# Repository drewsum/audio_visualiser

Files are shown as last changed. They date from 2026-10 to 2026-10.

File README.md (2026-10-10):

# Audio Visualizer

## Hardware

A graphical EQ display, based on a dsPIC33AK256MPS103 digital signal controller.

## Continuous integration

GitHub Actions checks every KiCad project under `hdw/` automatically (`.github/workflows/hardware.yml`):

| Job | What it does |
|---|---|
| Repo hygiene | Fails on committed backups, lock files or caches, and on files not saved by KiCad 10.0. Checks that each project's schematic PDF (`<project>.pdf`) is committed and was re-plotted after the last schematic change. |
| ERC / DRC / libraries | Runs ERC, and DRC with schematic parity. Also checks that every symbol and footprint library resolves on a clean machine (project lib tables must use `${KIPRJMOD}`). For projects with a project library, checks that every placed symbol, footprint and 3D model comes from it. |
| Visual diff | On every run, renders changed schematic pages and PCB layers against the previous commit or PR base (red = removed, green = added). The result is a single `visual-diff.html` artifact that opens directly in the browser; the run summary links to it. |

Per-project settings live in `hdw/ci-config.json`. Each of `erc`, `drc`, `libraries`, `project_lib` and `pdf` is `enforce` (fail the build), `report` (annotate only) or `off`. `project_lib` also needs `project_lib_dir` (relative to the project folder, e.g. `"../../../project_lib"`): the lib tables may only point into that folder, every placed symbol and board footprint (and every symbol's Footprint field) must exist in those libraries, and every 3D model path must resolve to a file inside it. ERC/DRC items excluded in KiCad are not counted. Personal libraries that aren't in this repo are listed under `external_libraries` and cloned by CI under the same nicknames.

To run the checks locally:

```sh
KICAD_CLI="C:/Program Files/KiCad/10.0/bin/kicad-cli.exe" python tools/ci/kicad_ci.py check hdw/DSP_board/rev_a/Audio_Visualiser_DSP
python tools/ci/kicad_ci.py hygiene
```

Fab outputs (schematic/PCB PDFs, Gerbers + drill, IPC-D-356, BOM, pick-and-place, STEP and renders) are built manually:

```sh
python tools/ci/kicad_ci.py outputs hdw/DSP_board/rev_a/Audio_Visualiser_DSP --out fab-out --label <version>
```

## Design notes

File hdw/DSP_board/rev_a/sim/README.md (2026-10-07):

# Audio Signal Chain Simulation

## Trace Legend

| Color  | Signal |
|---|---|
| Red | Time Domain RCA Audio Signal (1.8Vpp) |
| Green  | Frequency Domain RCA Audio Signal |
| Blue | Time/Frequency Domain ADC Audio Signal |
| Orange | Time Domain Speaker Level Audio Signal (12Vpp) |
| Yellow | Frequency Domain Speaker Level Audio Signal |

## RCA Input

### Time Domain
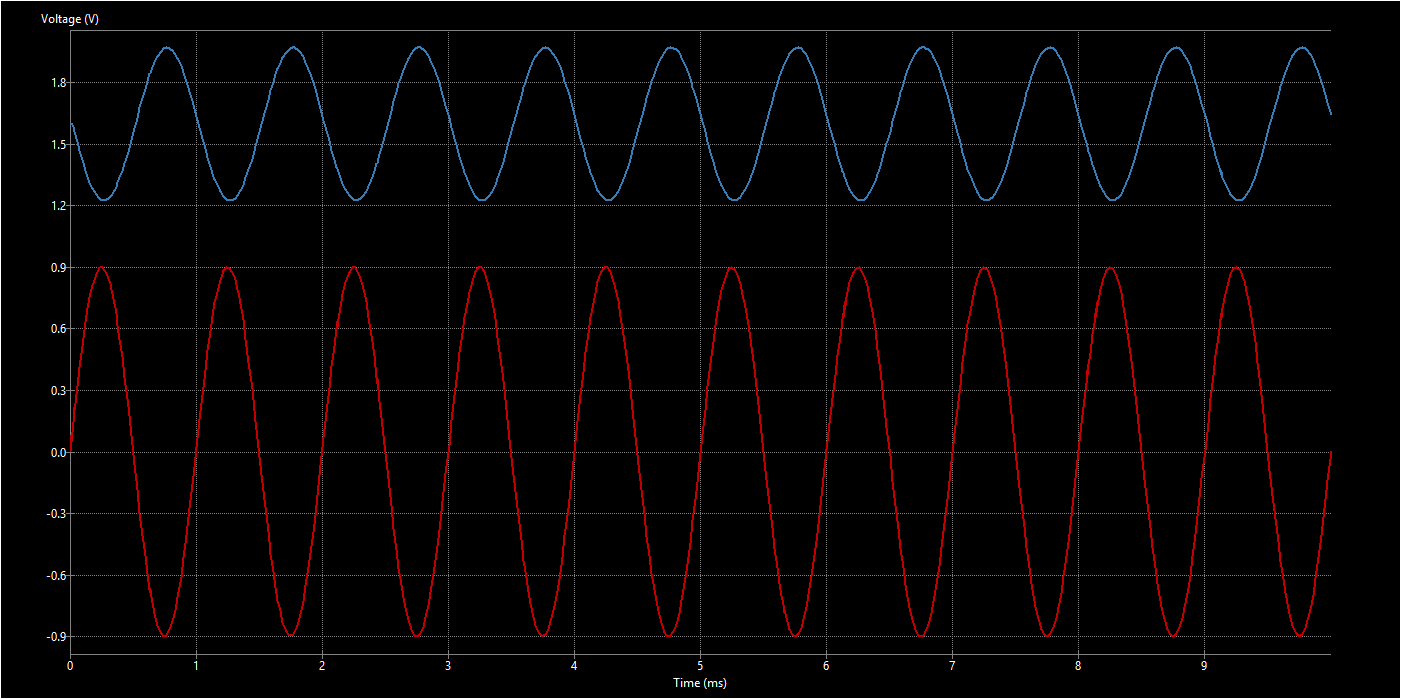
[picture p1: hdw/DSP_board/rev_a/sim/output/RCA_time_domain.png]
RCA Time Domain


### Frequency Domain
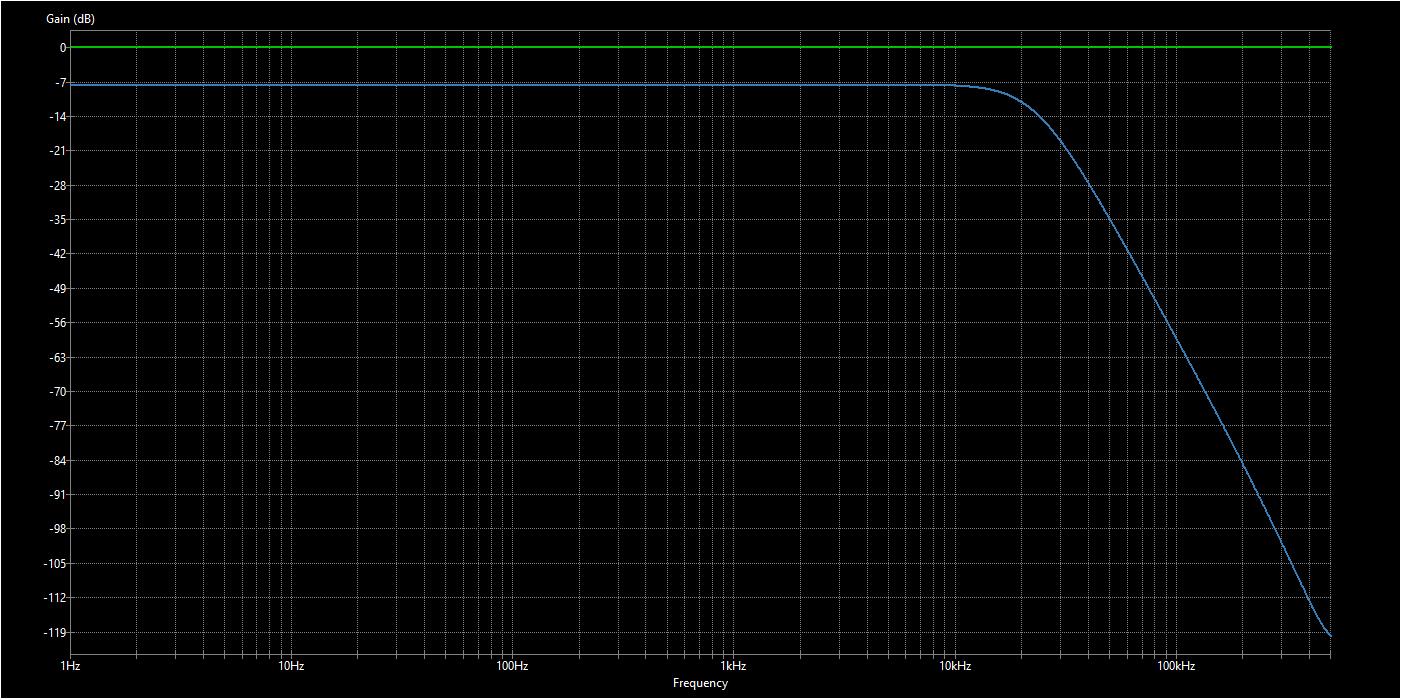
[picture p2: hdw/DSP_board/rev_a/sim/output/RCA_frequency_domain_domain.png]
RCA Frequency Domain


## Speaker Level Input

### Time Domain
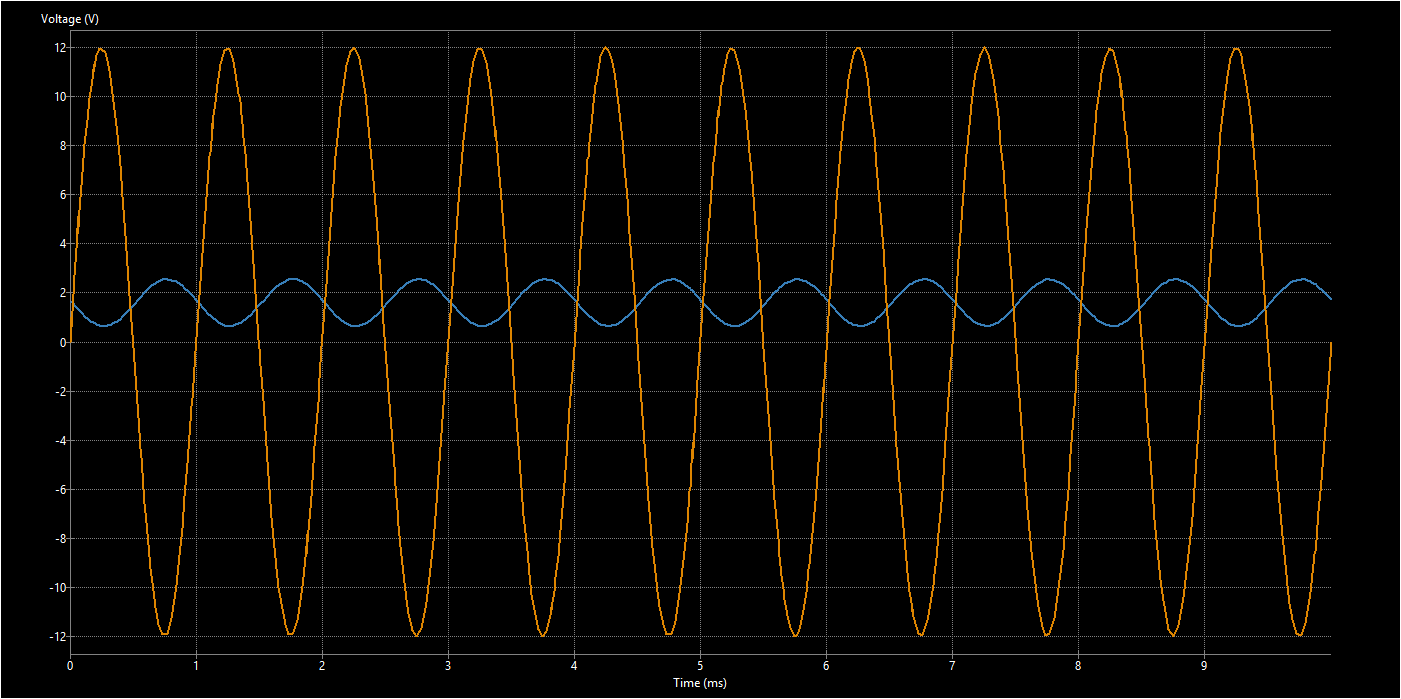
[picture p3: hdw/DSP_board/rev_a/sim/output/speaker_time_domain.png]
Speaker Time Domain


### Frequency Domain
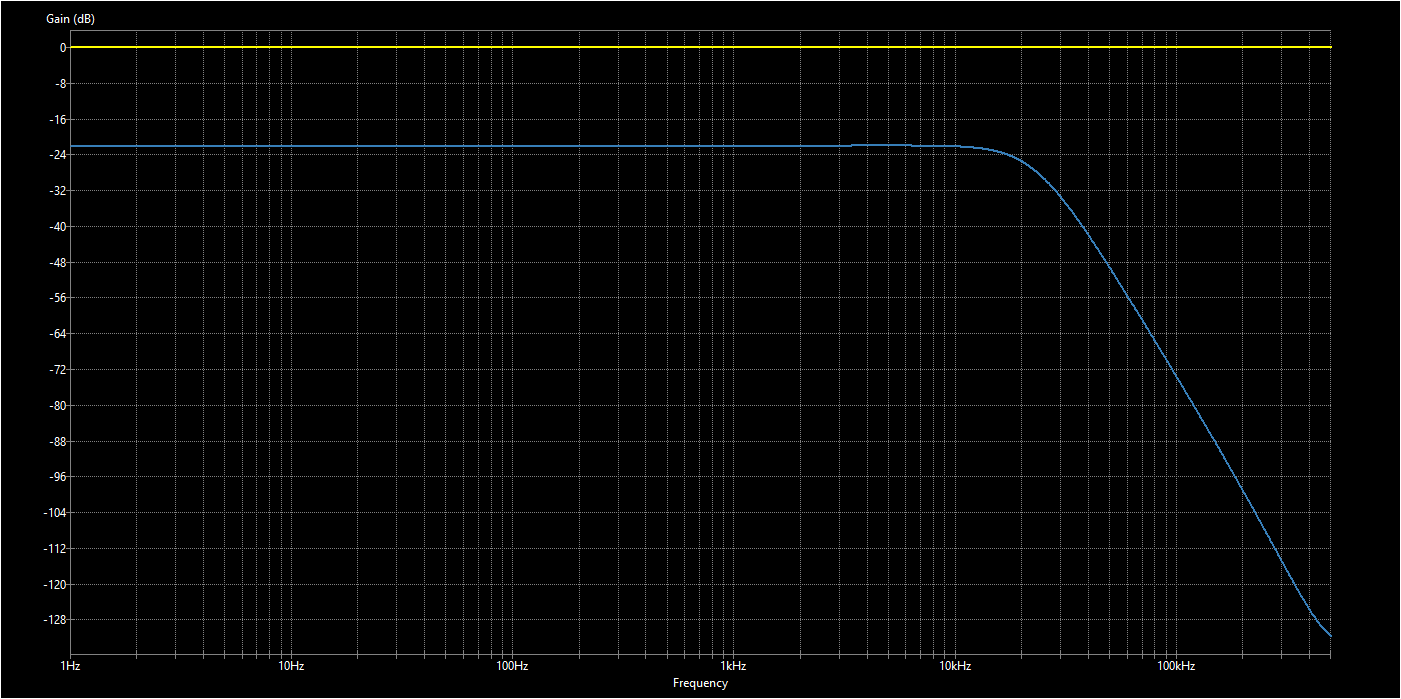
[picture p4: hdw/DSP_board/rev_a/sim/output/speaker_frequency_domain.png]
Speaker Frequency Domain


All sims were run with digipot code = 128 (wiper -> midpoint), meaning the PGAs are not attenuating or amplifying the signal at all, merely inverting

The signal chain employs the following vendor spice models:
* BAT54SW.lib
* MCP4451.lib
* MCP6021_MCP6024.lib
* MCP6N11.lib
* REF35.lib
* SD15C.lib
* TS3A24159.lib

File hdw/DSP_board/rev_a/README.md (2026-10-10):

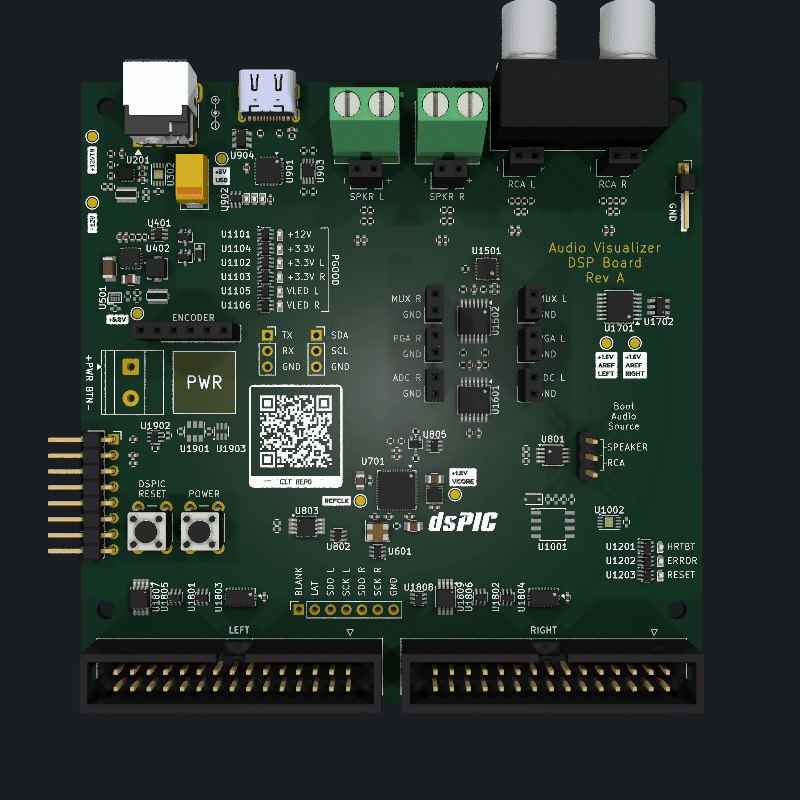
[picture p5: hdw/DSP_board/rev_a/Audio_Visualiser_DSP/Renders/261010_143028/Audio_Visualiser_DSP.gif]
Render


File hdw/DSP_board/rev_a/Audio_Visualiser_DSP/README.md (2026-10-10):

Render

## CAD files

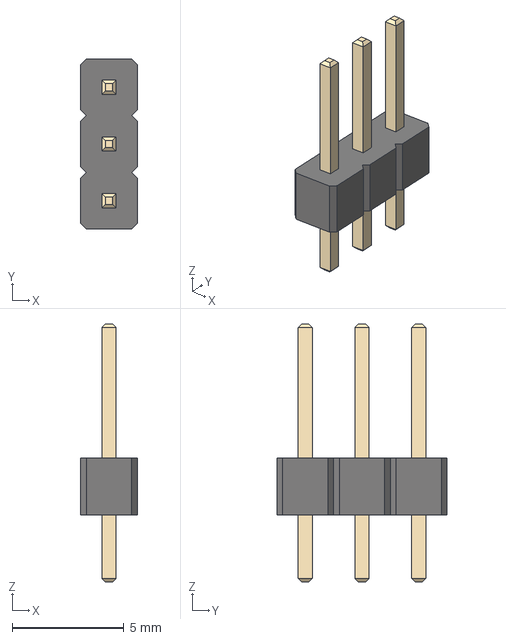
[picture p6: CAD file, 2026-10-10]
hdw/project_lib/3d_models/PinHeader_1x03_P2.54mm_Vertical.step
2.54 x 7.62 x 11.5 mm

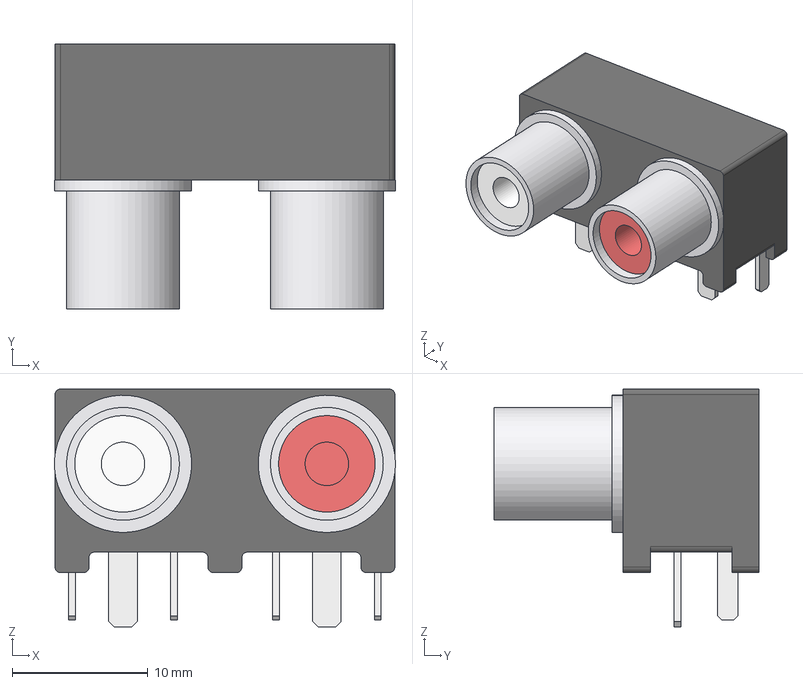
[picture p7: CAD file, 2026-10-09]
hdw/project_lib/3d_models/Switchcraft_PJRAN2X1U01X.step
25.1 x 19.5 x 17.5 mm
housing
insert_A_red
insert_B_white
terminals

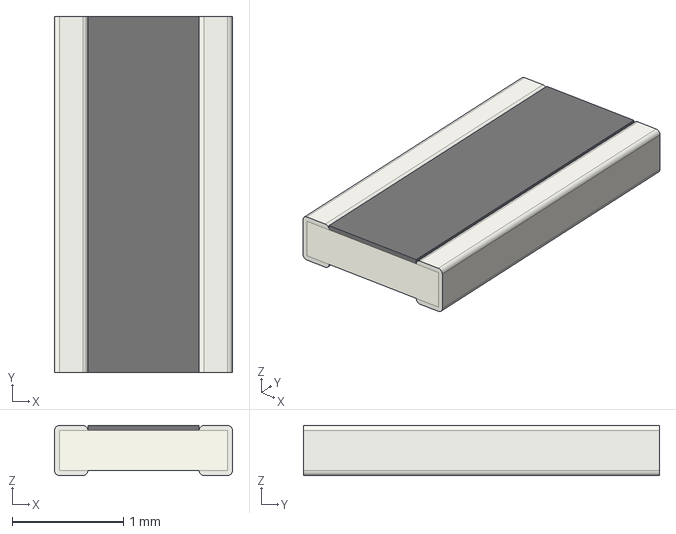
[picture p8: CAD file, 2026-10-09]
hdw/project_lib/3d_models/R_0612_1632Metric.step
1.60 x 3.20 x 0.45 mm

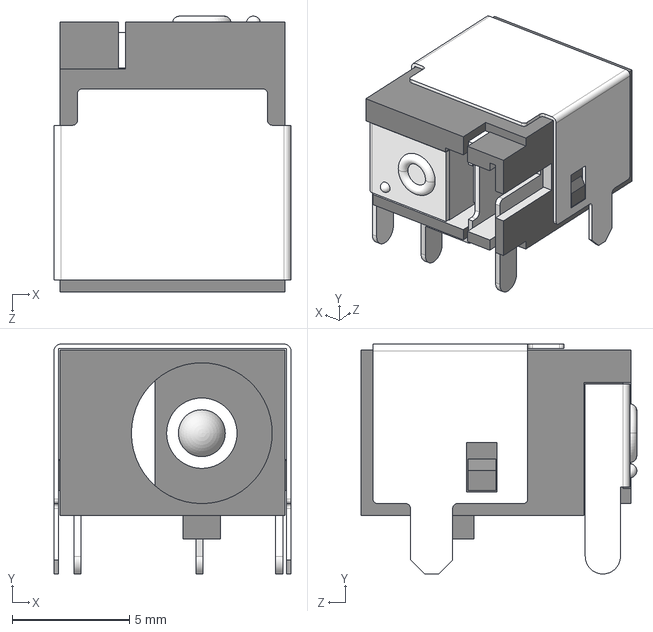
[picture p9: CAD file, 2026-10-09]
hdw/project_lib/3d_models/SameSky_PJ-051AH.step
10.1 x 9.80 x 11.8 mm

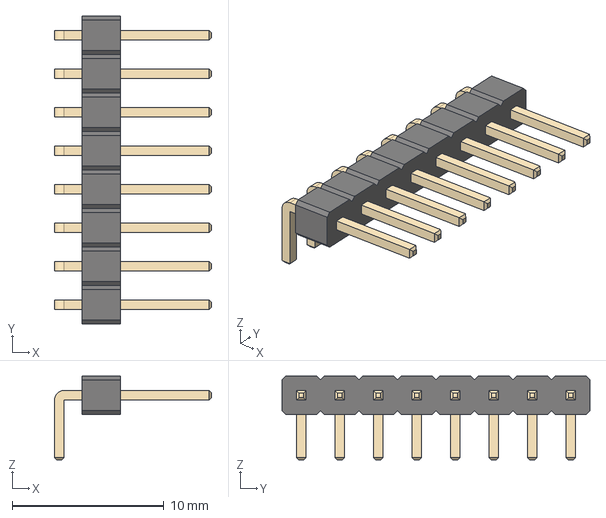
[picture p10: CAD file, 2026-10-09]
hdw/project_lib/3d_models/PinHeader_1x08_P2.54mm_Horizontal.step
10.4 x 20.3 x 5.54 mm

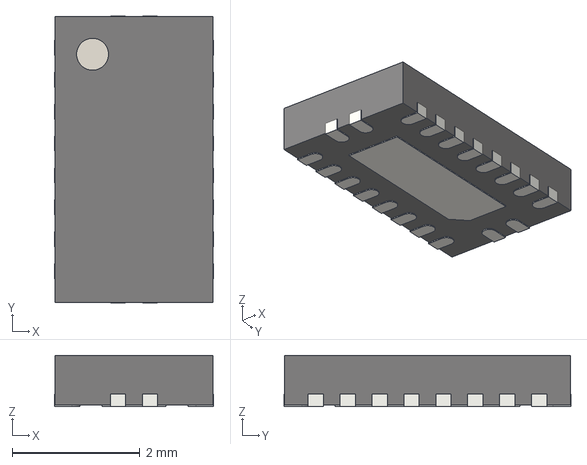
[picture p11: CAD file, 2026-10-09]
hdw/project_lib/3d_models/WQFN-20-1EP_2.5x4.5mm_P0.5mm_EP1x2.9mm.step
2.50 x 4.50 x 0.8 mm

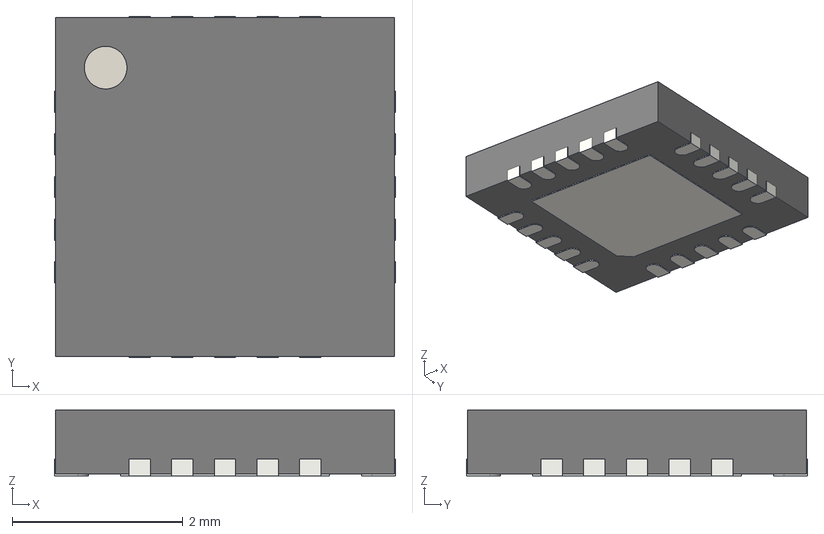
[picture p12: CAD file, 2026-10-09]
hdw/project_lib/3d_models/QFN-20-1EP_4x4mm_P0.5mm_EP2.5x2.5mm.step
4.00 x 4.00 x 0.77 mm

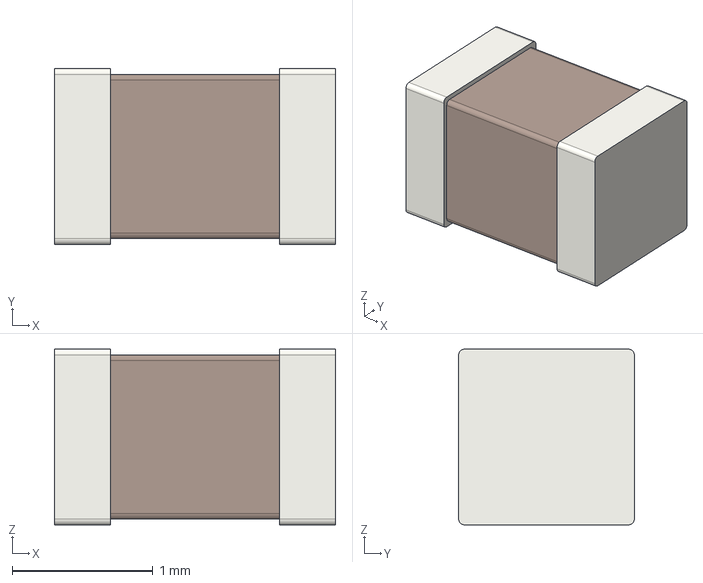
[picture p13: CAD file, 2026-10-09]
hdw/project_lib/3d_models/C_0805_2012Metric.step
2.00 x 1.25 x 1.25 mm

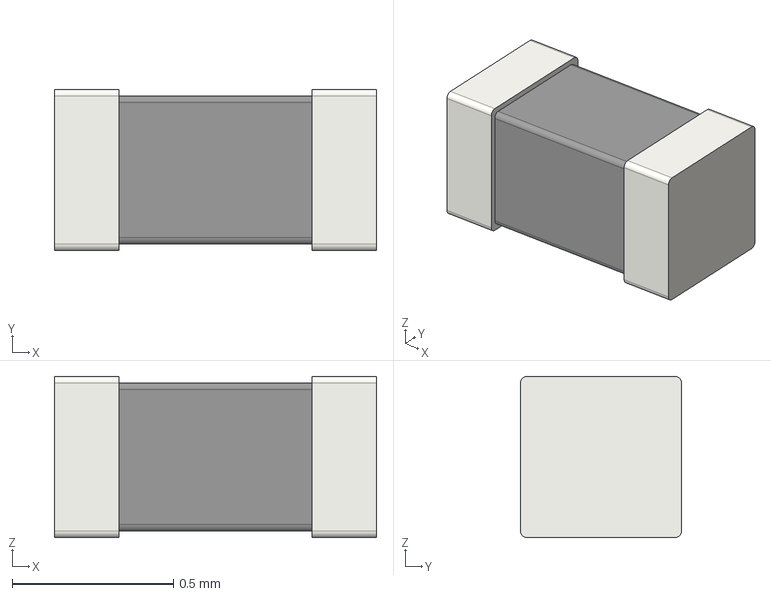
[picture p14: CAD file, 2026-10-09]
hdw/project_lib/3d_models/L_0402_1005Metric.step
1.00 x 0.5 x 0.5 mm

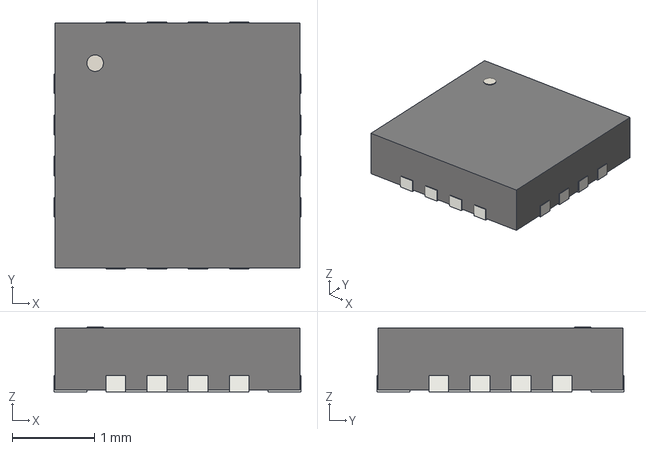
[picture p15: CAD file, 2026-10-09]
hdw/project_lib/3d_models/QFN-16-1EP_3x3mm_P0.5mm_EP1.7x1.7mm.step
3.00 x 3.00 x 0.785 mm

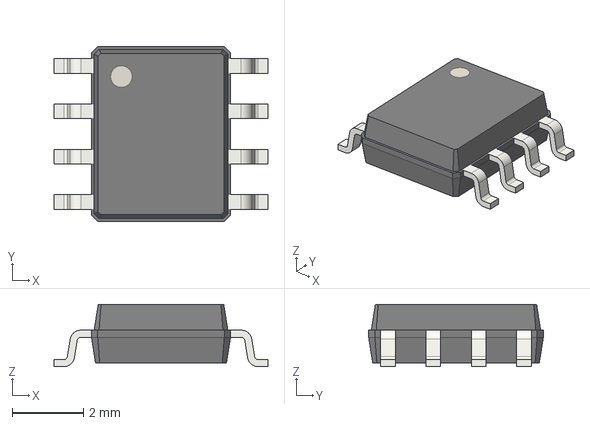
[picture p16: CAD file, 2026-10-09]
hdw/project_lib/3d_models/SOIC-8_3.9x4.9mm_P1.27mm.step
6.00 x 4.90 x 1.75 mm

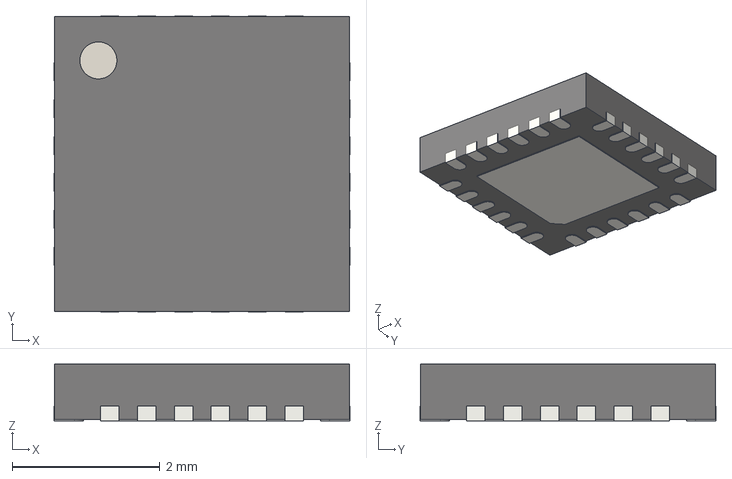
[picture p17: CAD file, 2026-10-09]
hdw/project_lib/3d_models/QFN-24-1EP_4x4mm_P0.5mm_EP2.6x2.6mm.step
4.00 x 4.00 x 0.77 mm

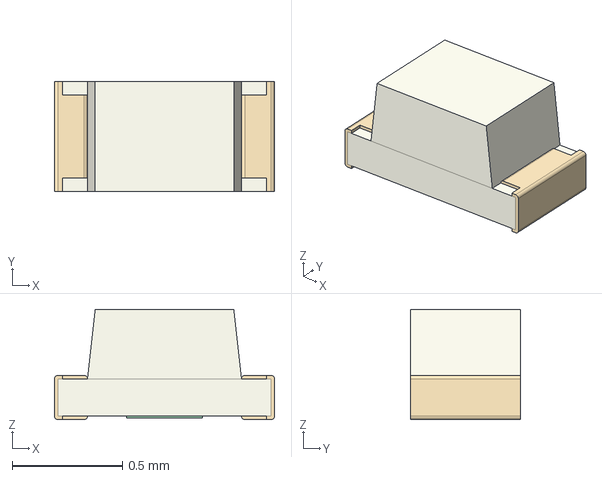
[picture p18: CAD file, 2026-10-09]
hdw/project_lib/3d_models/LED_0402_1005Metric.step
1.00 x 0.5 x 0.5 mm

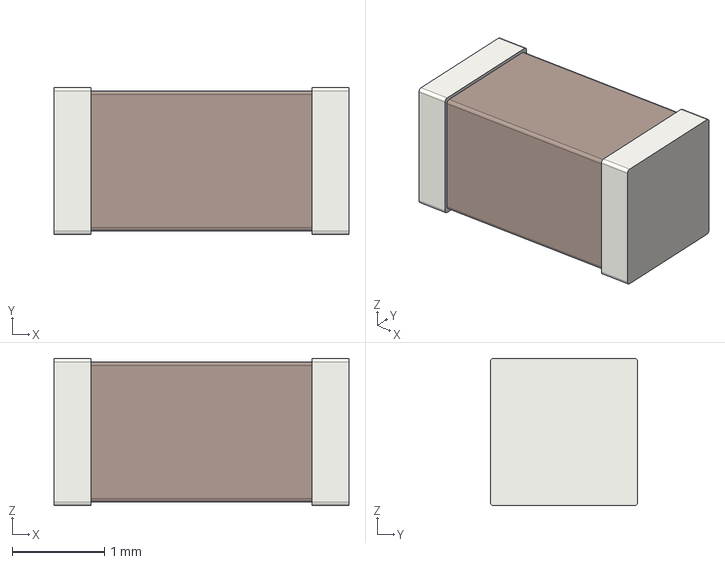
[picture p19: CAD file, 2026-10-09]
hdw/project_lib/3d_models/C_1206_3216Metric.step
3.20 x 1.60 x 1.60 mm

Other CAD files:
hdw/project_lib/3d_models/C_0402_1005Metric.step
hdw/project_lib/3d_models/Abracon_ASE_3.2x2.5mm.step
hdw/project_lib/3d_models/TI_TPS259474_RPW0010A.step
hdw/project_lib/3d_models/JAE_DX07S016JA1R1500.step
hdw/project_lib/3d_models/CP_EIA-7343-43_Kemet-X.step
hdw/project_lib/3d_models/DFN-8-1EP_3x2mm_P0.5mm_EP1.3x1.5mm.step
hdw/project_lib/3d_models/D_SMA.step
hdw/project_lib/3d_models/D_SOD-323.step
hdw/project_lib/3d_models/D_SOD-323F.step
hdw/project_lib/3d_models/IDC-Header_2x15_P2.54mm_Vertical.step
hdw/project_lib/3d_models/L_Vishay_IHLP-1212.step
hdw/project_lib/3d_models/L_Wuerth_PMCI-252012.step
hdw/project_lib/3d_models/PinHeader_1x01_P2.54mm_Horizontal.step
hdw/project_lib/3d_models/PinSocket_1x02_P2.54mm_Vertical.step
hdw/project_lib/3d_models/PinSocket_1x03_P2.54mm_Vertical.step
hdw/project_lib/3d_models/PinSocket_1x06_P2.54mm_Vertical.step
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

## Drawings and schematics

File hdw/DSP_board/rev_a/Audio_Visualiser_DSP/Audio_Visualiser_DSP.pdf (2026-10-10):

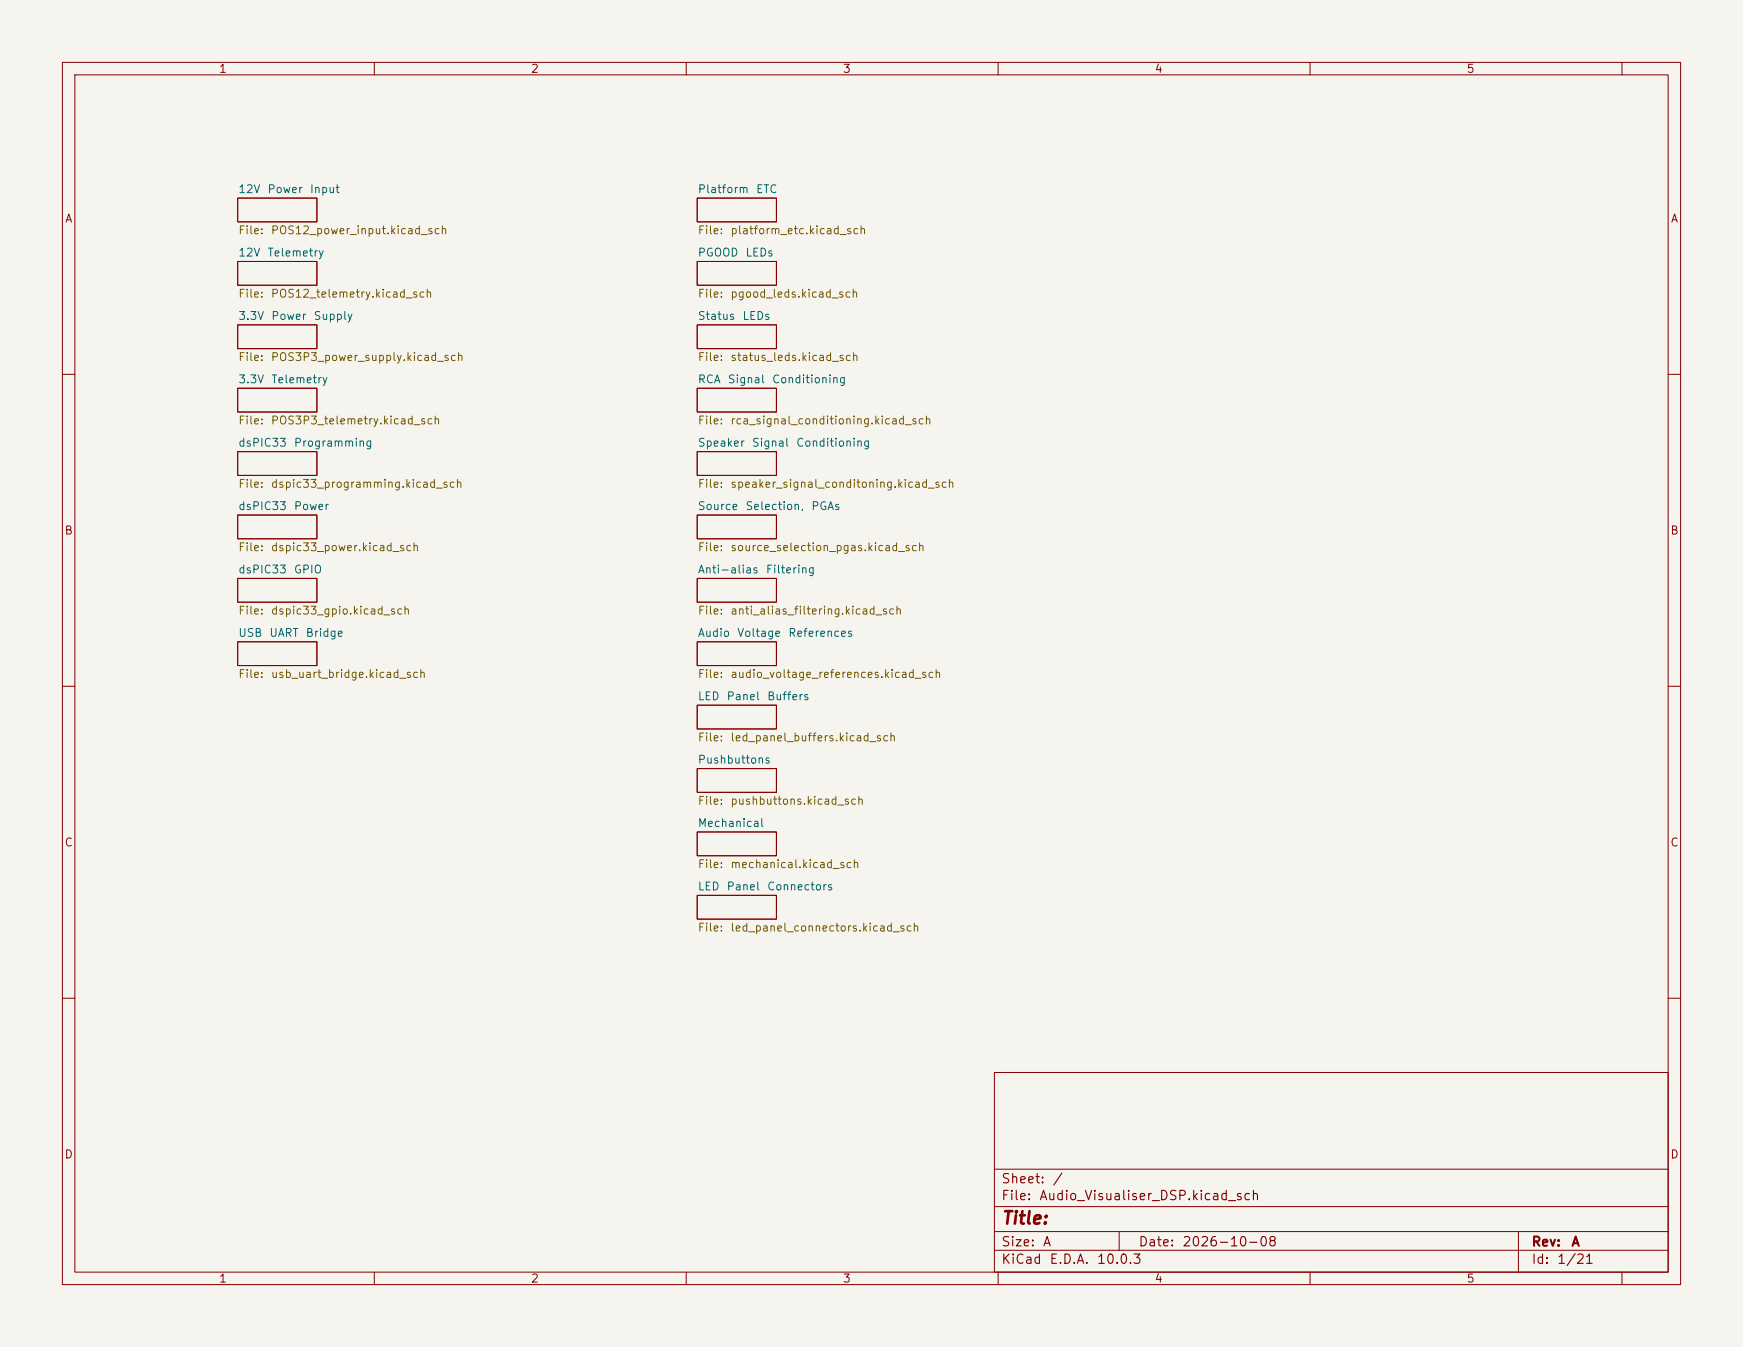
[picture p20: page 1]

Status LEDs File: status_leds.kicad_sch RCA Signal Conditioning

File: speaker_signal_conditoning.kicad_sch Source Selection, PGAs File: source_selection_pgas.kicad_sch

File: dspic33_gpio.kicad_sch USB UART Bridge

Audio Voltage References File: audio_voltage_references.kicad_sch Pushbuttons File: pushbuttons.kicad_sch

LED Panel Buffers File: led_panel_buffers.kicad_sch

LED Panel Connectors File: led_panel_connectors.kicad_sch

Size: A | Rev: A
KiCad E.D.A. 10.0.3 | Id: 1/21

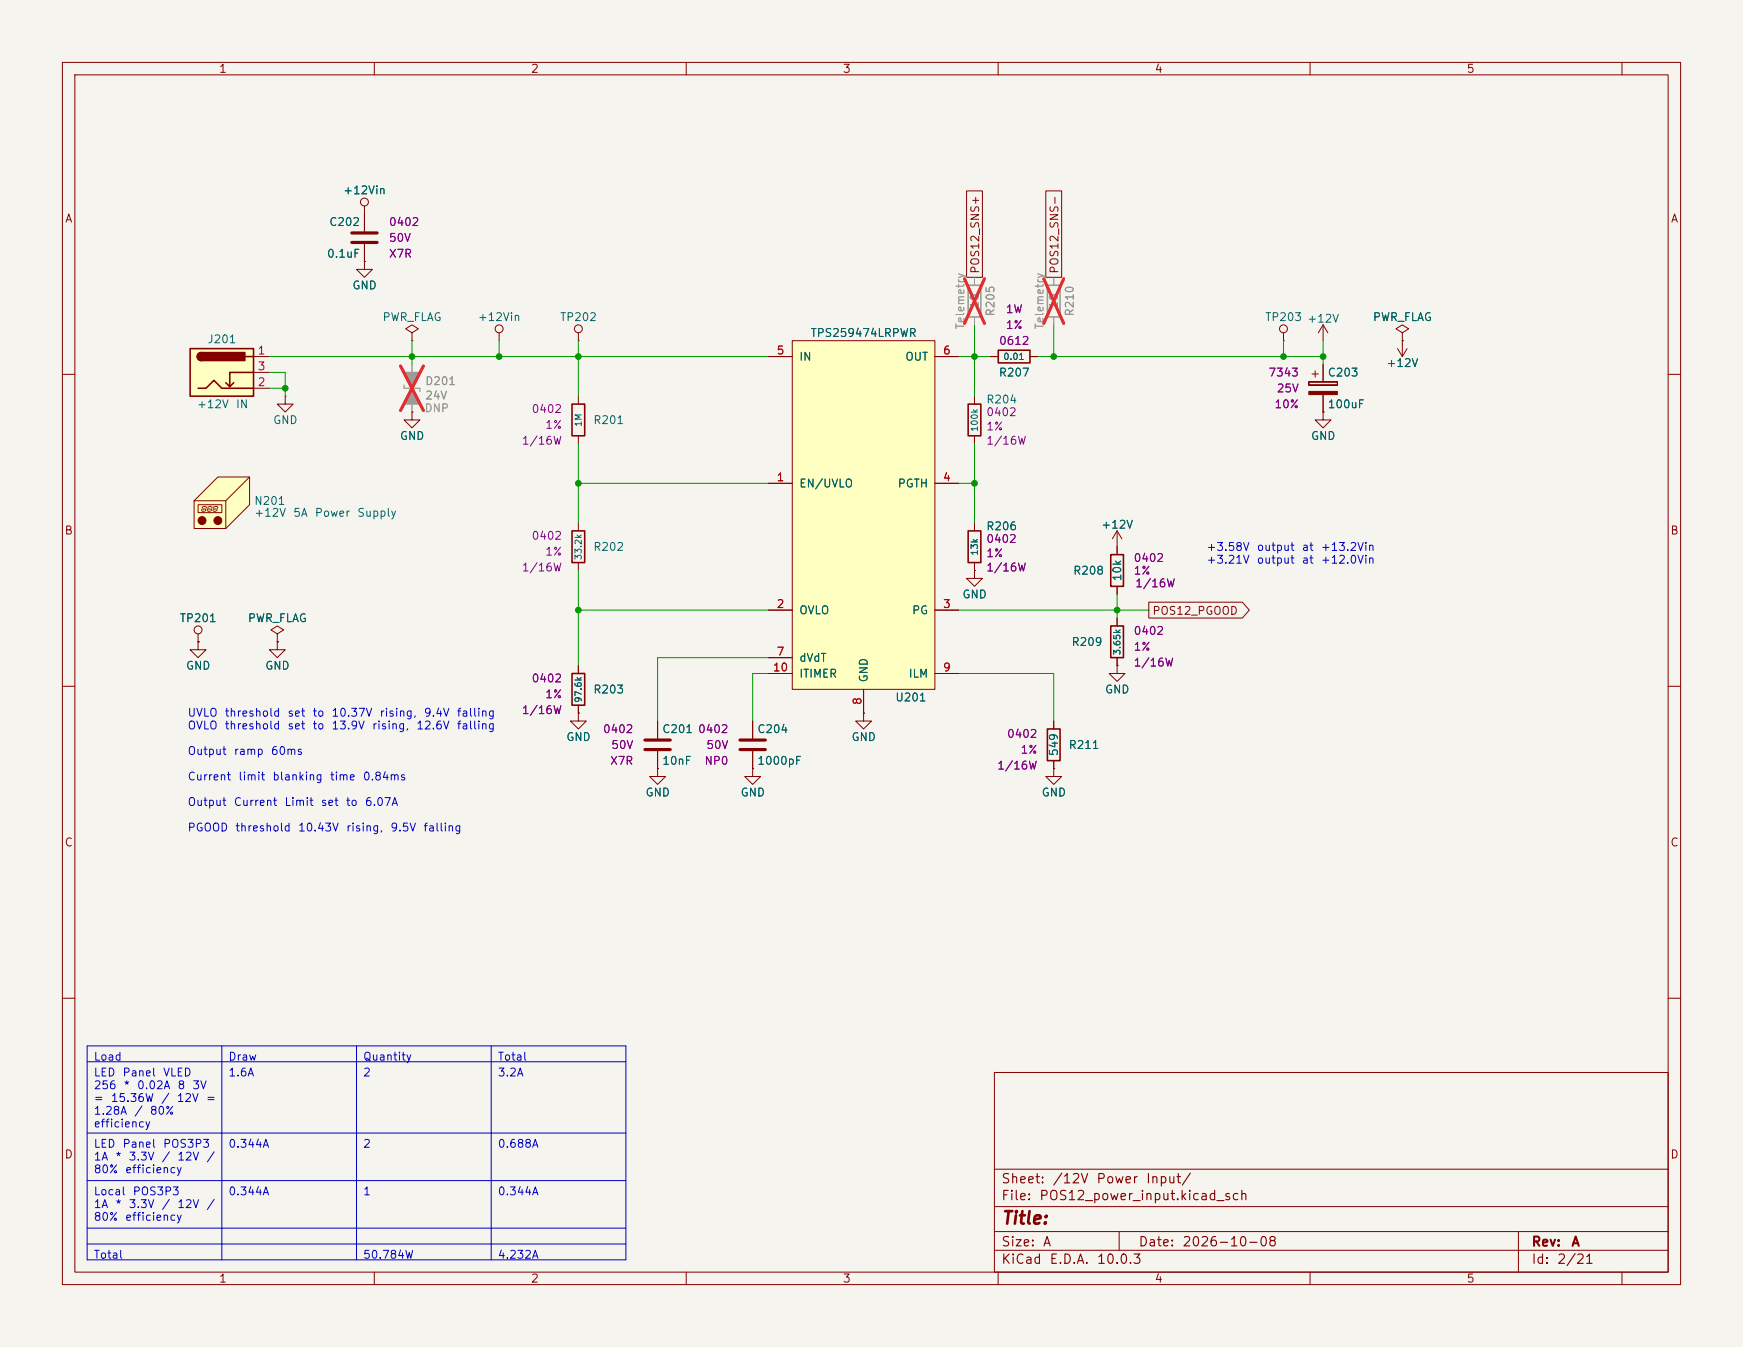
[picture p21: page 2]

Output ramp 60ms Current limit blanking time 0.84ms Output Current Limit set to 6.07A PGOOD threshold 10.43V rising, 9.5V falling D201

+3.58V output at +13.2Vin +3.21V output at +12.0Vin UVLO threshold set to 10.37V rising, 9.4V falling OVLO threshold set to 13.9V rising, 12.6V falling

Load | Draw | Quantity | Total LED Panel VLED
efficiency 256 * 0.02A 8 3V = 15.36W / 12V = 1.28A / 80% | 1.6A | 2 | 3.2A

LED Panel POS3P3 80% efficiency 1A * 3.3V / 12V / | 0.344A | 2 | 0.688A

Local POS3P3 80% efficiency 1A * 3.3V / 12V / | 0.344A | 1 | 0.344A

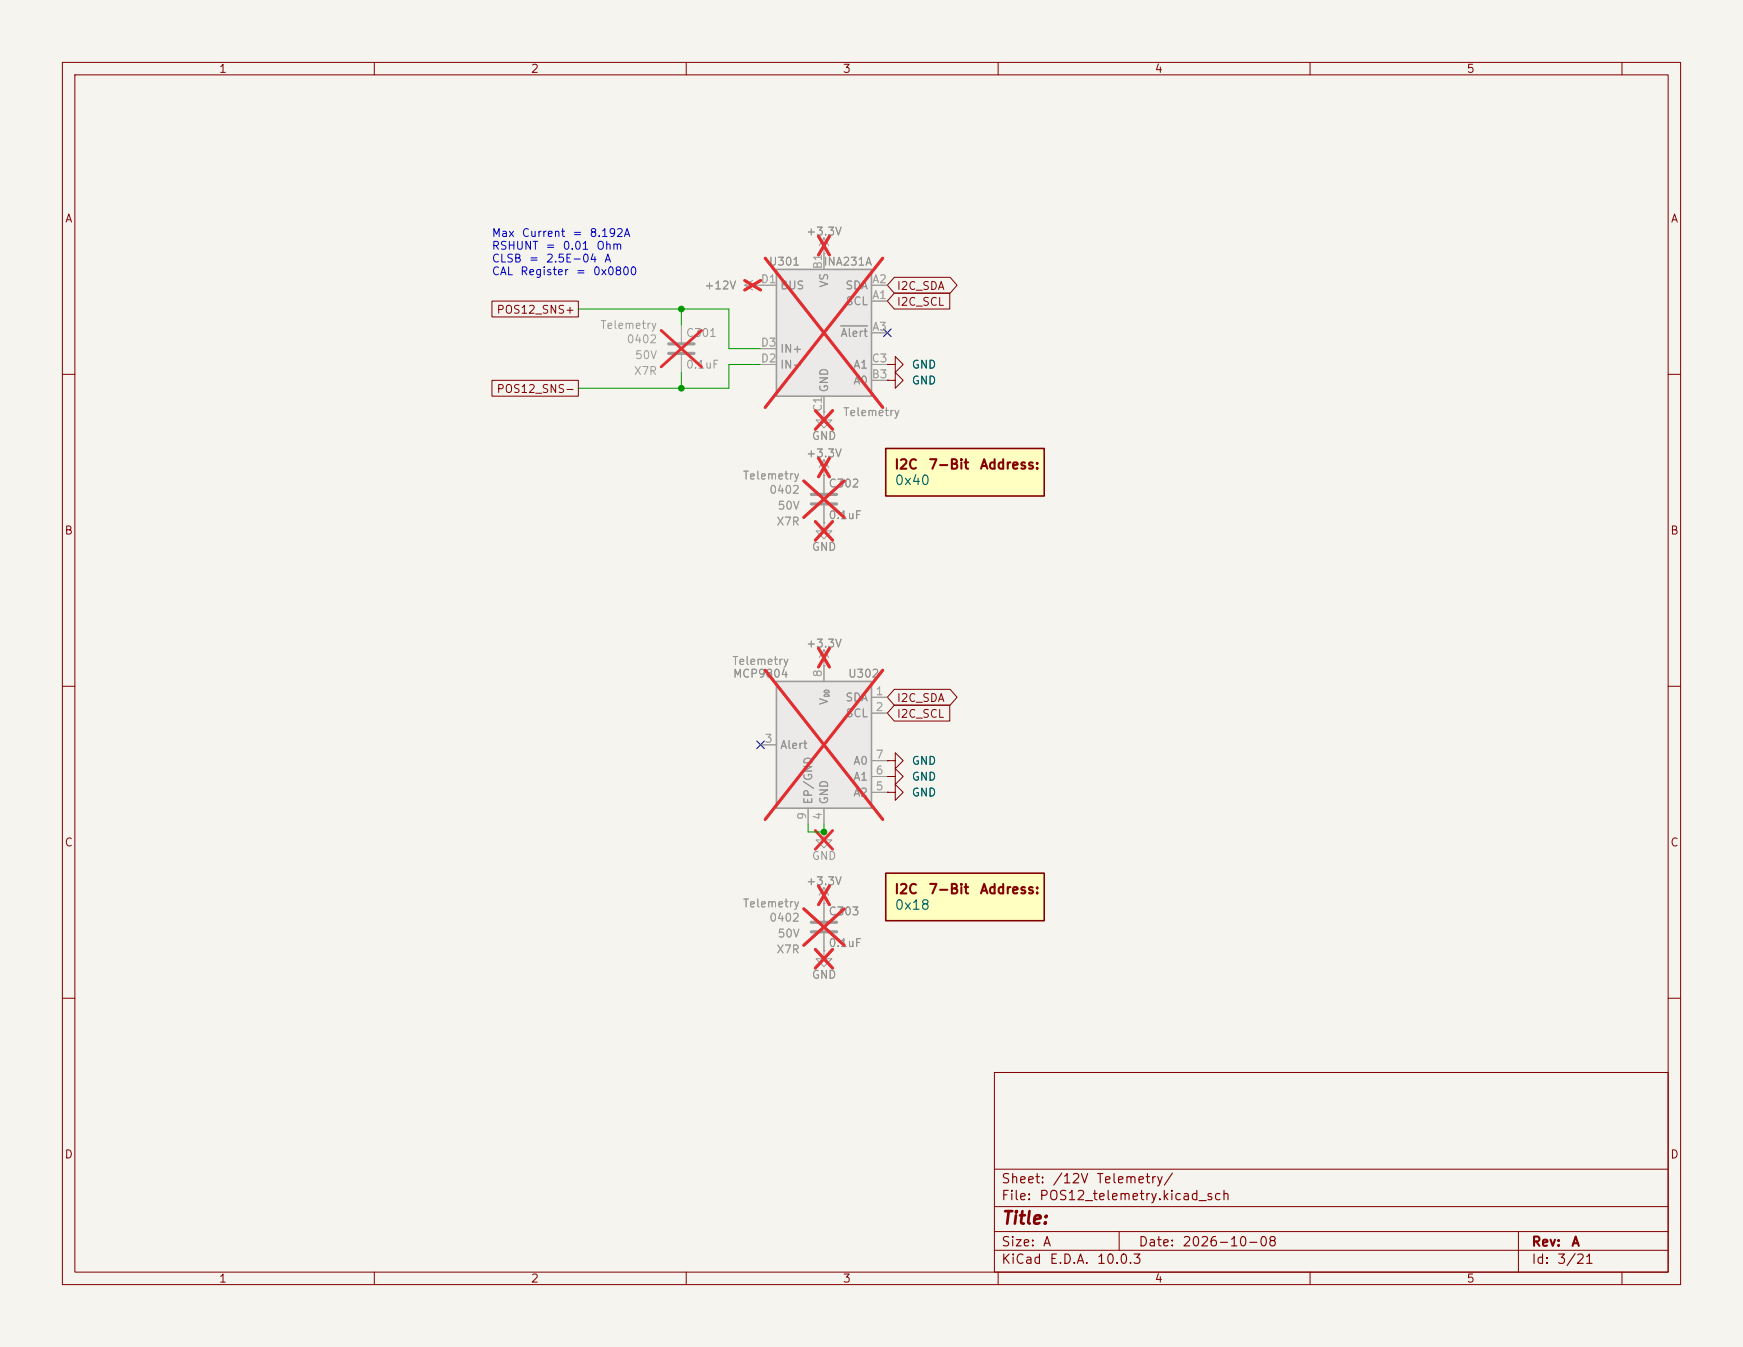
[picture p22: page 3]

I2C_SCL Max Current = 8.192A RSHUNT = 0.01 Ohm

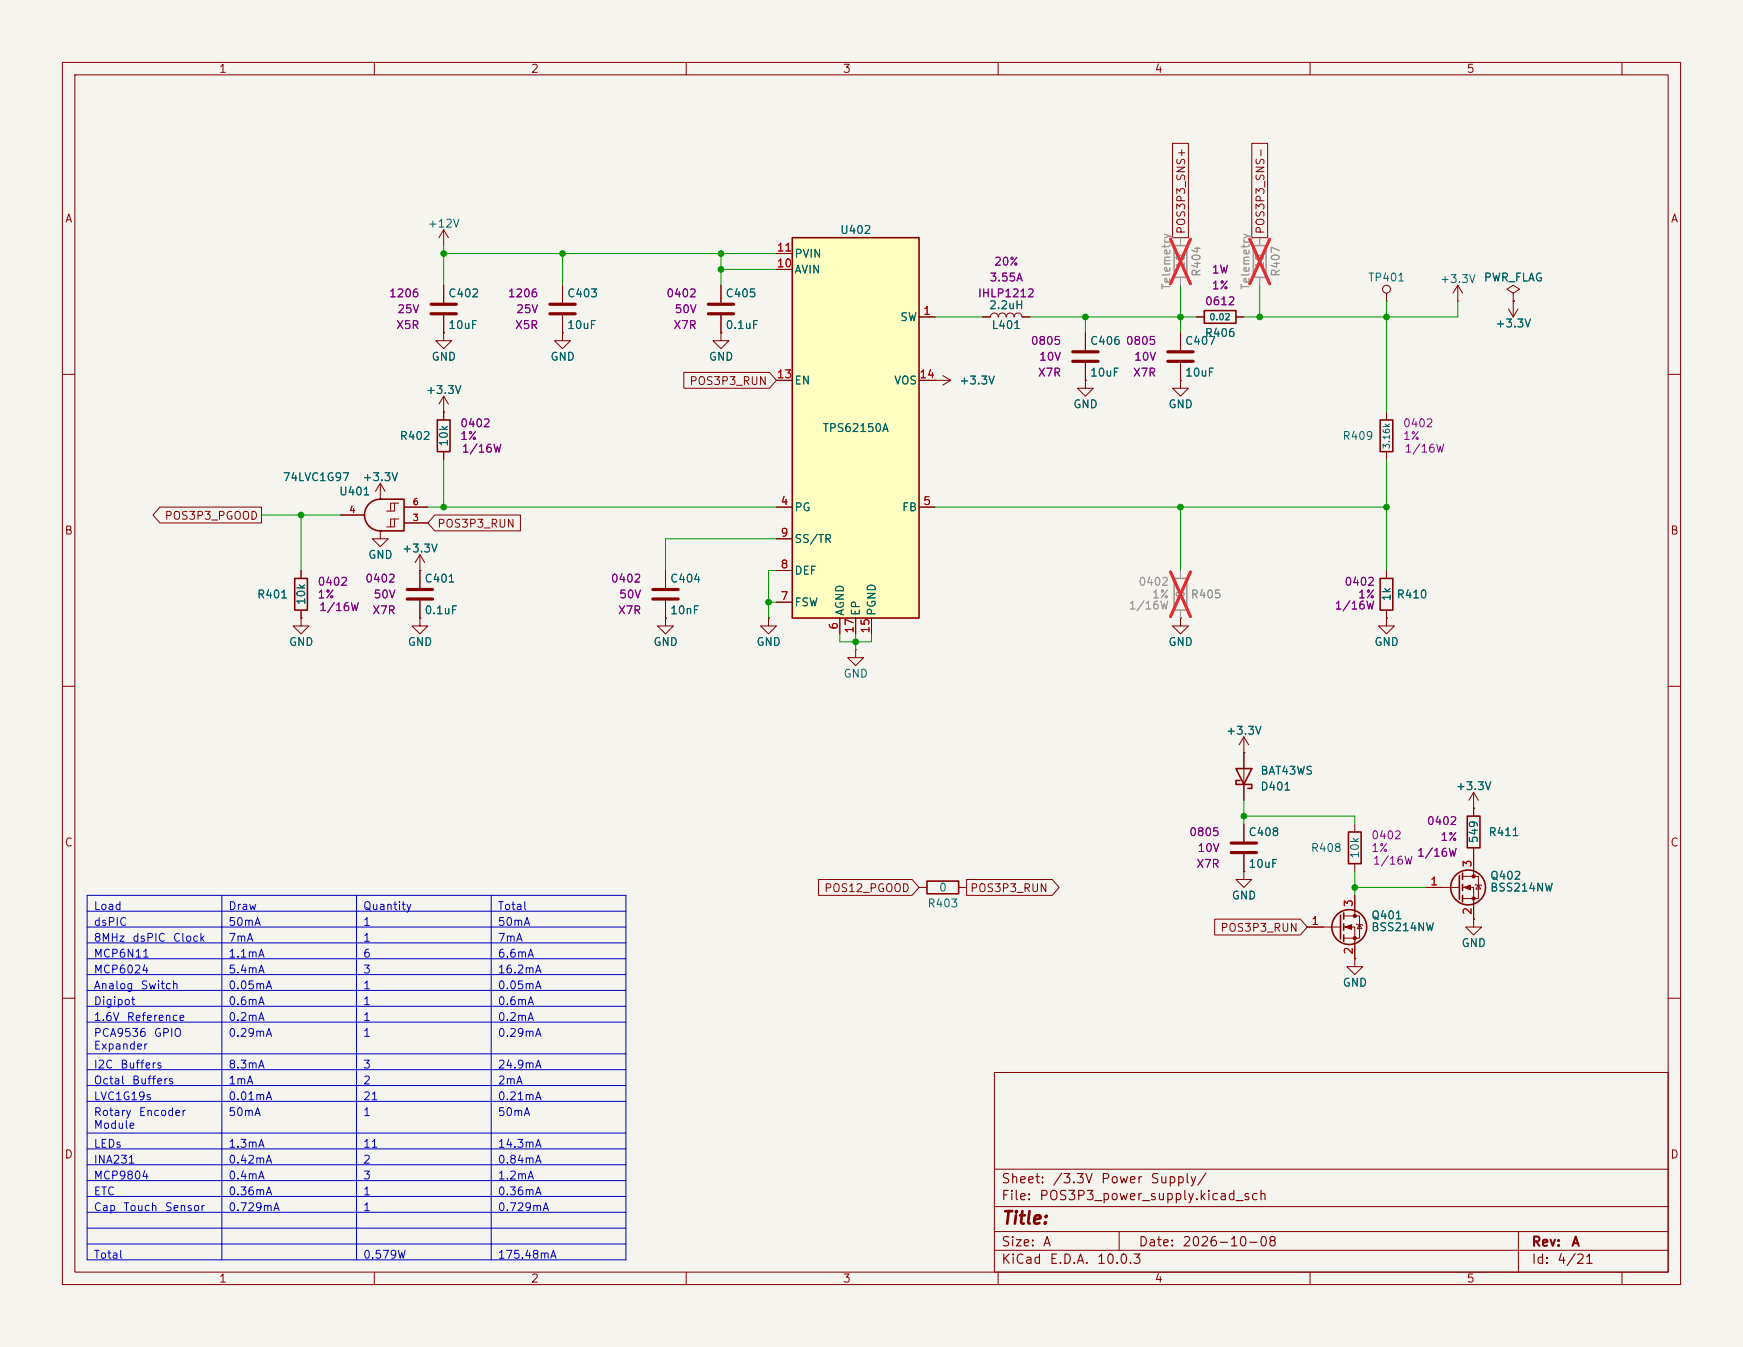
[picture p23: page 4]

FSW 7 DEF 8

Analog Switch | 0.05mA 0.6mA 0.2mA | 1 1 1 | 0.05mA Digipot 0.6mA 1.6V Reference 0.2mA PCA9536 GPIO

Expander | 0.29mA | 1 | 0.29mA

I2C Buffers | 8.3mA 1mA | 3 2 | 24.9mA Octal Buffers 2mA

LVC1G19s | 0.01mA 50mA | 21 1 | 0.21mA Rotary Encoder Module 50mA

LEDs | 1.3mA | 11 | 14.3mA

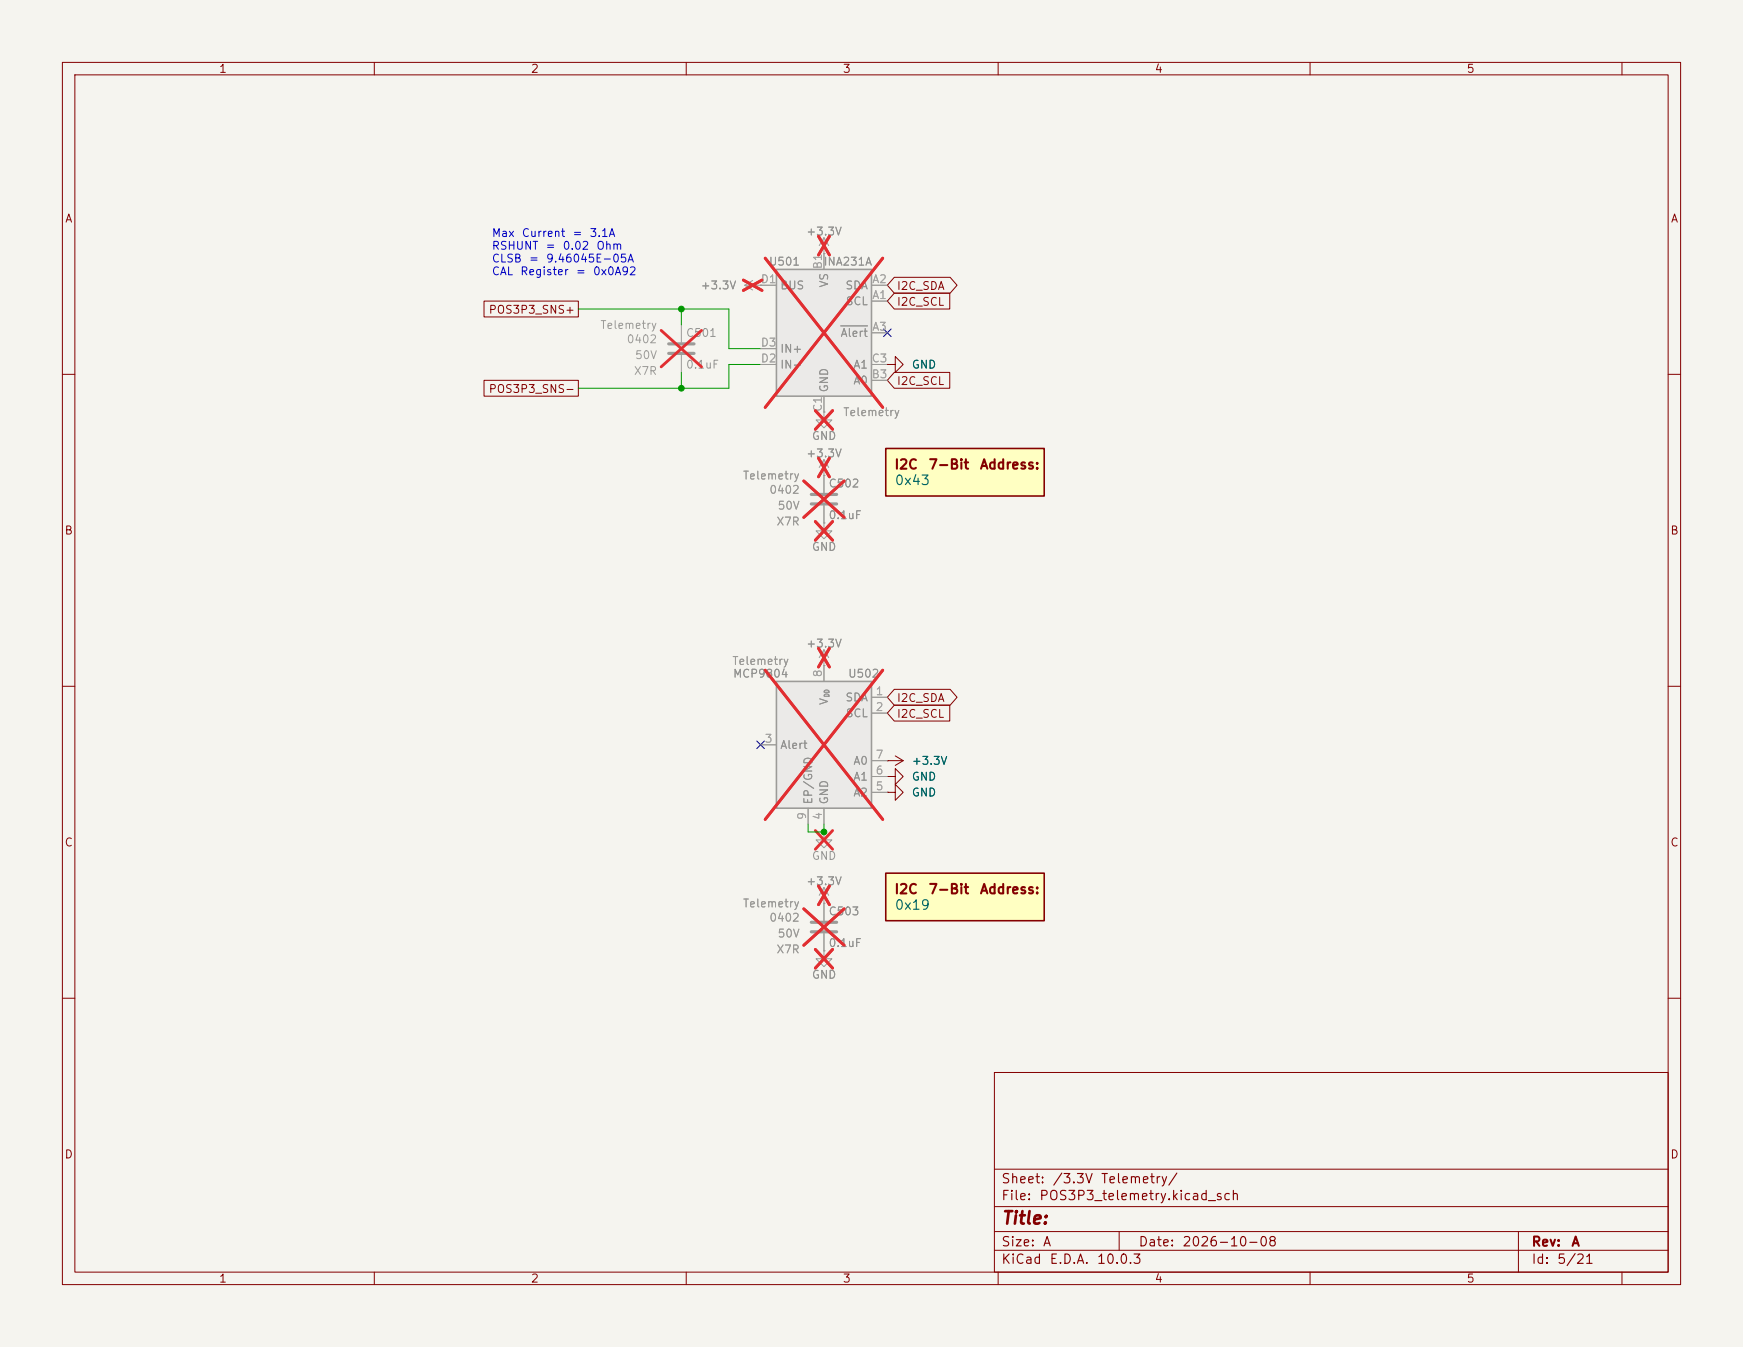
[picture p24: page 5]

I2C_SCL Max Current = 3.1A RSHUNT = 0.02 Ohm

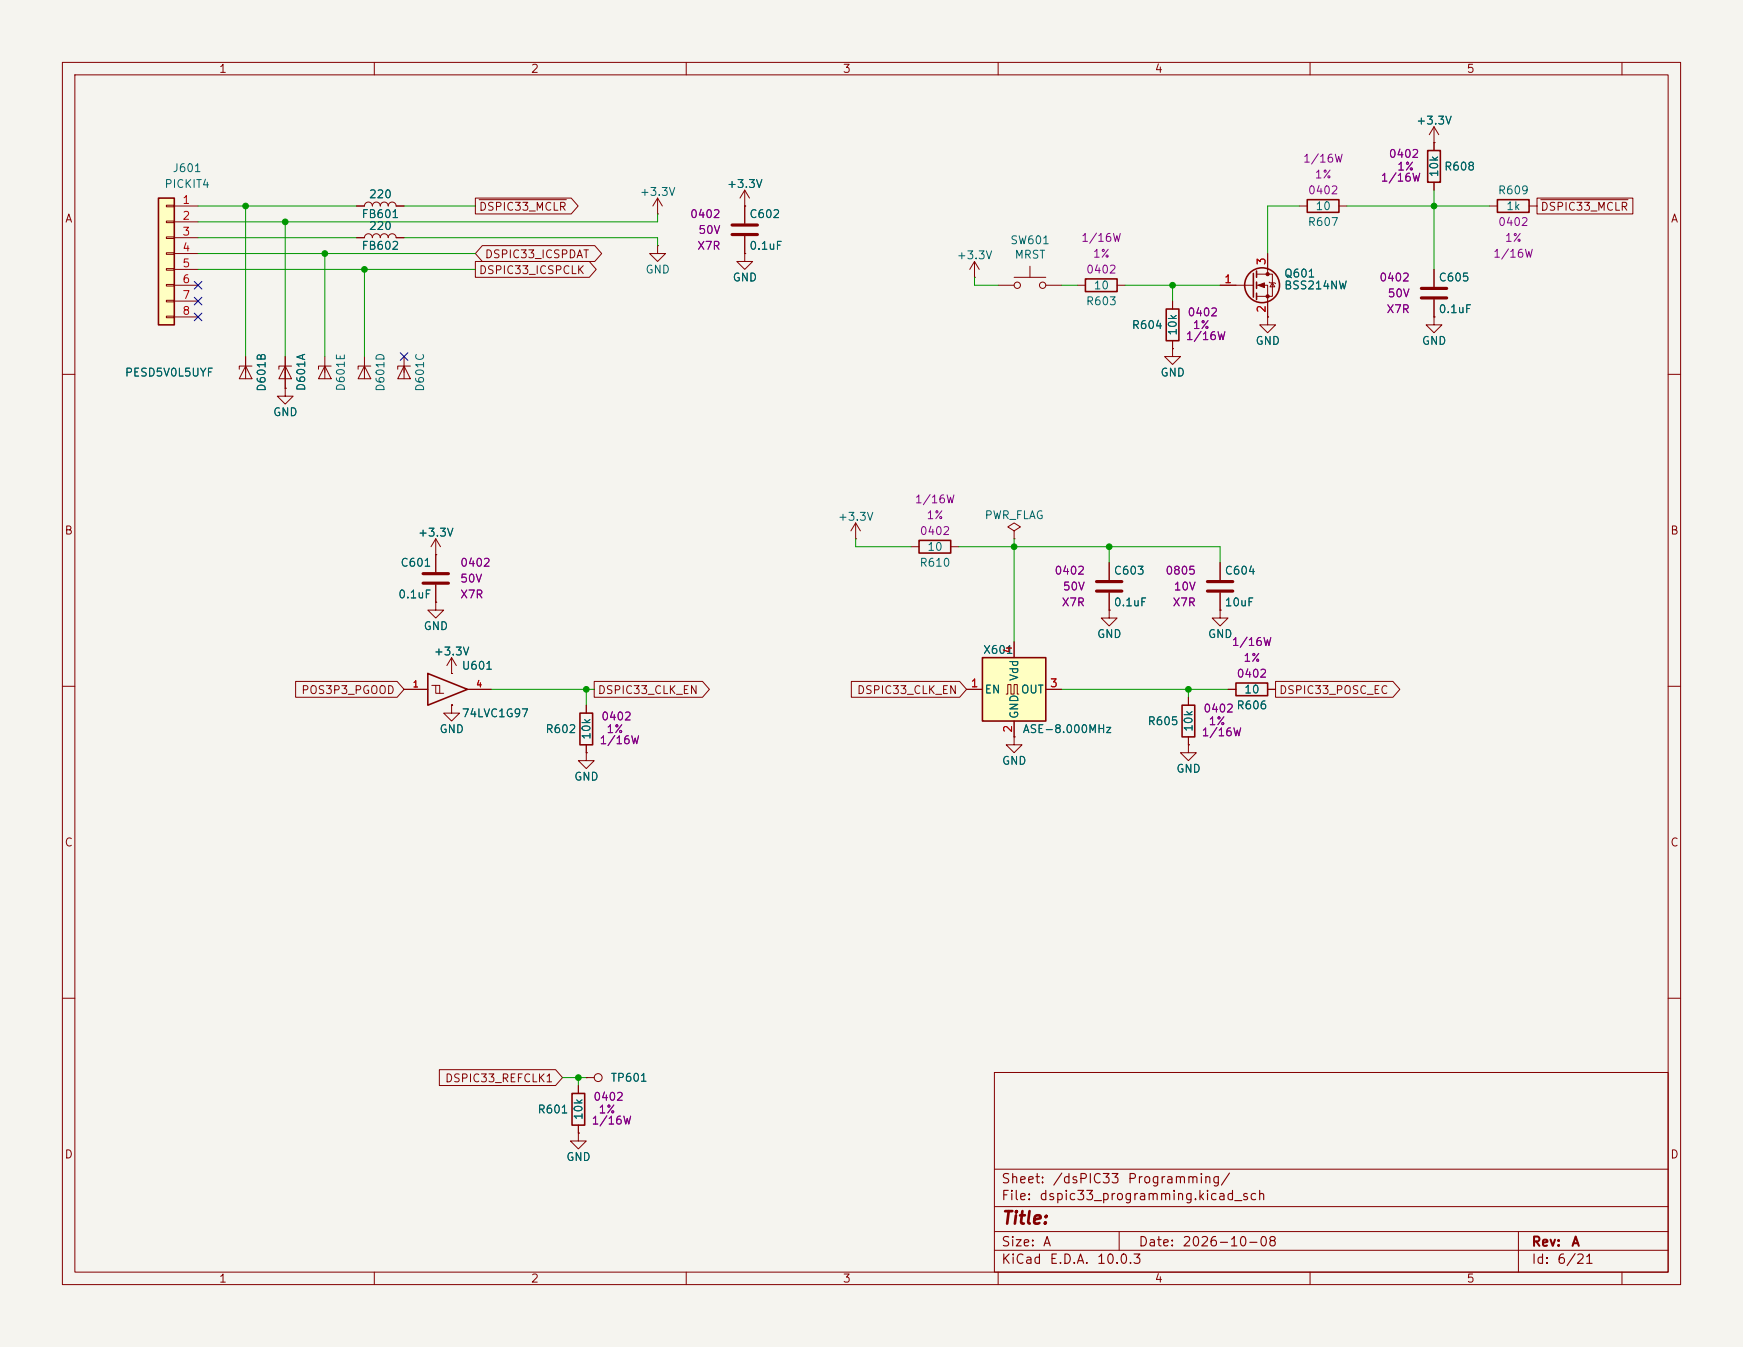
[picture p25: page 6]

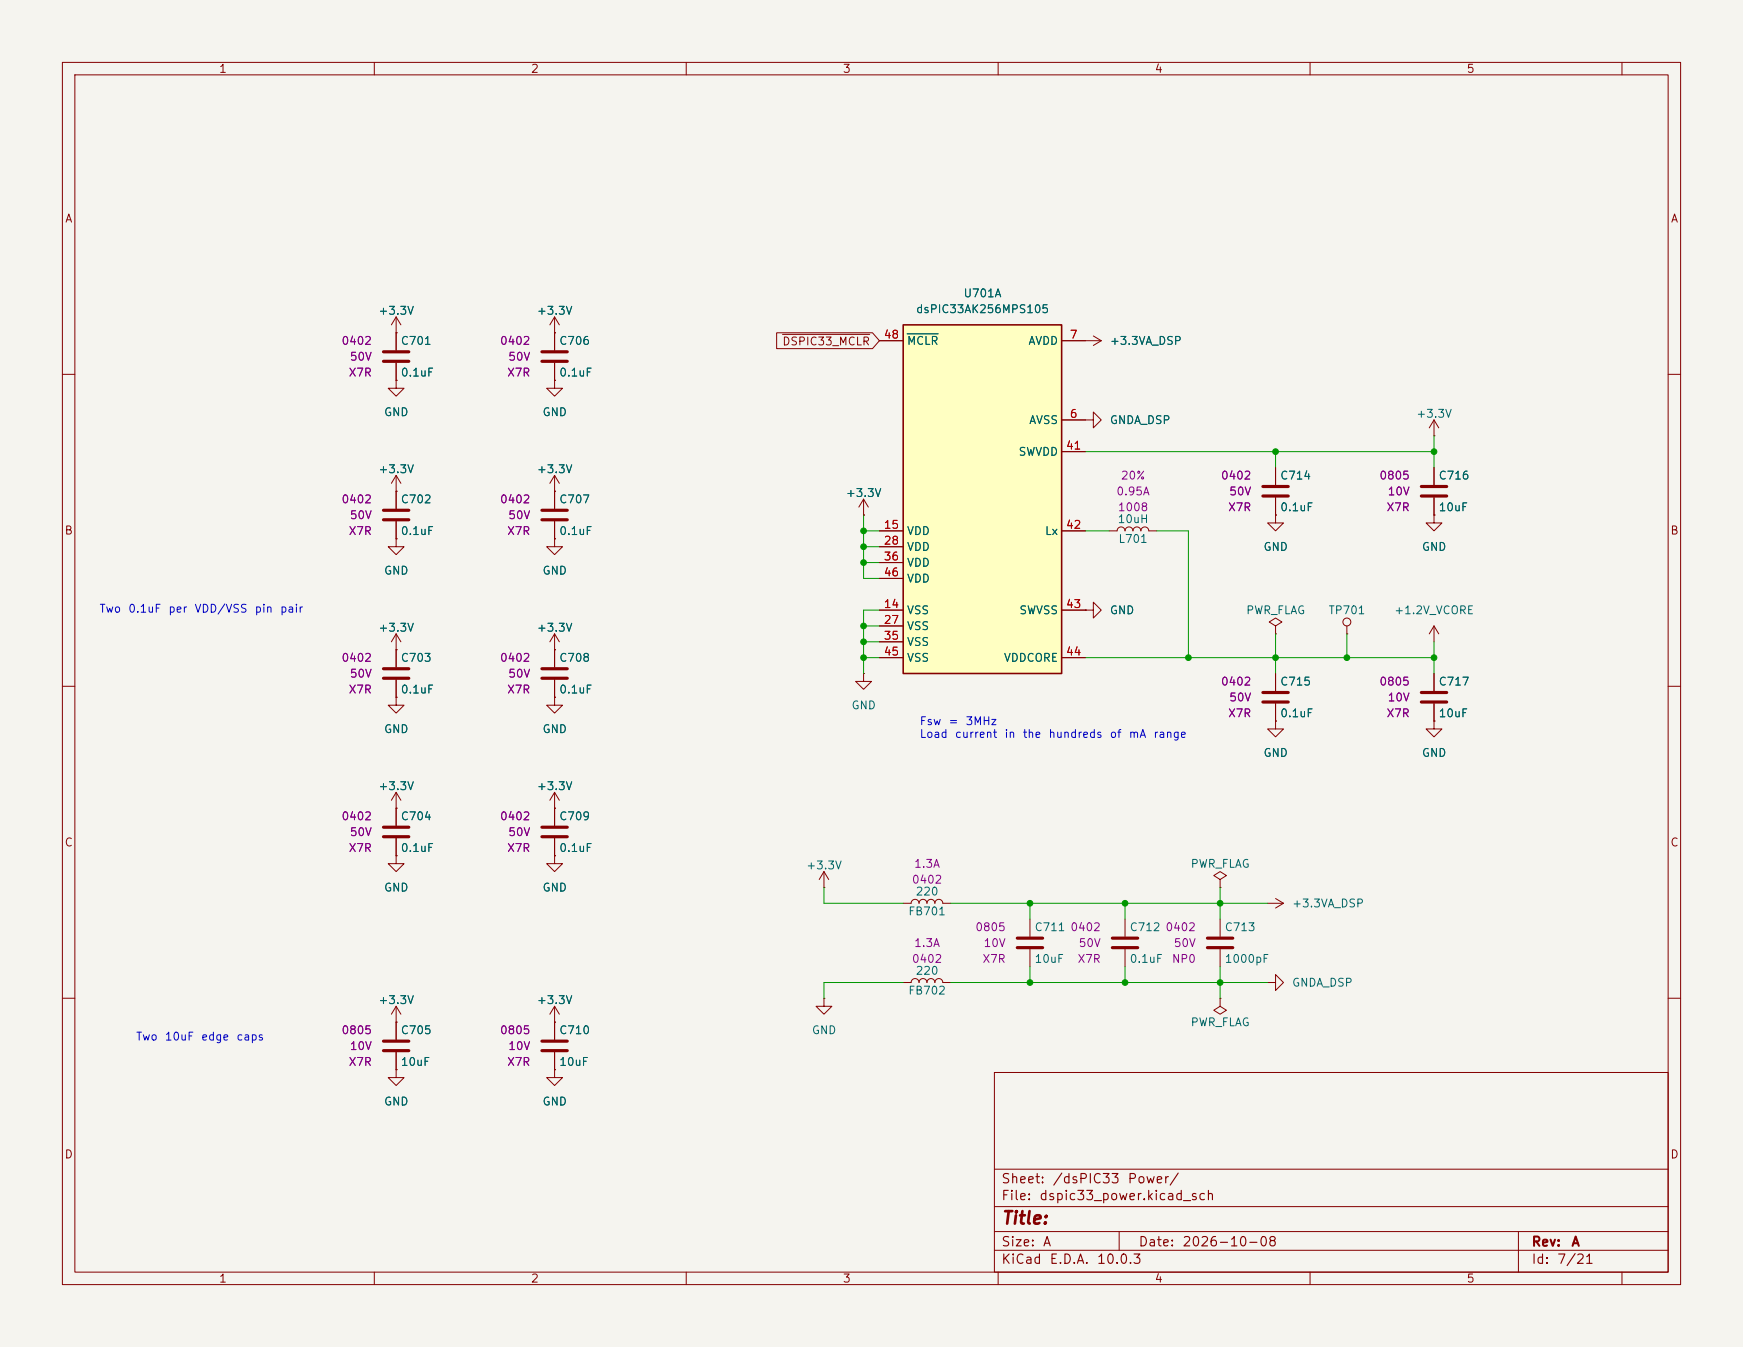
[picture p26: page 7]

Load current in the hundreds of mA range

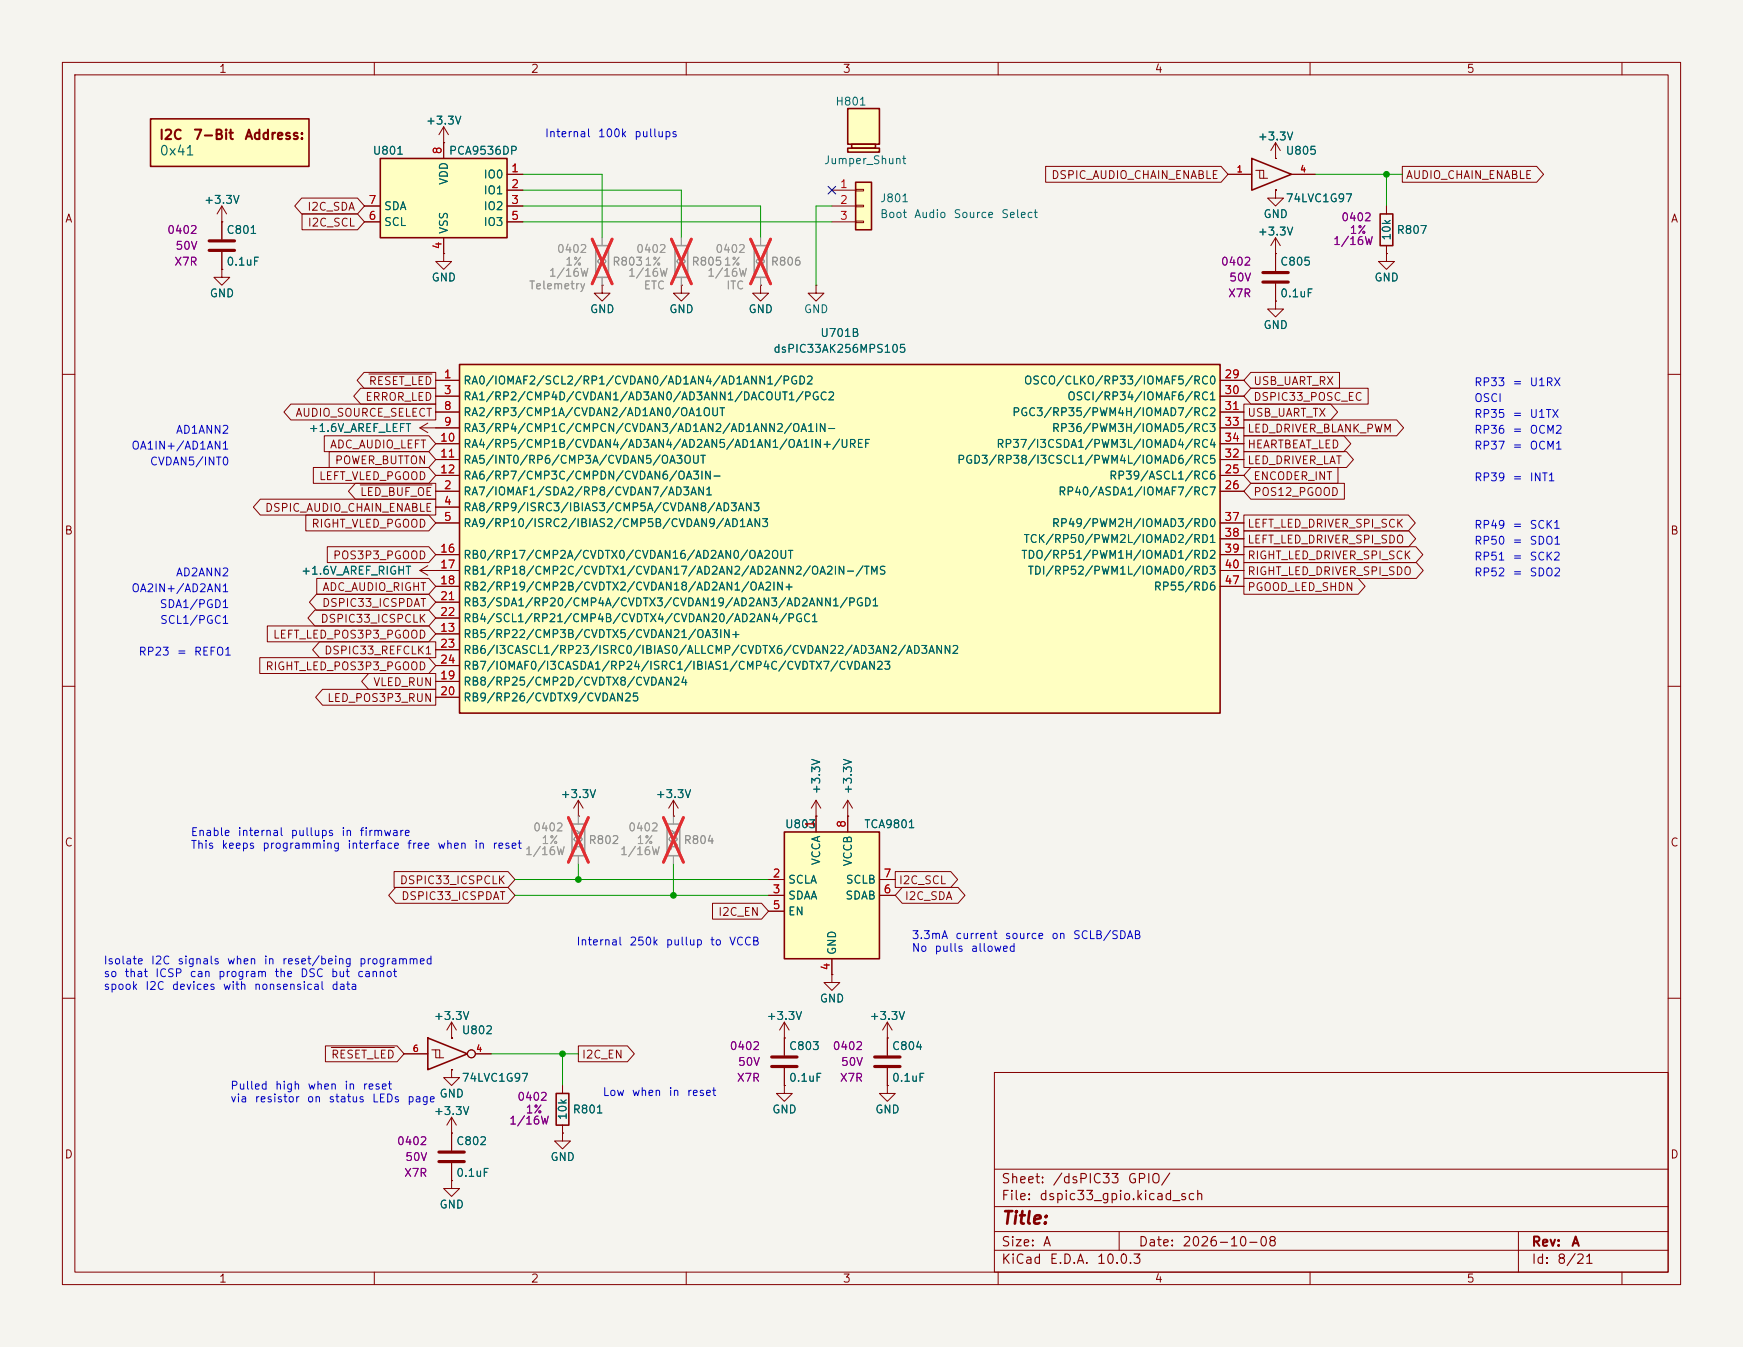
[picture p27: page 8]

J801 Boot Audio Source Select

Enable internal pullups in firmware
This keeps programming interface free when in reset

Internal 250k pullup to VCCB

Isolate I2C signals when in reset/being programmed
so that ICSP can program the DSC but cannot spook I2C devices with nonsensical data Pulled high when in reset via resistor on status LEDs page

Low when in reset

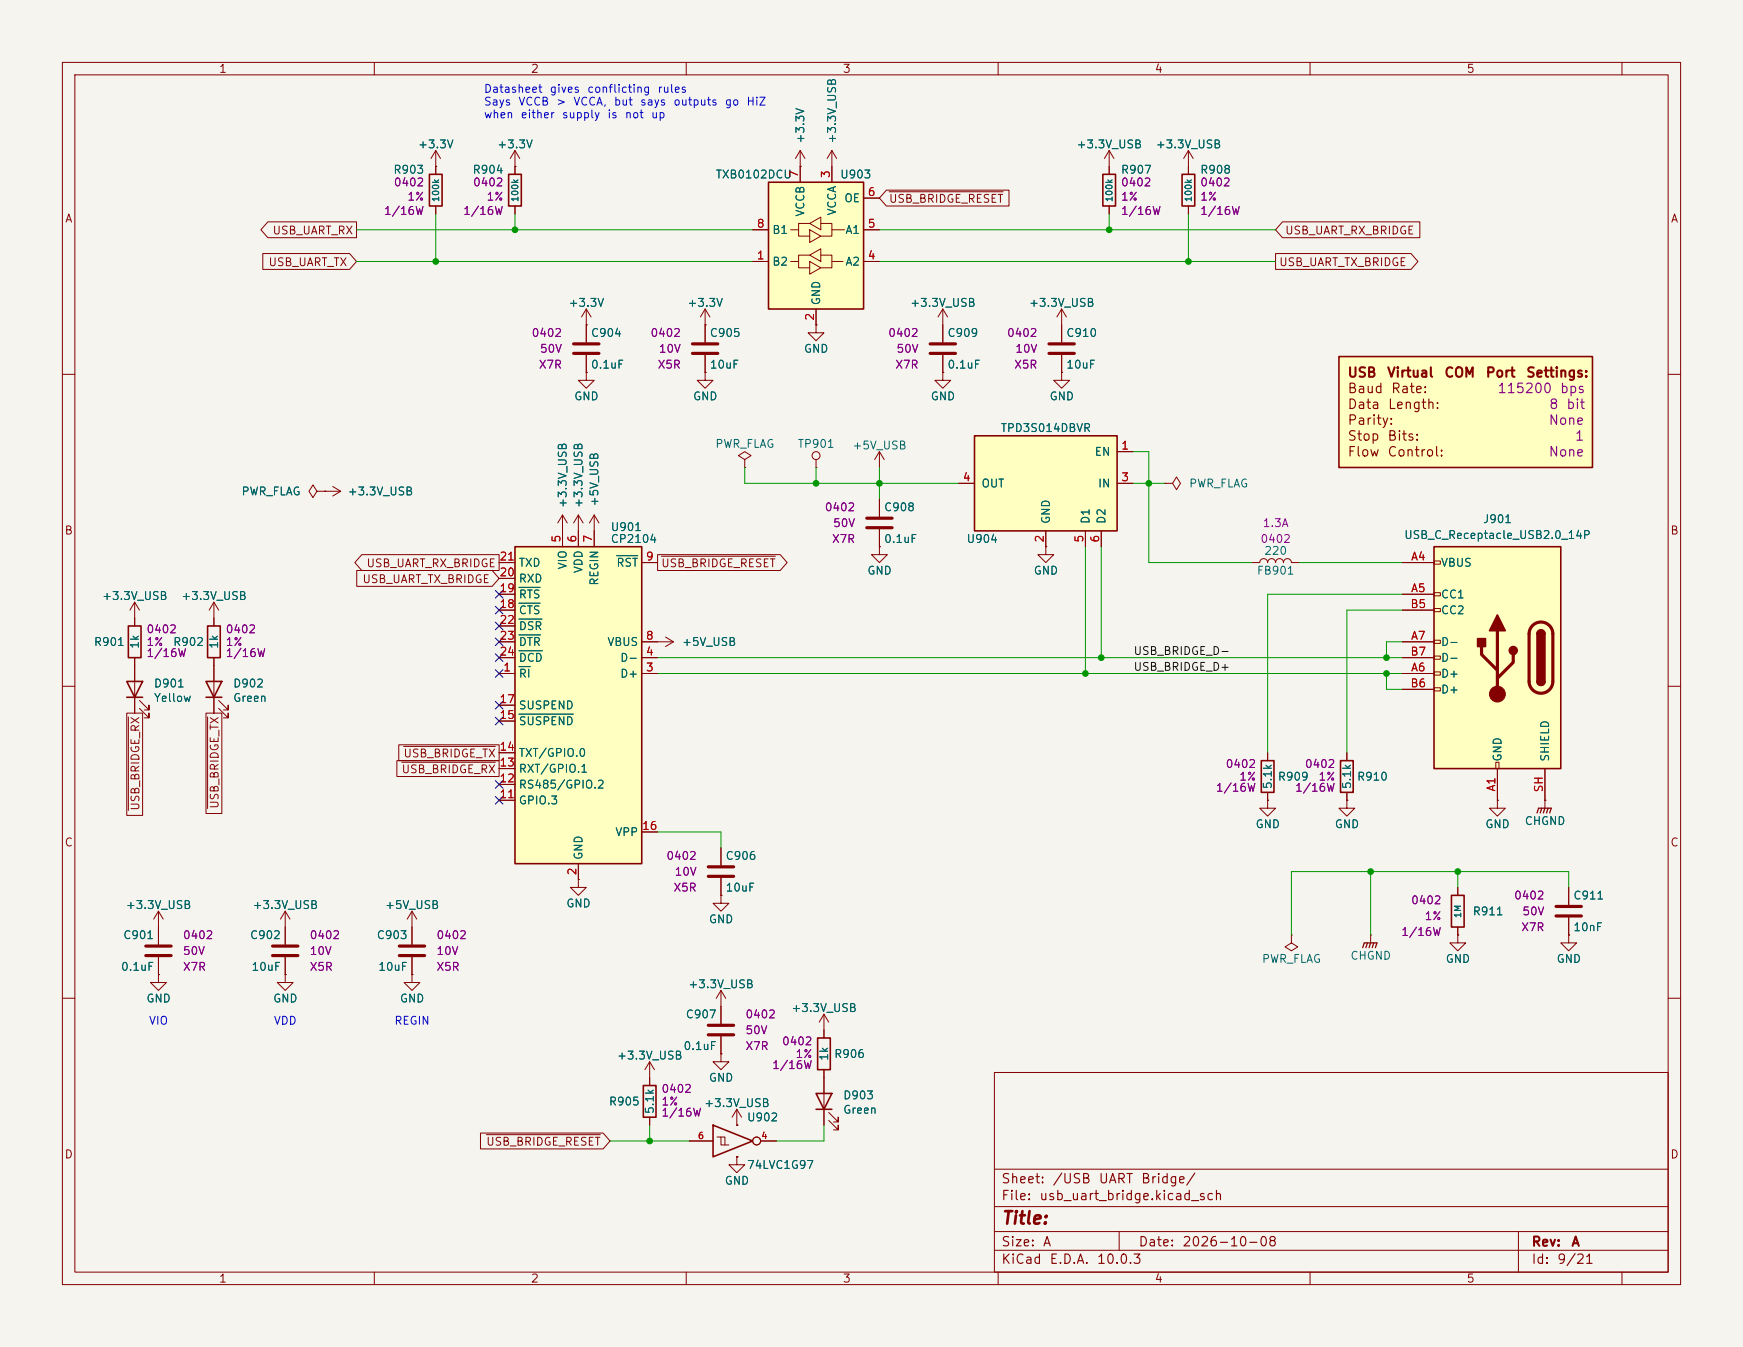
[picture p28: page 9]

Datasheet gives conflicting rules Says VCCB > VCCA, but says outputs go HiZ when either supply is not up

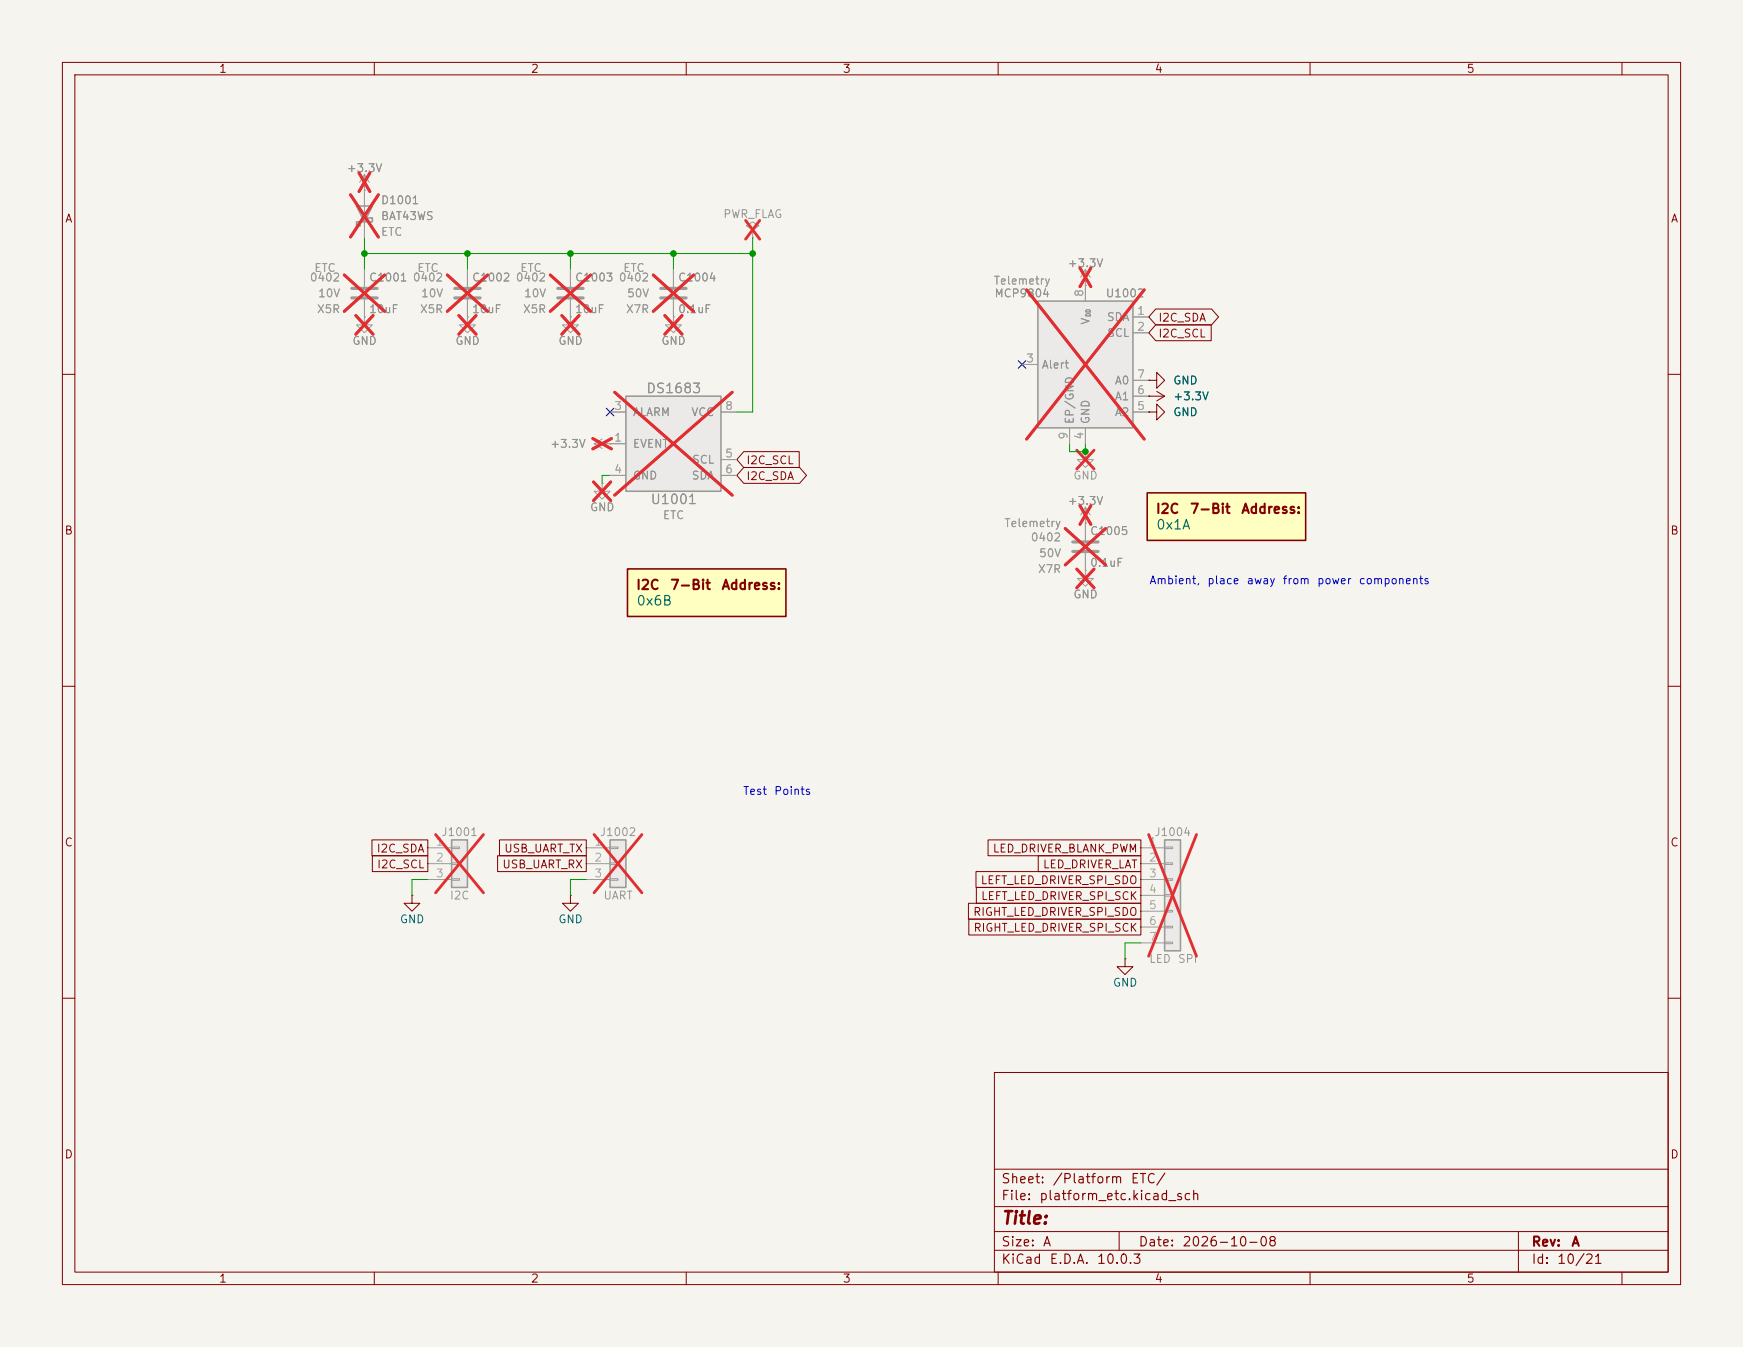
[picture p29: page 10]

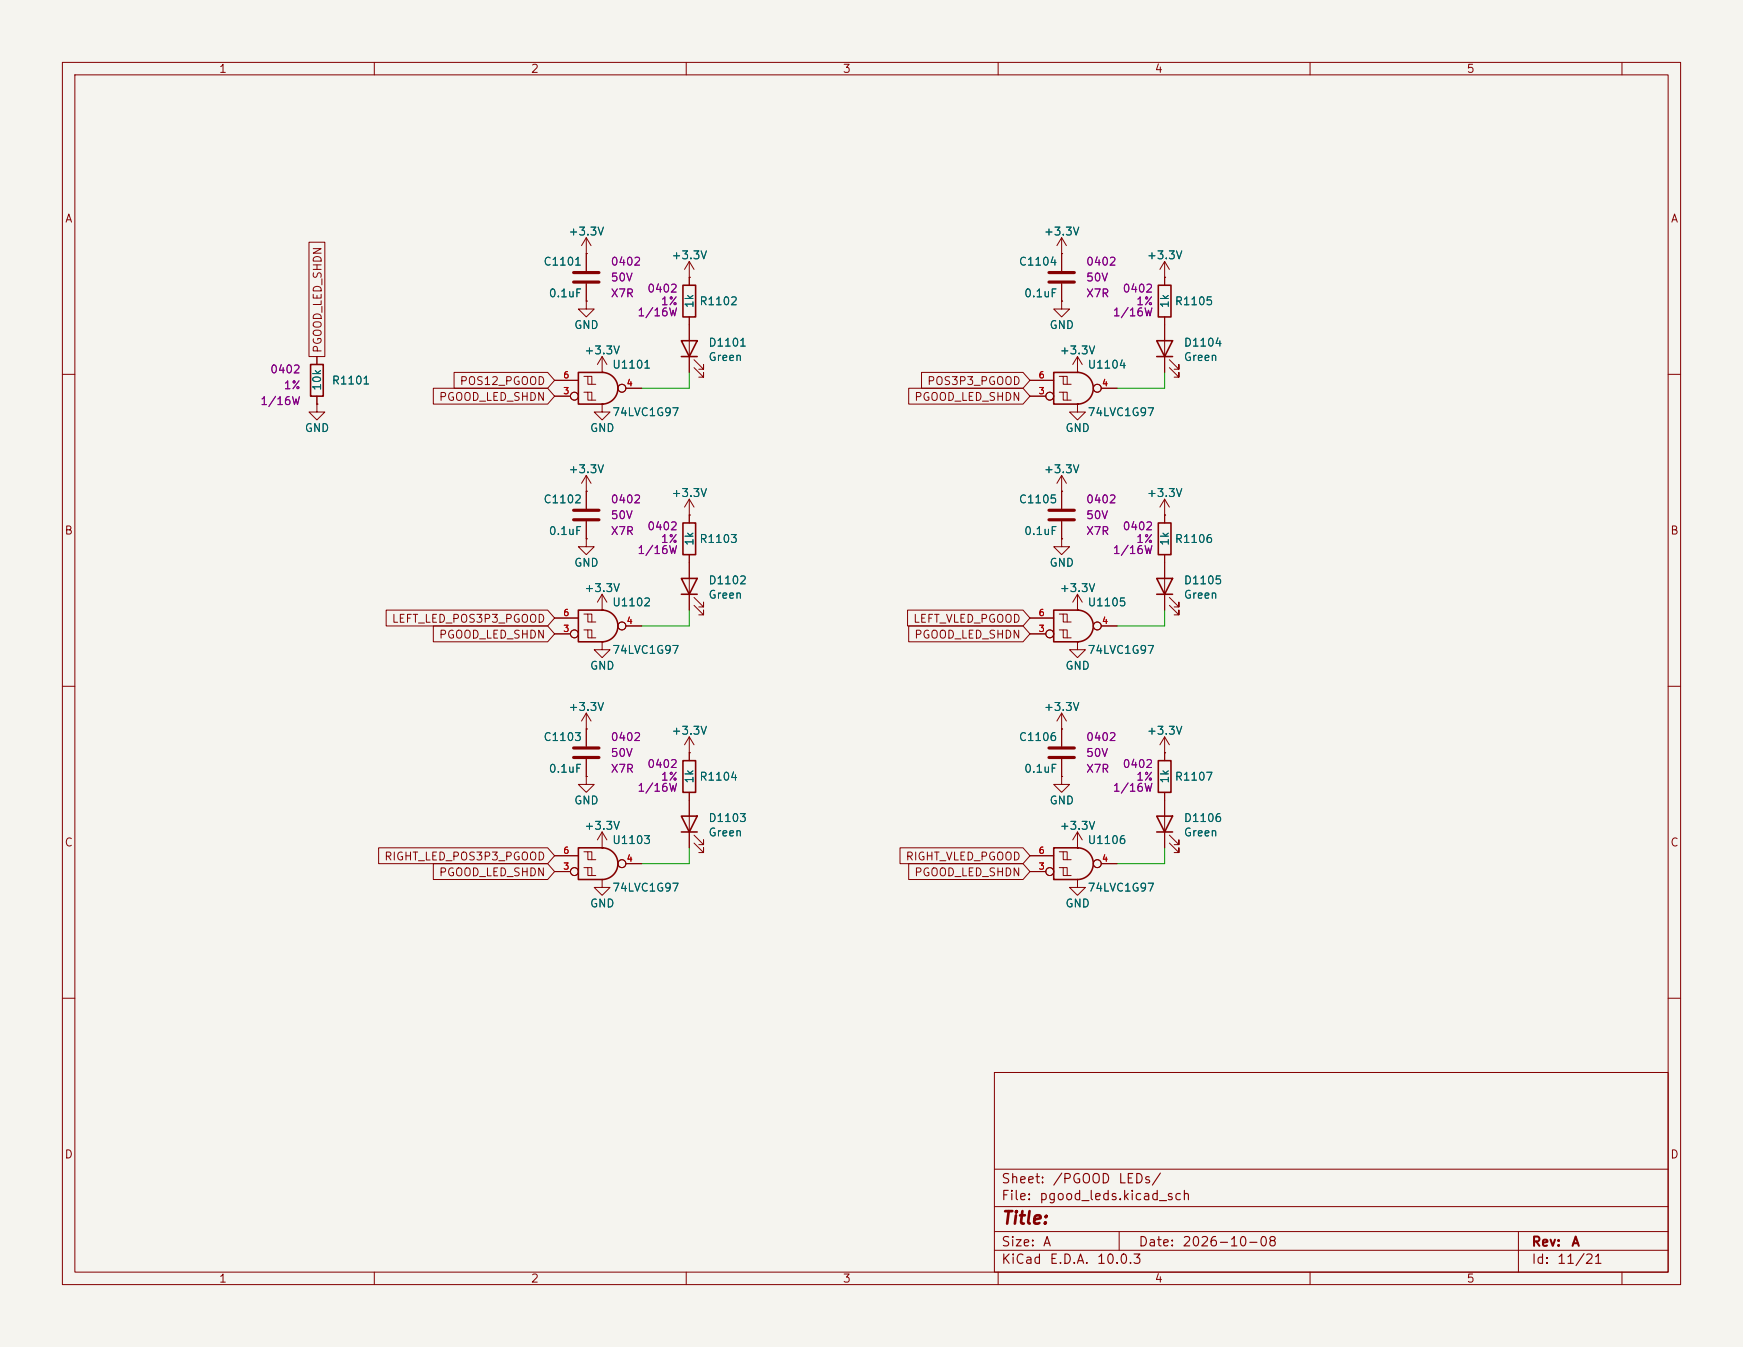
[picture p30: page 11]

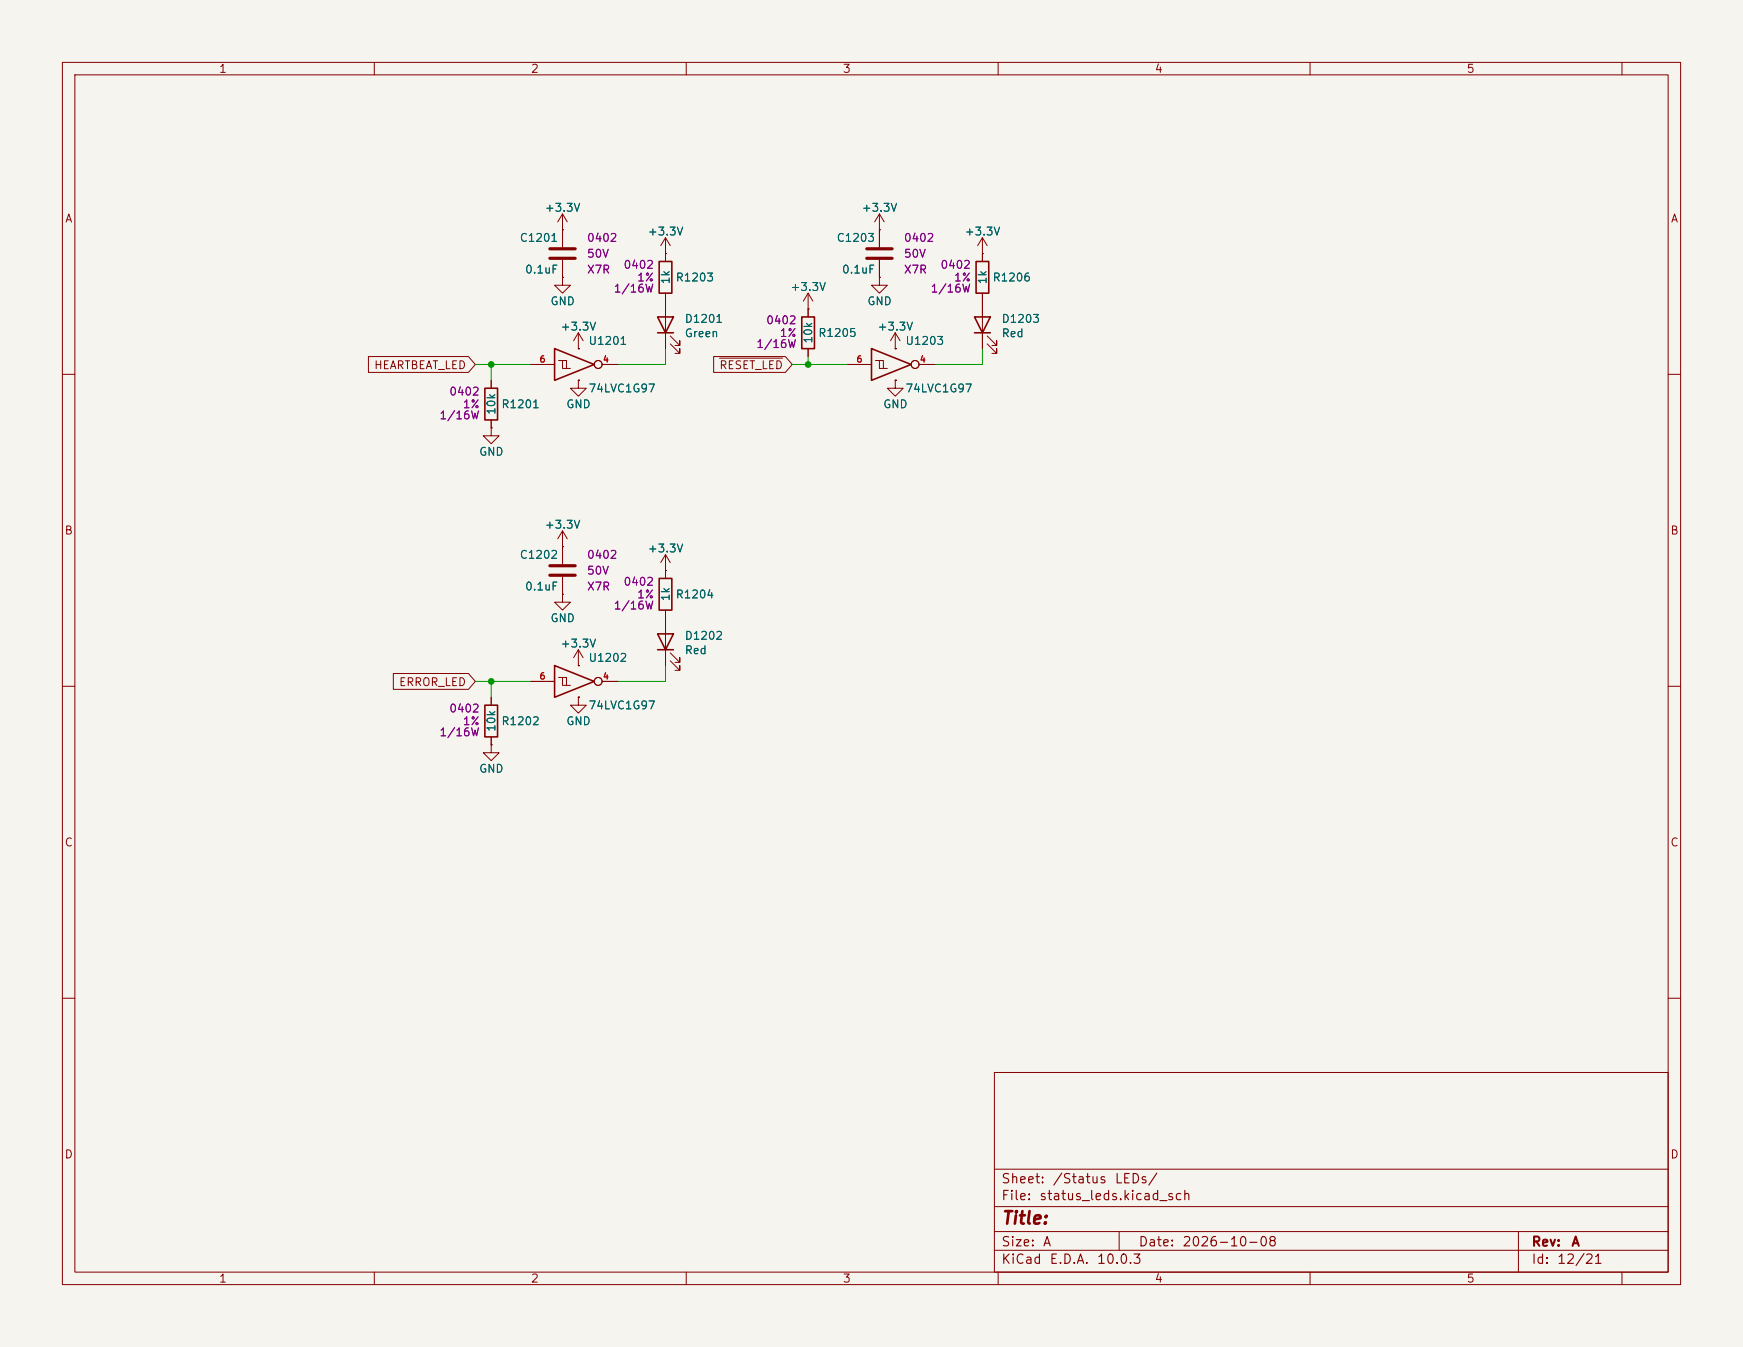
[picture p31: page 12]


Resistor divider = 4.022:1 attenuation
Instrumentation amp gain = 1:2
Effective attenuation = 2.011:1 Resistor divider = 4.022:1 attenuation

Sheet: /RCA Signal Conditioning/
File: rca_signal_conditioning.kicad_sch
Title:


Effective attenuation = 10.5:1 Resistor divider = 21:1 attenuation
Instrumentation amp gain = 1:2

Sheet: /Speaker Signal Conditioning/
File: speaker_signal_conditoning.kicad_sch
Title:


At reset, wiper is midpoint, so Av = 1 +3.3V GND U1502A MCP6024

AUDIO_CHAIN_ENABLE High = Speaker Low = RCA

This digipot can both attenuate and amplify depending on setting
At reset, wiper is midpoint, so Av = 1

Inverting op amps with
adjustable gain/attenuation

Audio source selection analog switches

Sheet: /Source Selection, PGAs/
File: source_selection_pgas.kicad_sch
Title:


Sheet: /Anti-alias Filtering/
File: anti_alias_filtering.kicad_sch
Title:


Sheet: /Audio Voltage References/
File: audio_voltage_references.kicad_sch
Title:


3.3mA current source on SCLB/SDAB No pulls allowed

Internal 250k pullup to VCCB

8 916151413121110 GND GND GND GND GND GND GND GND +3.3V GND GND GND GND GND GND +3.3V C1803

74LVC1G97 +3.3V GND +3.3V GND GND GND

Sheet: /LED Panel Buffers/
File: led_panel_buffers.kicad_sch
Title:


GND N1901
Adafruit Rotary Encoder Module

Adafruit Rotary Encoder Module 0x36



Sheet: /LED Panel Connectors/
File: led_panel_connectors.kicad_sch
Title:

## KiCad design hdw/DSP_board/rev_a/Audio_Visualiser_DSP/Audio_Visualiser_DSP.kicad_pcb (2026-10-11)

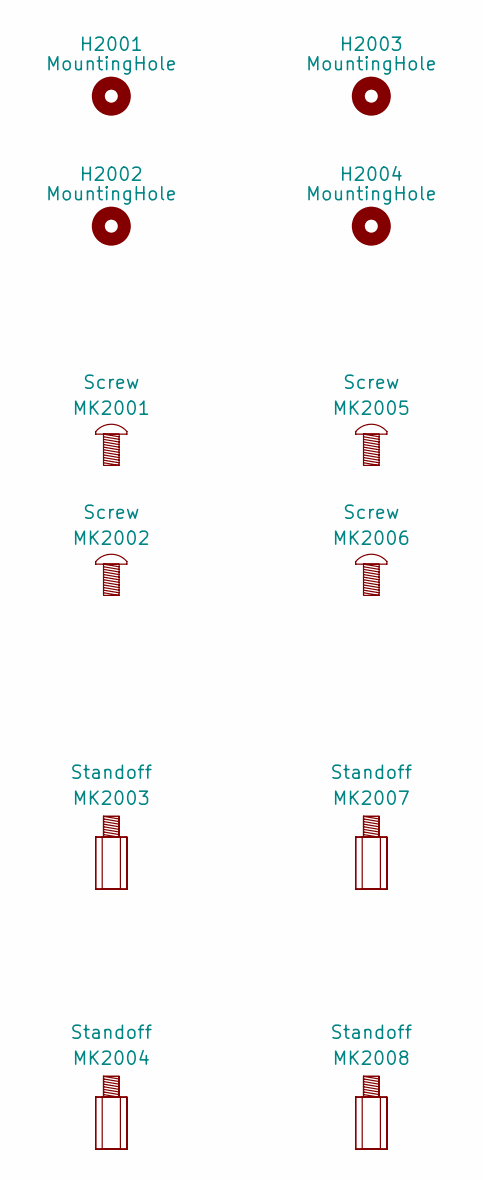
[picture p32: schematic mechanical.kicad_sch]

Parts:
H2001, H2002, H2003, H2004: MountingHole; MountingHole_3mm
MK2001, MK2002, MK2005, MK2006: Screw
MK2003, MK2004, MK2007, MK2008: Standoff

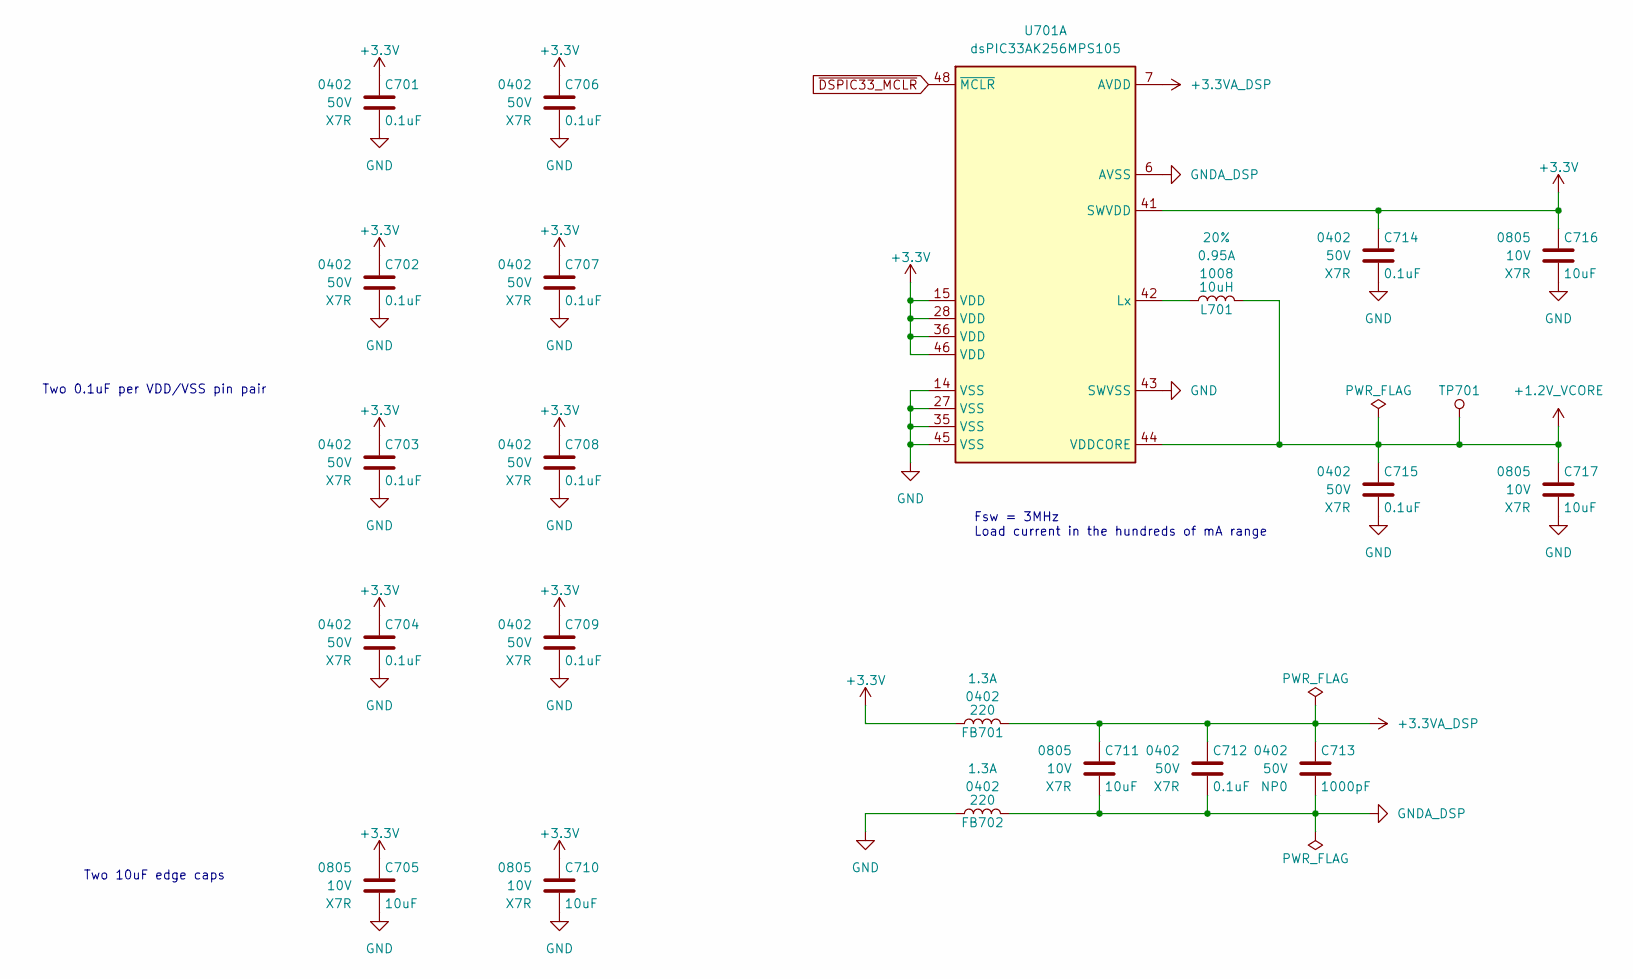
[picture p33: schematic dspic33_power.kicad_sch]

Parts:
C701, C702, C703, C704, C706, C707, C708, C709, C712, C714, C715: 0.1uF; C_0402; Voltage 50V; Digi-Key PN 1276-CL05B104KB5NNNCCT-ND
C705, C710, C711, C716, C717: 10uF; C_0805; Voltage 10V; Digi-Key PN 478-KGM21AR71A106KUCT-ND
C713: 1000pF; C_0402; Voltage 50V; Digi-Key PN 490-6190-1-ND
FB701, FB702: 220; L_0402; Digi-Key PN 490-16508-1-ND
L701: 10uH; L_Wuerth_PMCI-252012; Tolerance 20%; Digi-Key PN 490-13050-1-ND
TP701: TP; Test_Point; Digi-Key PN 36-5005-ND
U701: dsPIC33AK256MPS105; VQFN-48-1EP_6x6mm_P0.4mm_EP4.1x4.1mm; Digi-Key PN 150-DSPIC33AK256MPS105-I/M7-ND

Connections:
+1.2V_VCORE: C715.1, C717.1, L701.2, TP701.1 (TP_1), U701.44 (VDDCORE)
+3.3V: C701.1, C702.1, C703.1, C704.1, C705.1, C706.1, C707.1, C708.1, C709.1, C710.1, C714.1, C716.1, FB701.1, U701.15 (VDD), U701.28 (VDD), U701.36 (VDD), U701.41 (SWVDD), U701.46 (VDD); also elsewhere on the board
+3.3VA_DSP: C711.1, C712.1, C713.1, FB701.2, U701.7 (AVDD)
GND: C701.2, C702.2, C703.2, C704.2, C705.2, C706.2, C707.2, C708.2, C709.2, C710.2, C714.2, C715.2, C716.2, C717.2, FB702.1, U701.14 (VSS), U701.27 (VSS), U701.35 (VSS), U701.43 (SWVSS), U701.45 (VSS), U701.49 (VSS); also elsewhere on the board
GNDA_DSP: C711.2, C712.2, C713.2, FB702.2, U701.6 (AVSS)
unnamed: L701.1, U701.42 (Lx)
~DSPIC33_MCLR: U701.48 (~MCLR); also elsewhere on the board

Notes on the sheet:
Fsw = 3MHz Load current in the hundreds of mA range
Two 0.1uF per VDD/VSS pin pair
Two 10uF edge caps

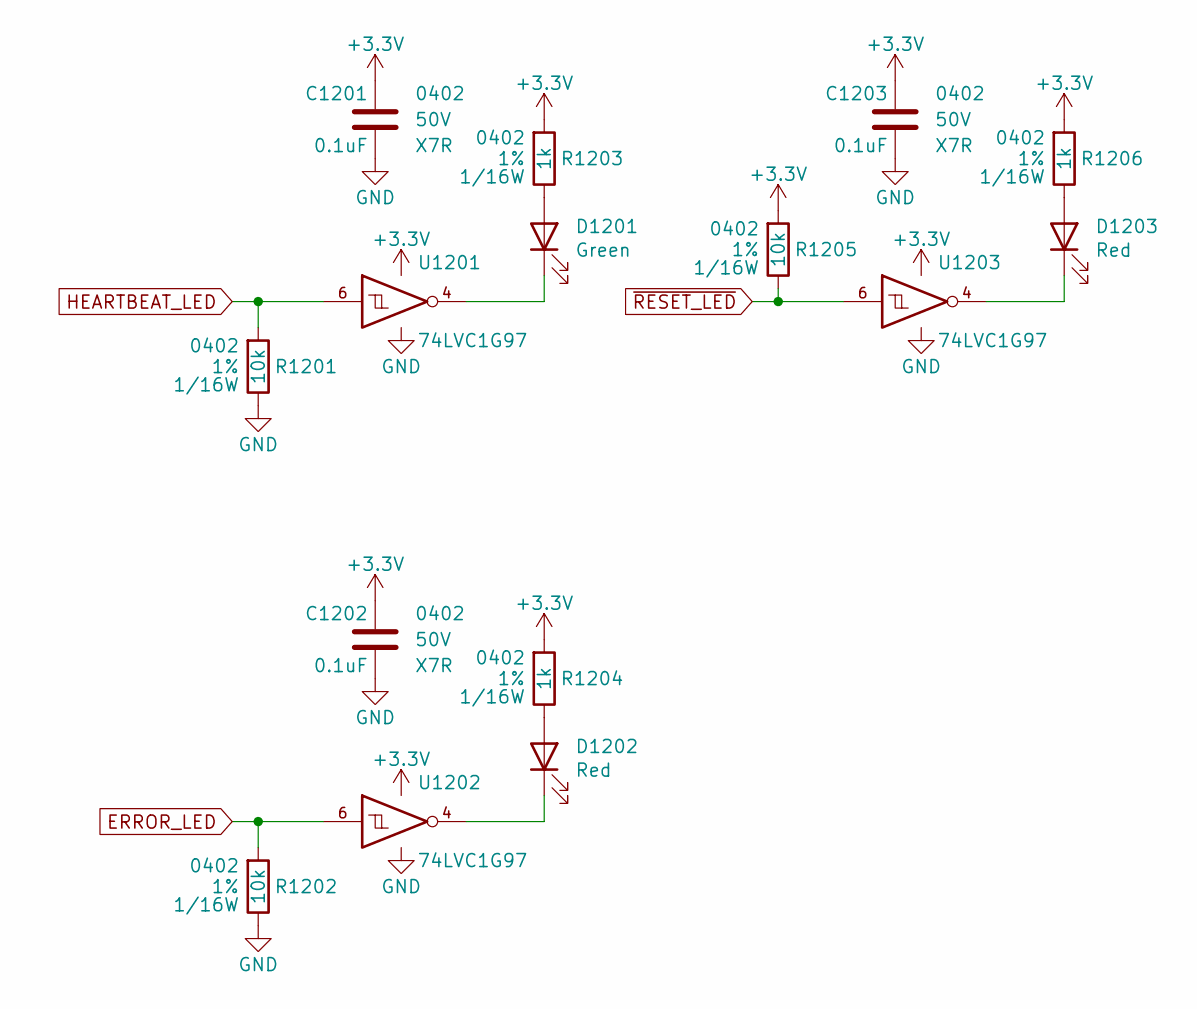
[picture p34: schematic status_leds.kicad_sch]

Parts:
C1201, C1202, C1203: 0.1uF; C_0402; Voltage 50V; Digi-Key PN 1276-CL05B104KB5NNNCCT-ND
D1201: Green; LED_0402; Digi-Key PN 732-11992-1-ND
D1202, D1203: Red; LED_0402; Digi-Key PN 732-11991-1-ND
R1201, R1202, R1205: 10k; R_0402; Tolerance 1%; Digi-Key PN 311-10.0KLRCT-ND
R1203, R1204, R1206: 1k; R_0402; Tolerance 1%; Digi-Key PN 311-1.00KLRCT-ND
U1201, U1202, U1203: 74LVC1G97; SOT-363_SC-70-6; Digi-Key PN 296-15582-1-ND

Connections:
+3.3V: C1201.1, C1202.1, C1203.1, R1203.1, R1204.1, R1205.1, R1206.1, U1201.1 (VCC), U1201.5 (VCC), U1202.1 (VCC), U1202.5 (VCC), U1203.1 (VCC), U1203.5 (VCC); also elsewhere on the board
ERROR_LED: R1202.1, U1202.6; also elsewhere on the board
GND: C1201.2, C1202.2, C1203.2, R1201.2, R1202.2, U1201.2 (GND), U1201.3 (GND), U1202.2 (GND), U1202.3 (GND), U1203.2 (GND), U1203.3 (GND); also elsewhere on the board
HEARTBEAT_LED: R1201.1, U1201.6; also elsewhere on the board
unnamed: D1201.2 (A), R1203.2
unnamed: D1201.1 (K), U1201.4
unnamed: D1202.2 (A), R1204.2
unnamed: D1202.1 (K), U1202.4
unnamed: D1203.2 (A), R1206.2
unnamed: D1203.1 (K), U1203.4
~RESET_LED: R1205.2, U1203.6; also elsewhere on the board

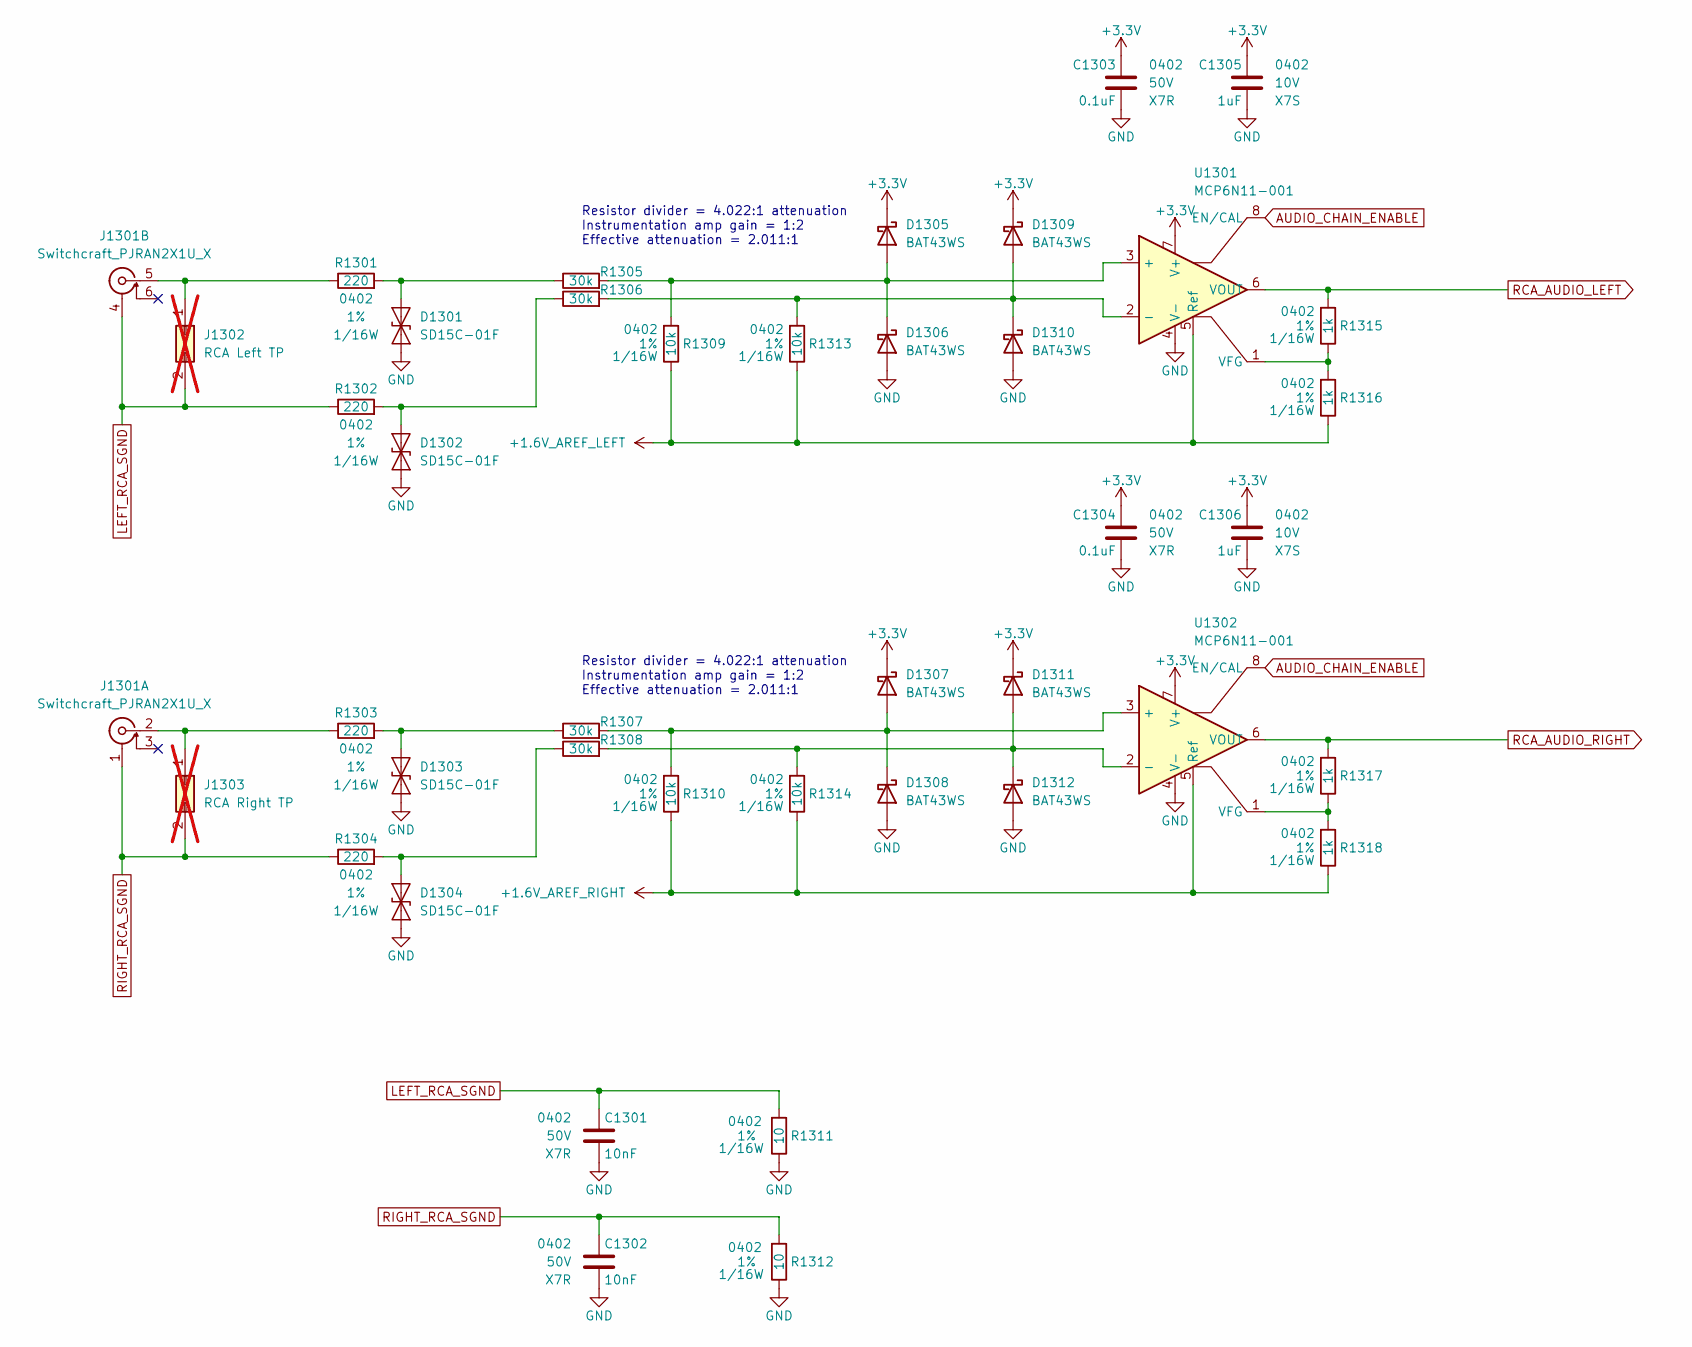
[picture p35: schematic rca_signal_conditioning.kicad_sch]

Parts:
C1301, C1302: 10nF; C_0402; Voltage 50V; Digi-Key PN 490-4516-1-ND
C1303, C1304: 0.1uF; C_0402; Voltage 50V; Digi-Key PN 1276-CL05B104KB5NNNCCT-ND
C1305, C1306: 1uF; C_0402; Voltage 10V; Digi-Key PN 490-18202-1-ND
D1301, D1302, D1303, D1304: SD15C-01F; D_SOD-323; Digi-Key PN F6444CT-ND
D1305, D1306, D1307, D1308, D1309, D1310, D1311, D1312: BAT43WS; D_SOD-323F; Digi-Key PN BAT43WSRRGCT-ND
J1301: Switchcraft_PJRAN2X1U_X; Digi-Key PN SC2534-ND
J1302: RCA Left TP; PinSocket_1x02_P2.54mm_Vertical; not fitted
J1303: RCA Right TP; PinSocket_1x02_P2.54mm_Vertical; not fitted
R1301, R1302, R1303, R1304: 220; R_0402; Tolerance 1%; Digi-Key PN 311-220LRCT-ND
R1305, R1306, R1307, R1308: 30k; R_0402; Tolerance 1%; Digi-Key PN 311-30.0KLRCT-ND
R1309, R1310, R1313, R1314: 10k; R_0402; Tolerance 1%; Digi-Key PN 311-10.0KLRCT-ND
R1311, R1312: 10; R_0402; Tolerance 1%; Digi-Key PN 311-10.0LRCT-ND
R1315, R1316, R1317, R1318: 1k; R_0402; Tolerance 1%; Digi-Key PN 311-1.00KLRCT-ND
U1301, U1302: MCP6N11-001; DFN-8-1EP_3x2mm_P0.5mm_EP1.36x1.46mm; Digi-Key PN MCP6N11T-001E/MNYCT-ND

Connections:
+1.6V_AREF_LEFT: R1309.2, R1313.2, R1316.2, U1301.5 (Ref); also elsewhere on the board
+1.6V_AREF_RIGHT: R1310.2, R1314.2, R1318.2, U1302.5 (Ref); also elsewhere on the board
+3.3V: C1303.1, C1304.1, C1305.1, C1306.1, D1305.1 (K), D1307.1 (K), D1309.1 (K), D1311.1 (K), U1301.7 (V+), U1302.7 (V+); also elsewhere on the board
AUDIO_CHAIN_ENABLE: U1301.8 (EN/CAL), U1302.8 (EN/CAL); also elsewhere on the board
GND: C1301.2, C1302.2, C1303.2, C1304.2, C1305.2, C1306.2, D1301.2 (A2), D1302.2 (A2), D1303.2 (A2), D1304.2 (A2), D1306.2 (A), D1308.2 (A), D1310.2 (A), D1312.2 (A), R1311.2, R1312.2, U1301.4 (V-), U1301.9 (EP), U1302.4 (V-), U1302.9 (EP); also elsewhere on the board
LEFT_RCA_SGND: C1301.1, J1301.4 (Sleeve_B), J1302.2, R1302.2, R1311.1
unnamed: D1301.1 (A1), R1301.1, R1305.2
unnamed: D1302.1 (A1), R1302.1, R1306.2
unnamed: D1303.1 (A1), R1303.1, R1307.2
unnamed: D1304.1 (A1), R1304.1, R1308.2
unnamed: D1305.2 (A), D1306.1 (K), R1305.1, R1309.1, U1301.3 (+)
unnamed: D1307.2 (A), D1308.1 (K), R1307.1, R1310.1, U1302.3 (+)
unnamed: D1309.2 (A), D1310.1 (K), R1306.1, R1313.1, U1301.2 (-)
unnamed: D1311.2 (A), D1312.1 (K), R1308.1, R1314.1, U1302.2 (-)
unnamed: J1301.2 (Tip_A), J1303.1, R1303.2
unnamed: J1301.5 (Tip_B), J1302.1, R1301.2
unnamed: R1315.2, R1316.1, U1301.1 (VFG)
unnamed: R1317.2, R1318.1, U1302.1 (VFG)
RCA_AUDIO_LEFT: R1315.1, U1301.6 (VOUT); also elsewhere on the board
RCA_AUDIO_RIGHT: R1317.1, U1302.6 (VOUT); also elsewhere on the board
RIGHT_RCA_SGND: C1302.1, J1301.1 (Sleeve_A), J1303.2, R1304.2, R1312.1

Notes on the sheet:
Resistor divider = 4.022:1 attenuation Instrumentation amp gain = 1:2 Effective attenuation = 2.011:1

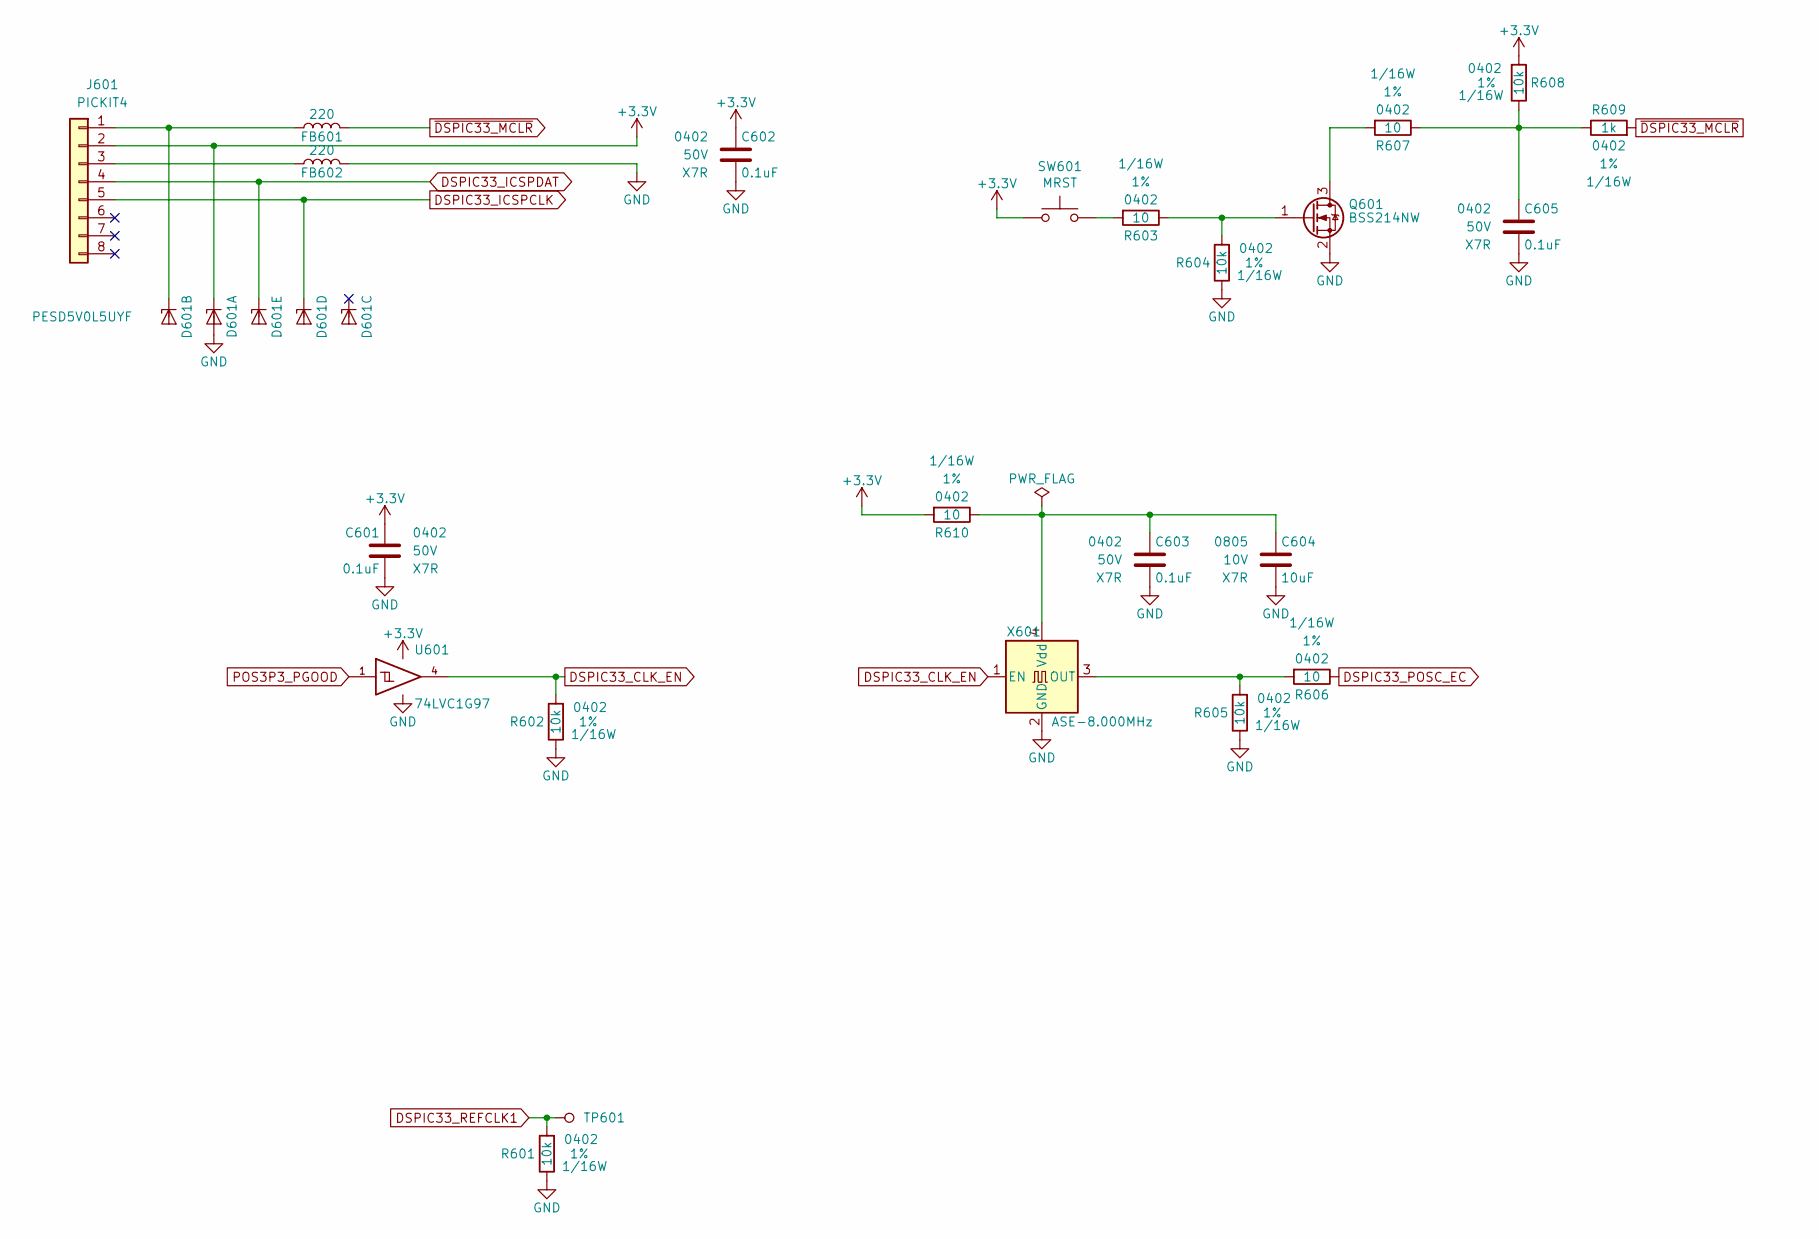
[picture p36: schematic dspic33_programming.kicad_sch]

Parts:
C601, C602, C603, C605: 0.1uF; C_0402; Voltage 50V; Digi-Key PN 1276-CL05B104KB5NNNCCT-ND
C604: 10uF; C_0805; Voltage 10V; Digi-Key PN 478-KGM21AR71A106KUCT-ND
D601: PESD5V0L5UYF; SOT-363_SC-70-6; Digi-Key PN 1727-PESD5V0L5UYFCT-ND
FB601, FB602: 220; L_0402; Digi-Key PN 490-16508-1-ND
J601: PICKIT4; PICKIT4_Header; Digi-Key PN 35-PRPC008SBAN-M71RC-ND
Q601: BSS214NW; SOT-323_SC-70; Digi-Key PN BSS214NWH6327XTSA1CT-ND
R601, R602, R604, R605, R608: 10k; R_0402; Tolerance 1%; Digi-Key PN 311-10.0KLRCT-ND
R603, R606, R607, R610: 10; R_0402; Tolerance 1%; Digi-Key PN 311-10.0LRCT-ND
R609: 1k; R_0402; Tolerance 1%; Digi-Key PN 311-1.00KLRCT-ND
SW601: MRST; SW_PUSH_6mm; Digi-Key PN 450-1650-ND
TP601: TP; Test_Point
U601: 74LVC1G97; SOT-363_SC-70-6; Digi-Key PN 296-15582-1-ND
X601: ASE-8.000MHz; Oscillator_SMD_Abracon_ASE-4Pin_3.2x2.5mm; Digi-Key PN 535-9558-1-ND

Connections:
+3.3V: C601.1, C602.1, D601.1 (K1), J601.2, R608.1, R610.1, SW601.1, U601.5 (VCC); also elsewhere on the board
DSPIC33_CLK_EN: R602.1, U601.4, X601.1 (EN)
DSPIC33_ICSPCLK: D601.5 (K4), J601.5; also elsewhere on the board
DSPIC33_ICSPDAT: D601.6 (K5), J601.4; also elsewhere on the board
DSPIC33_POSC_EC: R606.2; also elsewhere on the board
DSPIC33_REFCLK1: R601.1, TP601.1 (TP_1); also elsewhere on the board
GND: C601.2, C602.2, C603.2, C604.2, C605.2, D601.2 (A), FB602.2, Q601.2 (S), R601.2, R602.2, R604.2, R605.2, U601.2 (GND), U601.3 (GND), U601.6 (GND), X601.2 (GND); also elsewhere on the board
unnamed: C605.1, R607.2, R608.2, R609.2
unnamed: D601.3 (K2), FB601.1, J601.1
unnamed: FB602.1, J601.3
unnamed: Q601.3 (D), R607.1
unnamed: Q601.1 (G), R603.2, R604.1
unnamed: R603.1, SW601.2
unnamed: R605.1, R606.1, X601.3 (OUT)
unnamed: C603.1, C604.1, R610.2, X601.4 (Vdd)
POS3P3_PGOOD: U601.1; also elsewhere on the board
~DSPIC33_MCLR: FB601.2, R609.1; also elsewhere on the board

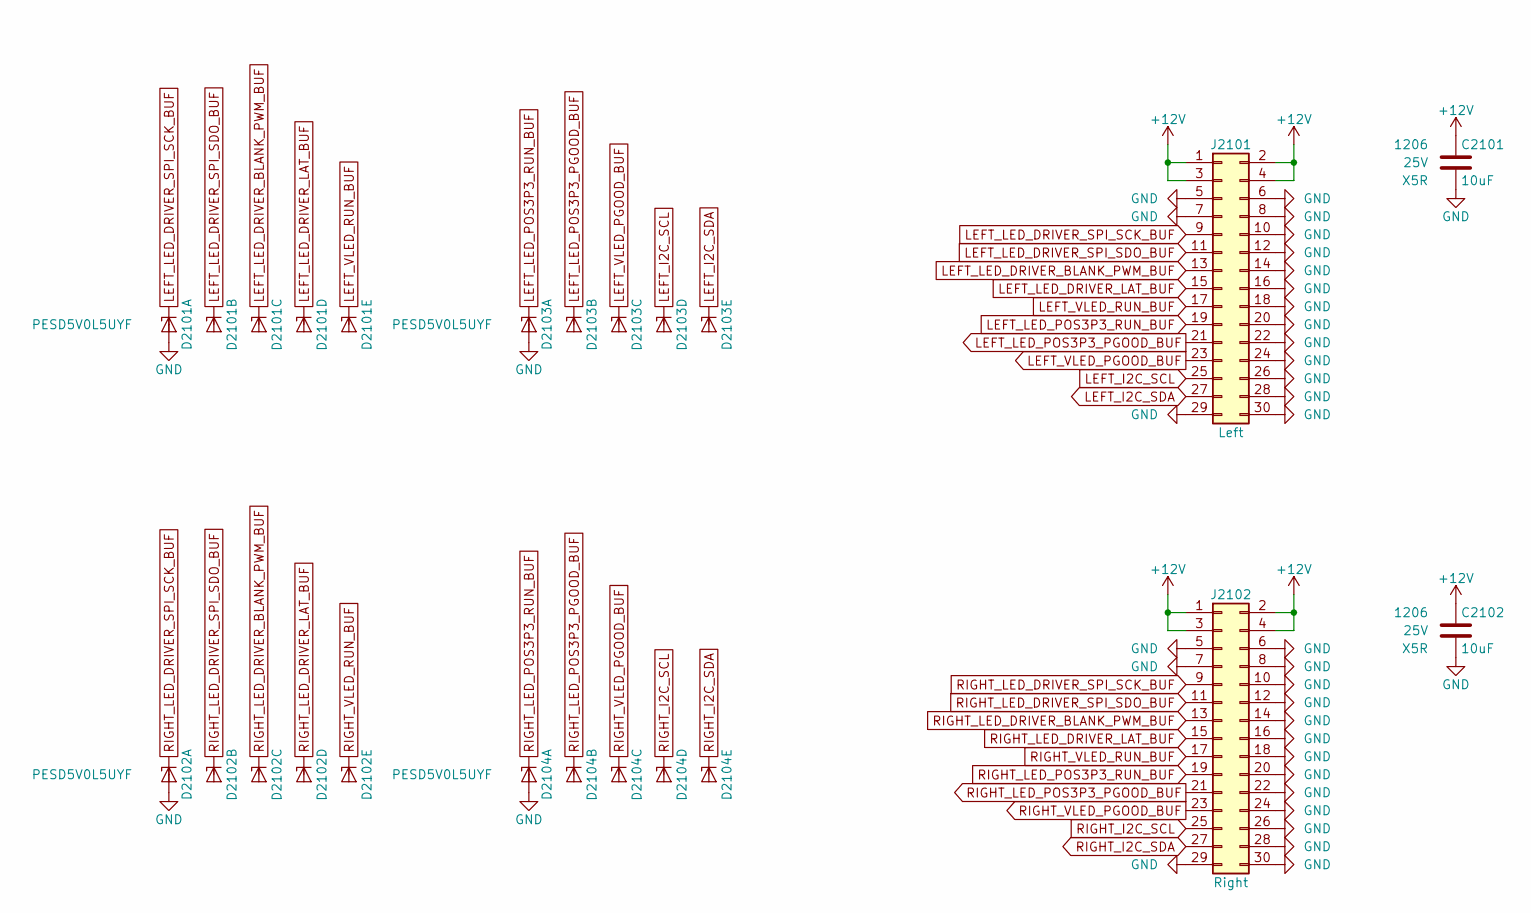
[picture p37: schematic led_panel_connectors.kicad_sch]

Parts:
C2101, C2102: 10uF; C_1206; Voltage 25V; Digi-Key PN 445-6862-1-ND
D2101, D2102, D2103, D2104: PESD5V0L5UYF; SOT-363_SC-70-6; Digi-Key PN 1727-PESD5V0L5UYFCT-ND
J2101: Left; IDC-Header_2x15_P2.54mm_Vertical; Digi-Key PN 900-0702463001-ND
J2102: Right; IDC-Header_2x15_P2.54mm_Vertical; Digi-Key PN 900-0702463001-ND

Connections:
+12V: C2101.1, C2102.1, J2101.1, J2101.2, J2101.3, J2101.4, J2102.1, J2102.2, J2102.3, J2102.4; also elsewhere on the board
GND: C2101.2, C2102.2, D2101.2 (A), D2102.2 (A), D2103.2 (A), D2104.2 (A), J2101.5, J2101.6, J2101.7, J2101.8, J2101.10, J2101.12, J2101.14, J2101.16, J2101.18, J2101.20, J2101.22, J2101.24, J2101.26, J2101.28, J2101.29, J2101.30, J2102.5, J2102.6, J2102.7, J2102.8, J2102.10, J2102.12, J2102.14, J2102.16, J2102.18, J2102.20, J2102.22, J2102.24, J2102.26, J2102.28, J2102.29, J2102.30; also elsewhere on the board
LEFT_I2C_SCL: D2103.5 (K4), J2101.25; also elsewhere on the board
LEFT_I2C_SDA: D2103.6 (K5), J2101.27; also elsewhere on the board
LEFT_LED_DRIVER_BLANK_PWM_BUF: D2101.4 (K3), J2101.13; also elsewhere on the board
LEFT_LED_DRIVER_LAT_BUF: D2101.5 (K4), J2101.15; also elsewhere on the board
LEFT_LED_DRIVER_SPI_SCK_BUF: D2101.1 (K1), J2101.9; also elsewhere on the board
LEFT_LED_DRIVER_SPI_SDO_BUF: D2101.3 (K2), J2101.11; also elsewhere on the board
LEFT_LED_POS3P3_PGOOD_BUF: D2103.3 (K2), J2101.21; also elsewhere on the board
LEFT_LED_POS3P3_RUN_BUF: D2103.1 (K1), J2101.19; also elsewhere on the board
LEFT_VLED_PGOOD_BUF: D2103.4 (K3), J2101.23; also elsewhere on the board
LEFT_VLED_RUN_BUF: D2101.6 (K5), J2101.17; also elsewhere on the board
RIGHT_I2C_SCL: D2104.5 (K4), J2102.25; also elsewhere on the board
RIGHT_I2C_SDA: D2104.6 (K5), J2102.27; also elsewhere on the board
RIGHT_LED_DRIVER_BLANK_PWM_BUF: D2102.4 (K3), J2102.13; also elsewhere on the board
RIGHT_LED_DRIVER_LAT_BUF: D2102.5 (K4), J2102.15; also elsewhere on the board
RIGHT_LED_DRIVER_SPI_SCK_BUF: D2102.1 (K1), J2102.9; also elsewhere on the board
RIGHT_LED_DRIVER_SPI_SDO_BUF: D2102.3 (K2), J2102.11; also elsewhere on the board
RIGHT_LED_POS3P3_PGOOD_BUF: D2104.3 (K2), J2102.21; also elsewhere on the board
RIGHT_LED_POS3P3_RUN_BUF: D2104.1 (K1), J2102.19; also elsewhere on the board
RIGHT_VLED_PGOOD_BUF: D2104.4 (K3), J2102.23; also elsewhere on the board
RIGHT_VLED_RUN_BUF: D2102.6 (K5), J2102.17; also elsewhere on the board

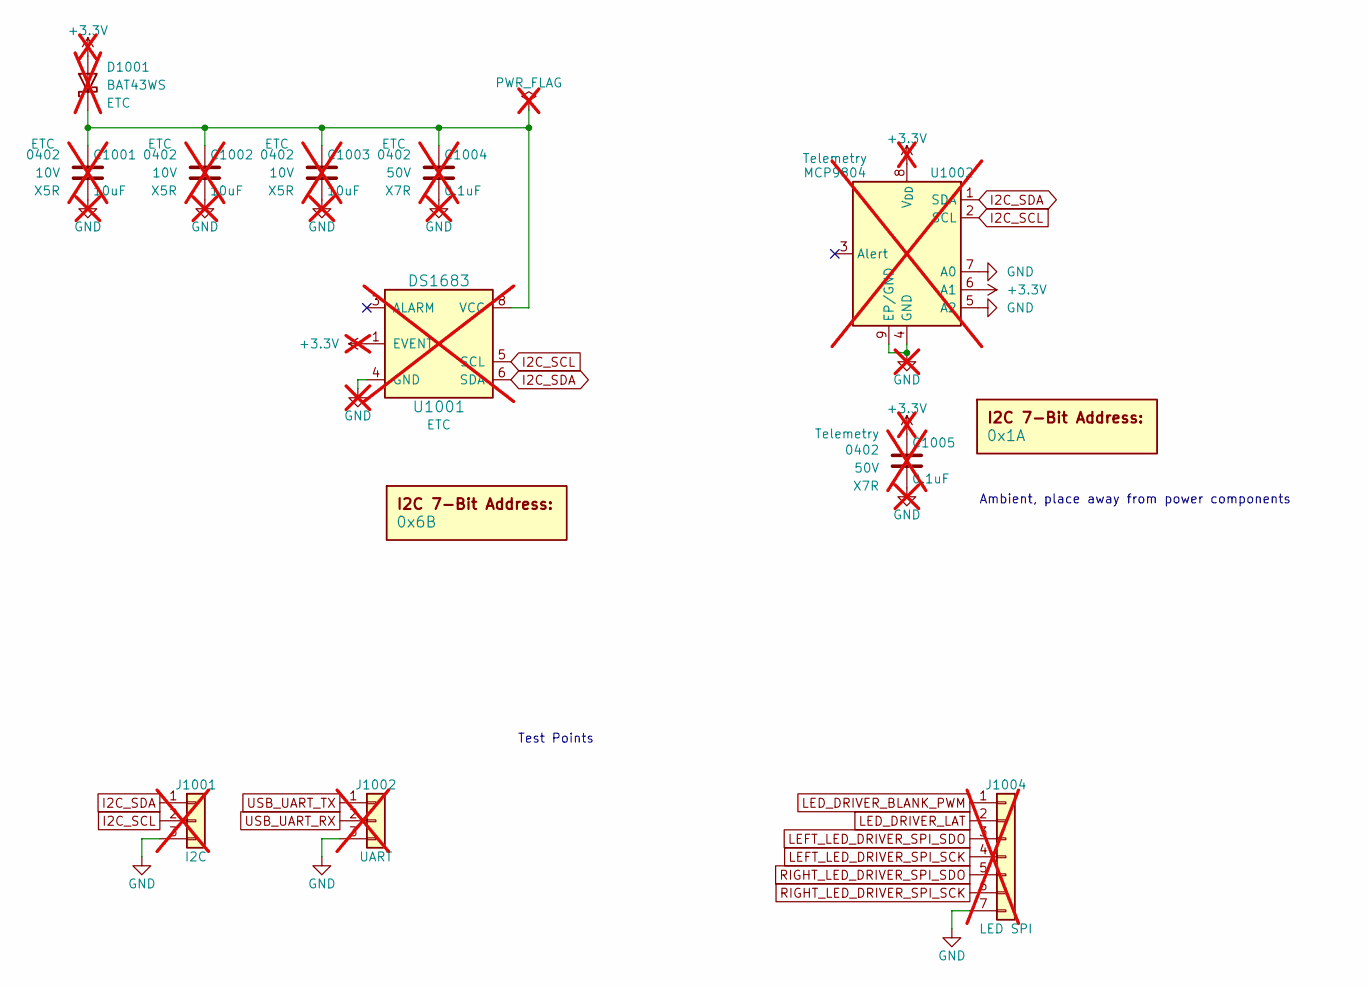
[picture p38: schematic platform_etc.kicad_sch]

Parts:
C1001, C1002, C1003: 10uF; C_0402; Voltage 10V; Digi-Key PN 1276-CL05A106MP6NUN8CT-ND; not fitted
C1004, C1005: 0.1uF; C_0402; Voltage 50V; Digi-Key PN 1276-CL05B104KB5NNNCCT-ND; not fitted
D1001: BAT43WS; D_SOD-323F; Digi-Key PN BAT43WSRRGCT-ND; not fitted
DOC1001: 0x6B
DOC1002: 0x1A
J1001: I2C; PinSocket_1x03_P2.54mm_Vertical; not fitted
J1002: UART; PinSocket_1x03_P2.54mm_Vertical; not fitted
J1004: LED SPI; PinSocket_1x07_P2.54mm_Vertical; not fitted
U1001: DS1683; SOIC-8_3.9x4.9mm_Pitch1.27mm; Digi-Key PN DS1683S+-ND; not fitted
U1002: MCP9804; DFN-8-1EP_3x2mm_P0.5mm_EP1.3x1.5mm; Digi-Key PN MCP9804T-E/MCCT-ND; not fitted

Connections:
+3.3V: C1005.1, D1001.2 (A), U1001.1 (EVENT), U1002.6 (A1), U1002.8 (V_{DD}); also elsewhere on the board
GND: C1001.2, C1002.2, C1003.2, C1004.2, C1005.2, J1001.3, J1002.3, J1004.7, U1001.4 (GND), U1002.4 (GND), U1002.5 (A2), U1002.7 (A0), U1002.9 (EP/GND); also elsewhere on the board
I2C_SCL: J1001.2, U1001.5 (SCL), U1002.2 (SCL); also elsewhere on the board
I2C_SDA: J1001.1, U1001.6 (SDA), U1002.1 (SDA); also elsewhere on the board
LED_DRIVER_BLANK_PWM: J1004.1; also elsewhere on the board
LED_DRIVER_LAT: J1004.2; also elsewhere on the board
LEFT_LED_DRIVER_SPI_SCK: J1004.4; also elsewhere on the board
LEFT_LED_DRIVER_SPI_SDO: J1004.3; also elsewhere on the board
unnamed: C1001.1, C1002.1, C1003.1, C1004.1, D1001.1 (K), U1001.8 (VCC)
RIGHT_LED_DRIVER_SPI_SCK: J1004.6; also elsewhere on the board
RIGHT_LED_DRIVER_SPI_SDO: J1004.5; also elsewhere on the board
USB_UART_RX: J1002.2; also elsewhere on the board
USB_UART_TX: J1002.1; also elsewhere on the board

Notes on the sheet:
Test Points
Ambient, place away from power components

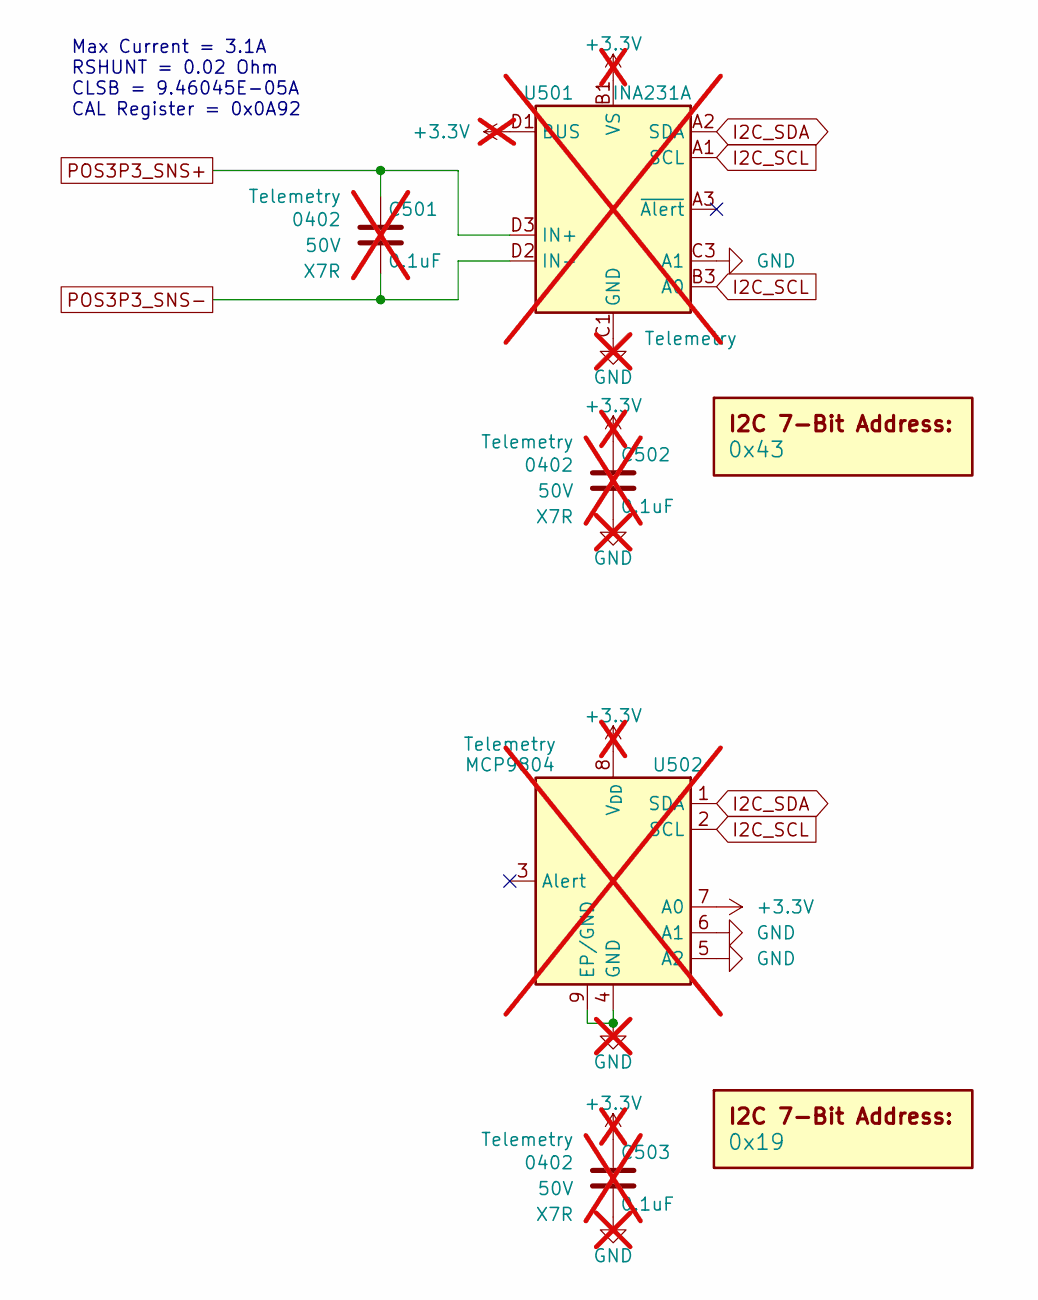
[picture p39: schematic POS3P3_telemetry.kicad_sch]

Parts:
C501, C502, C503: 0.1uF; C_0402; Voltage 50V; Digi-Key PN 1276-CL05B104KB5NNNCCT-ND; not fitted
DOC501: 0x43
DOC502: 0x19
U501: INA231A; Texas_DSBGA-12_1.65x1.39mm_Layout3x4_P0.4mm; Digi-Key PN 296-41263-1-ND; not fitted
U502: MCP9804; DFN-8-1EP_3x2mm_P0.5mm_EP1.3x1.5mm; Digi-Key PN MCP9804T-E/MCCT-ND; not fitted

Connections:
+3.3V: C502.1, C503.1, U501.B1 (VS), U501.D1 (BUS), U502.7 (A0), U502.8 (V_{DD}); also elsewhere on the board
GND: C502.2, C503.2, U501.C1 (GND), U501.C3 (A1), U502.4 (GND), U502.5 (A2), U502.6 (A1), U502.9 (EP/GND); also elsewhere on the board
I2C_SCL: U501.A1 (SCL), U501.B3 (A0), U502.2 (SCL); also elsewhere on the board
I2C_SDA: U501.A2 (SDA), U502.1 (SDA); also elsewhere on the board
POS3P3_SNS+: C501.1, U501.D3 (IN+); also elsewhere on the board
POS3P3_SNS-: C501.2, U501.D2 (IN-); also elsewhere on the board

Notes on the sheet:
Max Current = 3.1A RSHUNT = 0.02 Ohm CLSB = 9.46045E-05A CAL Register = 0x0A92

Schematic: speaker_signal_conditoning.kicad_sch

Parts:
C1401, C1402: 0.1uF; C_0402; Voltage 50V; Digi-Key PN 1276-CL05B104KB5NNNCCT-ND
C1403, C1404: 1uF; C_0402; Voltage 10V; Digi-Key PN 490-18202-1-ND
D1401, D1402, D1403, D1404, D1405, D1406, D1407, D1408: BAT43WS; D_SOD-323F; Digi-Key PN BAT43WSRRGCT-ND
J1401: Left; TerminalBlock_Phoenix_MKDS-1,5-2-5.08_1x02_P5.08mm_Horizont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; Digi-Key PN 277-1247-ND
J1402: Right; TerminalBlock_Phoenix_MKDS-1,5-2-5.08_1x02_P5.08mm_Horizont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; Digi-Key PN 277-1247-ND
J1403: Speaker Left TP; PinSocket_1x02_P2.54mm_Vertical; not fitted
J1404: Speaker Right TP; PinSocket_1x02_P2.54mm_Vertical; not fitted
R1401, R1402, R1403, R1404: 20k; R_0402; Tolerance 1%; Digi-Key PN 311-20.0KLRCT-ND
R1405, R1406, R1407, R1408, R1409, R1410, R1411, R1412: 1k; R_0402; Tolerance 1%; Digi-Key PN 311-1.00KLRCT-ND
U1401, U1402: MCP6N11-001; DFN-8-1EP_3x2mm_P0.5mm_EP1.36x1.46mm; Digi-Key PN MCP6N11T-001E/MNYCT-ND

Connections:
+1.6V_AREF_LEFT: R1405.2, R1407.2, R1410.2, U1401.5 (Ref); also elsewhere on the board
+1.6V_AREF_RIGHT: R1406.2, R1408.2, R1412.2, U1402.5 (Ref); also elsewhere on the board
+3.3V: C1401.1, C1402.1, C1403.1, C1404.1, D1401.1 (K), D1403.1 (K), D1405.1 (K), D1407.1 (K), U1401.7 (V+), U1402.7 (V+); also elsewhere on the board
AUDIO_CHAIN_ENABLE: U1401.8 (EN/CAL), U1402.8 (EN/CAL); also elsewhere on the board
GND: C1401.2, C1402.2, C1403.2, C1404.2, D1402.2 (A), D1404.2 (A), D1406.2 (A), D1408.2 (A), U1401.4 (V-), U1401.9 (EP), U1402.4 (V-), U1402.9 (EP); also elsewhere on the board
unnamed: D1401.2 (A), D1402.1 (K), R1401.1, R1405.1, U1401.3 (+)
unnamed: D1403.2 (A), D1404.1 (K), R1403.1, R1406.1, U1402.3 (+)
unnamed: D1405.2 (A), D1406.1 (K), R1402.1, R1407.1, U1401.2 (-)
unnamed: D1407.2 (A), D1408.1 (K), R1404.1, R1408.1, U1402.2 (-)
unnamed: J1401.1, J1403.1, R1401.2
unnamed: J1401.2, J1403.2, R1402.2
unnamed: J1402.1, J1404.1, R1403.2
unnamed: J1402.2, J1404.2, R1404.2
unnamed: R1409.2, R1410.1, U1401.1 (VFG)
unnamed: R1411.2, R1412.1, U1402.1 (VFG)
SPEAKER_AUDIO_LEFT: R1409.1, U1401.6 (VOUT); also elsewhere on the board
SPEAKER_AUDIO_RIGHT: R1411.1, U1402.6 (VOUT); also elsewhere on the board

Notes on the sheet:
Resistor divider = 21:1 attenuation Instrumentation amp gain = 1:2 Effective attenuation = 10.5:1

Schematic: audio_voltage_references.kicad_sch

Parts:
C1701, C1702, C1704: 0.1uF; C_0402; Voltage 50V; Digi-Key PN 1276-CL05B104KB5NNNCCT-ND
C1703, C1705: 1uF; C_0402; Voltage 10V; Digi-Key PN 490-18202-1-ND
R1701, R1702, R1703, R1704: 1k; R_0402; Tolerance 1%; Digi-Key PN 311-1.00KLRCT-ND
TP1701, TP1702: TP; Test_Point; Digi-Key PN 36-5005-ND
U1701: MCP6024; TSSOP-14_4.4x5mm_P0.65mm; Digi-Key PN MCP6024T-I/STCT-ND
U1702: REF35160QDBVR; SOT-23-6; Digi-Key PN 296-REF35160QDBVRCT-ND

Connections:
+1.6V_AREF_LEFT: TP1701.1 (TP_1), U1701.1, U1701.2 (-); also elsewhere on the board
+1.6V_AREF_RIGHT: TP1702.1 (TP_1), U1701.6 (-), U1701.7; also elsewhere on the board
+3.3V: C1701.1, C1704.1, C1705.1, R1701.1, R1703.1, U1701.4 (V+), U1702.4 (VIN); also elsewhere on the board
AUDIO_CHAIN_ENABLE: U1702.3 (EN); also elsewhere on the board
GND: C1701.2, C1702.2, C1703.2, C1704.2, C1705.2, R1702.2, R1704.2, U1701.11 (V-), U1702.1 (GND), U1702.2 (GND); also elsewhere on the board
unnamed: C1703.1, U1701.3 (+), U1701.5 (+), U1702.6 (VREF)
unnamed: R1701.2, R1702.1, U1701.10 (+)
unnamed: U1701.8, U1701.9 (-)
unnamed: R1703.2, R1704.1, U1701.12 (+)
unnamed: U1701.13 (-), U1701.14
unnamed: C1702.1, U1702.5 (NR)

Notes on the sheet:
Op amp buffering is needed for sinking and sourcing currents on the reference nets. The REF35160 gets us accuracy, the op amps get us drive strength

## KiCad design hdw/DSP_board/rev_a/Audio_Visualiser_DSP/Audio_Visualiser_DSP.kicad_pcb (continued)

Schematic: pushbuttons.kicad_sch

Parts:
C1901: 10nF; C_0402; Voltage 50V; Digi-Key PN 490-4516-1-ND; not fitted
C1902, C1906: 0.1uF; C_0402; Voltage 50V; Digi-Key PN 445-5942-1-ND; not fitted
C1903: 1uF; C_0402; Voltage 10V; Digi-Key PN 490-18202-1-ND
C1904: 0.1uF; C_0402; Voltage 50V; Digi-Key PN 1276-CL05B104KB5NNNCCT-ND
C1905: 10uF; C_0402; Voltage 10V; Digi-Key PN 1276-CL05A106MP6NUN8CT-ND; not fitted
DOC1901: 0x36
J1901: Power; TerminalBlock_Phoenix_MKDS-1,5-2-5.08_1x02_P5.08mm_Horizont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; Digi-Key PN 277-1247-ND; not fitted
J1903: Conn_01x06; PinSocket_1x06_P2.54mm_Vertical; Digi-Key PN 35-PRPC003DAAN-RC-ND
N1901: Adafruit Rotary Encoder Module; Digi-Key PN 1528-5880-ND
R1901, R1902: 1k; R_0402; Tolerance 1%; Digi-Key PN 311-1.00KLRCT-ND; not fitted
R1903: 0; R_0402; Tolerance 1%; Digi-Key PN 311-0.0LRCT-ND; not fitted
R1904, R1907: 10k; R_0402; Tolerance 1%; Digi-Key PN 311-10.0KLRCT-ND
R1905, R1906, R1909: 10k; R_0402; Tolerance 1%; Digi-Key PN 311-10.0KLRCT-ND; not fitted
R1908, R1910: 0; R_0402; Tolerance 1%; Digi-Key PN 311-0.0LRCT-ND
SW1901: Cap_Touch; Capacitive_Touch_Pad
SW1902: Power; SW_PUSH_6mm; Digi-Key PN 450-1650-ND
U1901: AT42QT1010-TSHR; SOT-23-6_Legacy; Digi-Key PN AT42QT1010-TSHRCT-ND; not fitted
U1902: 74LVC1G97; SOT-363_SC-70-6; Digi-Key PN 296-15582-1-ND
U1903: 74LVC1G97; SOT-363_SC-70-6; Digi-Key PN 296-15582-1-ND; not fitted

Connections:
+3.3V: C1902.1, C1904.1, C1906.1, J1903.1, R1904.1, U1901.5 (VDD), U1901.6 (SYNC), U1902.1 (VCC), U1902.5 (VCC), U1903.5 (VCC); also elsewhere on the board
ENCODER_INT: J1903.6; also elsewhere on the board
GND: C1902.2, C1903.2, C1904.2, C1905.2, C1906.2, J1901.2, J1903.3, R1905.2, R1907.2, R1909.2, SW1902.1, U1901.2 (VSS), U1902.2 (GND), U1902.3 (GND), U1903.2 (GND), U1903.3 (GND), U1903.6 (GND); also elsewhere on the board
I2C_SCL: J1903.4; also elsewhere on the board
I2C_SDA: J1903.5; also elsewhere on the board
unnamed: C1903.1, R1904.2, R1910.2, SW1902.2, U1902.6
unnamed: C1905.1, R1906.1, U1903.1
unnamed: J1901.1, R1901.1, R1902.1, R1903.1, R1910.1, SW1901.1 (TP_1)
unnamed: R1907.1, R1908.1, U1902.4
unnamed: R1905.1, R1906.2, U1901.1 (OUT)
unnamed: C1901.1, U1901.4 (SNS)
unnamed: C1901.2, R1901.2, R1902.2, U1901.3 (SNSK)
POWER_BUTTON: R1903.2, R1908.2, R1909.1, U1903.4; also elsewhere on the board

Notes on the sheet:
Configuration = mechanical_power_button

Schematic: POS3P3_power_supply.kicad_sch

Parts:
C401, C405: 0.1uF; C_0402; Voltage 50V; Digi-Key PN 1276-CL05B104KB5NNNCCT-ND
C402, C403: 10uF; C_1206; Voltage 25V; Digi-Key PN 445-6862-1-ND
C404: 10nF; C_0402; Voltage 50V; Digi-Key PN 490-4516-1-ND
C406, C407, C408: 10uF; C_0805; Voltage 10V; Digi-Key PN 478-KGM21AR71A106KUCT-ND
D401: BAT43WS; D_SOD-323F; Digi-Key PN BAT43WSRRGCT-ND
L401: 2.2uH; L_Vishay_IHLP-1212; Tolerance 20%; Digi-Key PN 541-IHLP1212BZEV2R2M01CT-ND
Q401, Q402: BSS214NW; SOT-323_SC-70; Digi-Key PN BSS214NWH6327XTSA1CT-ND
R401, R402, R408: 10k; R_0402; Tolerance 1%; Digi-Key PN 311-10.0KLRCT-ND
R403: 0; R_0402; Tolerance 1%; Digi-Key PN 311-0.0LRCT-ND
R404, R407: 10; R_0402; Tolerance 1%; Digi-Key PN 311-10.0LRCT-ND; not fitted
R405: 0; R_0402; Tolerance 1%; Digi-Key PN 311-0.0LRCT-ND; not fitted
R406: 0.02; R_0612; Tolerance 1%; Digi-Key PN P16010CT-ND
R409: 3.16k; R_0402; Tolerance 1%; Digi-Key PN YAG3146CT-ND
R410: 1k; R_0402; Tolerance 1%; Digi-Key PN 311-1.00KLRCT-ND
R411: 549; R_0402; Tolerance 1%; Digi-Key PN 311-549LRCT-ND
TP401: TP; Test_Point
U401: 74LVC1G97; SOT-363_SC-70-6; Digi-Key PN 296-15582-1-ND
U402: TPS62150A; QFN-16-1EP_3x3mm_P0.5mm_EP1.75x1.75mm; Digi-Key PN 296-41757-1-ND

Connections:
+3.3V: C401.1, D401.2 (A), R402.1, R406.2, R407.2, R409.1, R411.1, TP401.1 (TP_1), U401.5 (VCC), U402.14 (VOS); also elsewhere on the board
+12V: C402.1, C403.1, C405.1, U402.10 (AVIN), U402.11 (PVIN), U402.12 (PVIN); also elsewhere on the board
GND: C401.2, C402.2, C403.2, C404.2, C405.2, C406.2, C407.2, C408.2, Q401.2 (S), Q402.2 (S), R401.2, R405.2, R410.2, U401.1 (GND), U401.2 (GND), U402.6 (AGND), U402.7 (FSW), U402.8 (DEF), U402.15 (PGND), U402.16 (PGND), U402.17 (EP); also elsewhere on the board
unnamed: C406.1, C407.1, L401.2, R404.2, R406.1
unnamed: C408.1, D401.1 (K), R408.1
unnamed: L401.1, U402.1 (SW), U402.2 (SW), U402.3 (SW)
unnamed: Q401.3 (D), Q402.1 (G), R408.2
unnamed: Q402.3 (D), R411.2
unnamed: R405.1, R409.2, R410.1, U402.5 (FB)
unnamed: R402.2, U401.6, U402.4 (PG)
unnamed: C404.1, U402.9 (SS/TR)
POS3P3_PGOOD: R401.1, U401.4; also elsewhere on the board
POS3P3_RUN: Q401.1 (G), R403.2, U401.3, U402.13 (EN)
POS3P3_SNS+: R404.1; also elsewhere on the board
POS3P3_SNS-: R407.1; also elsewhere on the board
POS12_PGOOD: R403.1; also elsewhere on the board

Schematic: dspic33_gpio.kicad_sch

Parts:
C801, C802, C803, C804, C805: 0.1uF; C_0402; Voltage 50V; Digi-Key PN 1276-CL05B104KB5NNNCCT-ND
DOC801: 0x41
H801: Jumper_Shunt; Digi-Key PN S9337-ND
J801: Boot Audio Source Select; PinHeader_1x03_P2.54mm_Vertical; Digi-Key PN 35-PRPC003SAAN-RC-ND
R801, R807: 10k; R_0402; Tolerance 1%; Digi-Key PN 311-10.0KLRCT-ND
R802, R804: 10k; R_0402; Tolerance 1%; Digi-Key PN 311-10.0KLRCT-ND; not fitted
R803, R805, R806: 0; R_0402; Tolerance 1%; Digi-Key PN 311-0.0LRCT-ND; not fitted
U701: dsPIC33AK256MPS105; VQFN-48-1EP_6x6mm_P0.4mm_EP4.1x4.1mm; Digi-Key PN 150-DSPIC33AK256MPS105-I/M7-ND
U801: PCA9536DP; TSSOP-8_3x3mm_P0.65mm; Digi-Key PN 568-1836-1-ND
U802, U805: 74LVC1G97; SOT-363_SC-70-6; Digi-Key PN 296-15582-1-ND
U803: TCA9801; VSSOP-8_3x3mm_P0.65mm; Digi-Key PN 296-47828-1-ND

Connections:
+1.6V_AREF_LEFT: U701.9 (RA3/RP4/CMP1C/CMPCN/CVDAN3/AD1AN2/AD1AN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); also elsewhere on the board
+1.6V_AREF_RIGHT: U701.17 (RB1/RP18/CMP2C/CVDTX1/CVDAN17/AD2AN2/AD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); also elsewhere on the board
+3.3V: C801.1, C802.1, C803.1, C804.1, C805.1, R802.1, R804.1, U801.8 (VDD), U802.1 (VCC), U802.5 (VCC), U803.1 (VCCA), U803.8 (VCCB), U805.5 (VCC); also elsewhere on the board
ADC_AUDIO_LEFT: U701.10 (RA4/RP5/CMP1B/CVDAN4/AD3AN4/AD2AN5/AD1A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); also elsewhere on the board
ADC_AUDIO_RIGHT: U701.18 (RB2/RP19/CMP2B/CVDTX2/CVDAN18/AD2AN1/OA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); also elsewhere on the board
AUDIO_CHAIN_ENABLE: R807.1, U805.4; also elsewhere on the board
AUDIO_SOURCE_SELECT: U701.8 (RA2/RP3/CMP1A/CVDAN2/AD1AN0/OA1OUT); also elsewhere on the board
DSPIC33_ICSPCLK: R802.2, U701.22 (RB4/SCL1/RP21/CMP4B/CVDTX4/CVDAN20/AD2A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), U803.2 (SCLA); also elsewhere on the board
DSPIC33_ICSPDAT: R804.2, U701.21 (RB3/SDA1/RP20/CMP4A/CVDTX3/CVDAN19/AD2A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), U803.3 (SDAA); also elsewhere on the board
DSPIC33_POSC_EC: U701.30 (OSCI/RP34/IOMAF6/RC1); also elsewhere on the board
DSPIC33_REFCLK1: U701.23 (RB6/I3CASCL1/RP23/ISRC0/IBIAS0/ALLCMP/C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); also elsewhere on the board
DSPIC_AUDIO_CHAIN_ENABLE: U701.4 (RA8/RP9/ISRC3/IBIAS3/CMP5A/CVDAN8/AD3AN3), U805.1
ENCODER_INT: U701.25 (RP39/ASCL1/RC6); also elsewhere on the board
ERROR_LED: U701.3 (RA1/RP2/CMP4D/CVDAN1/AD3AN0/AD3ANN1/DAC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); also elsewhere on the board
GND: C801.2, C802.2, C803.2, C804.2, C805.2, J801.2, R801.2, R803.2, R805.2, R806.2, R807.2, U801.4 (VSS), U802.2 (GND), U802.3 (GND), U803.4 (GND), U805.2 (GND), U805.3 (GND), U805.6 (GND); also elsewhere on the board
HEARTBEAT_LED: U701.34 (RP37/I3CSDA1/PWM3L/IOMAD4/RC4); also elsewhere on the board
I2C_EN: R801.1, U802.4, U803.5 (EN)
I2C_SCL: U801.6 (SCL), U803.7 (SCLB); also elsewhere on the board
I2C_SDA: U801.7 (SDA), U803.6 (SDAB); also elsewhere on the board
LED_DRIVER_BLANK_PWM: U701.33 (RP36/PWM3H/IOMAD5/RC3); also elsewhere on the board
LED_DRIVER_LAT: U701.32 (PGD3/RP38/I3CSCL1/PWM4L/IOMAD6/RC5); also elsewhere on the board
LED_POS3P3_RUN: U701.20 (RB9/RP26/CVDTX9/CVDAN25); also elsewhere on the board
LEFT_LED_DRIVER_SPI_SCK: U701.37 (RP49/PWM2H/IOMAD3/RD0); also elsewhere on the board
LEFT_LED_DRIVER_SPI_SDO: U701.38 (TCK/RP50/PWM2L/IOMAD2/RD1); also elsewhere on the board
LEFT_LED_POS3P3_PGOOD: U701.13 (RB5/RP22/CMP3B/CVDTX5/CVDAN21/OA3IN+); also elsewhere on the board
LEFT_VLED_PGOOD: U701.12 (RA6/RP7/CMP3C/CMPDN/CVDAN6/OA3IN-); also elsewhere on the board
unnamed: J801.3, U801.5 (IO3)
unnamed: R803.1, U801.1 (IO0)
unnamed: R805.1, U801.2 (IO1)
unnamed: R806.1, U801.3 (IO2)
PGOOD_LED_SHDN: U701.47 (RP55/RD6); also elsewhere on the board
POS3P3_PGOOD: U701.16 (RB0/RP17/CMP2A/CVDTX0/CVDAN16/AD2AN0/OA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); also elsewhere on the board
POS12_PGOOD: U701.26 (RP40/ASDA1/IOMAF7/RC7); also elsewhere on the board
POWER_BUTTON: U701.11 (RA5/INT0/RP6/CMP3A/CVDAN5/OA3OUT); also elsewhere on the board
RIGHT_LED_DRIVER_SPI_SCK: U701.39 (TDO/RP51/PWM1H/IOMAD1/RD2); also elsewhere on the board
RIGHT_LED_DRIVER_SPI_SDO: U701.40 (TDI/RP52/PWM1L/IOMAD0/RD3); also elsewhere on the board
RIGHT_LED_POS3P3_PGOOD: U701.24 (RB7/IOMAF0/I3CASDA1/RP24/ISRC1/IBIAS1/C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); also elsewhere on the board
RIGHT_VLED_PGOOD: U701.5 (RA9/RP10/ISRC2/IBIAS2/CMP5B/CVDAN9/AD1A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); also elsewhere on the board
USB_UART_RX: U701.29 (OSCO/CLKO/RP33/IOMAF5/RC0); also elsewhere on the board
USB_UART_TX: U701.31 (PGC3/RP35/PWM4H/IOMAD7/RC2); also elsewhere on the board
VLED_RUN: U701.19 (RB8/RP25/CMP2D/CVDTX8/CVDAN24); also elsewhere on the board
~LED_BUF_OE: U701.2 (RA7/IOMAF1/SDA2/RP8/CVDAN7/AD3AN1); also elsewhere on the board
~RESET_LED: U701.1 (RA0/IOMAF2/SCL2/RP1/CVDAN0/AD1AN4/AD1AN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), U802.6; also elsewhere on the board

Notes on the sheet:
Pulled high when in reset via resistor on status LEDs page
SDA1/PGD1
RP50 = SDO1
RP51 = SCK2
RP36 = OCM2
RP23 = REFO1
AD1ANN2
Low when in reset
RP37 = OCM1
OSCI
Isolate I2C signals when in reset/being programmed so that ICSP can program the DSC but cannot spook I2C devices with nonsensical data
RP35 = U1TX
Internal 250k pullup to VCCB
CVDAN5/INT0
AD2ANN2
RP33 = U1RX
Internal 100k pullups
RP52 = SDO2
RP49 = SCK1
OA1IN+/AD1AN1
3.3mA current source on SCLB/SDAB No pulls allowed
RP39 = INT1
OA2IN+/AD2AN1
SCL1/PGC1
Enable internal pullups in firmware This keeps programming interface free when in reset

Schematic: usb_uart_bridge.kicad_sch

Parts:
C901, C904, C907, C908, C909: 0.1uF; C_0402; Voltage 50V; Digi-Key PN 1276-CL05B104KB5NNNCCT-ND
C902, C903, C905, C906, C910: 10uF; C_0402; Voltage 10V; Digi-Key PN 1276-CL05A106MP6NUN8CT-ND
C911: 10nF; C_0402; Voltage 50V; Digi-Key PN 490-4516-1-ND
D901: Yellow; LED_0402; Digi-Key PN 732-11993-1-ND
D902, D903: Green; LED_0402; Digi-Key PN 732-11992-1-ND
DOC901: COM_Port_Settings
FB901: 220; L_0402; Digi-Key PN 490-16508-1-ND
J901: USB_C_Receptacle_USB2.0_14P; USB_C_Receptacle_JAE_DX07S016JA1R1500; Digi-Key PN 670-DX07S016JA1R1500CT-ND
R901, R902, R906: 1k; R_0402; Tolerance 1%; Digi-Key PN 311-1.00KLRCT-ND
R903, R904, R907, R908: 100k; R_0402; Tolerance 1%; Digi-Key PN 311-100KLRCT-ND
R905, R909, R910: 5.1k; R_0402; Tolerance 1%; Digi-Key PN 311-5.10KLRCT-ND
R911: 1M; R_0402; Tolerance 1%; Digi-Key PN 311-1.00MLRCT-ND
TP901: TP; Test_Point
U901: CP2104; QFN-24-1EP_4x4mm_P0.5mm_EP2.65x2.65mm; Digi-Key PN 336-4146-1-ND
U902: 74LVC1G97; SOT-363_SC-70-6; Digi-Key PN 296-15582-1-ND
U903: TXB0102DCU; VSSOP-8_2.3x2mm_P0.5mm; Digi-Key PN 296-22862-1-ND
U904: TPD3S014DBVR; SOT-23-6_Legacy; Digi-Key PN 296-38835-1-ND

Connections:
+3.3V: C904.1, C905.1, R903.1, R904.1, U903.7 (VCCB); also elsewhere on the board
+3.3V_USB: C901.1, C902.1, C907.1, C909.1, C910.1, R901.1, R902.1, R905.1, R906.1, R907.1, R908.1, U901.5 (VIO), U901.6 (VDD), U902.1 (VCC), U902.5 (VCC), U903.3 (VCCA)
+5V_USB: C903.1, C908.1, TP901.1 (TP_1), U901.7 (REGIN), U901.8 (VBUS), U904.4 (OUT)
/USB UART Bridge/USB_BRIDGE_D+: J901.A6 (D+), J901.B6 (D+), U901.3 (D+), U904.5 (D1)
/USB UART Bridge/USB_BRIDGE_D-: J901.A7 (D-), J901.B7 (D-), U901.4 (D-), U904.6 (D2)
CHGND: C911.1, J901.SH (SHIELD), R911.1
GND: C901.2, C902.2, C903.2, C904.2, C905.2, C906.2, C907.2, C908.2, C909.2, C910.2, C911.2, J901.A1 (GND), J901.A12 (GND), J901.B1 (GND), J901.B12 (GND), R909.2, R910.2, R911.2, U901.2 (GND), U901.25 (GND), U902.2 (GND), U902.3 (GND), U903.2 (GND), U904.2 (GND); also elsewhere on the board
unnamed: D901.2 (A), R901.2
unnamed: D902.2 (A), R902.2
unnamed: D903.2 (A), R906.2
unnamed: D903.1 (K), U902.4
unnamed: FB901.2, J901.A4 (VBUS), J901.A9 (VBUS), J901.B4 (VBUS), J901.B9 (VBUS)
unnamed: J901.A5 (CC1), R909.1
unnamed: J901.B5 (CC2), R910.1
unnamed: C906.1, U901.16 (VPP)
unnamed: FB901.1, U904.1 (EN), U904.3 (IN)
USB_UART_RX: R904.2, U903.8 (B1); also elsewhere on the board
USB_UART_RX_BRIDGE: R907.2, U901.21 (TXD), U903.5 (A1)
USB_UART_TX: R903.2, U903.1 (B2); also elsewhere on the board
USB_UART_TX_BRIDGE: R908.2, U901.20 (RXD), U903.4 (A2)
~USB_BRIDGE_RESET: R905.2, U901.9 (~RST), U902.6, U903.6 (OE)
~USB_BRIDGE_RX: D901.1 (K), U901.13 (RXT/GPIO.1)
~USB_BRIDGE_TX: D902.1 (K), U901.14 (TXT/GPIO.0)

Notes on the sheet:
REGIN
VDD
VIO
Datasheet gives conflicting rules Says VCCB > VCCA, but says outputs go HiZ when either supply is not up

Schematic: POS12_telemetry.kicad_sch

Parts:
C301, C302, C303: 0.1uF; C_0402; Voltage 50V; Digi-Key PN 1276-CL05B104KB5NNNCCT-ND; not fitted
DOC301: 0x40
DOC302: 0x18
U301: INA231A; Texas_DSBGA-12_1.65x1.39mm_Layout3x4_P0.4mm; Digi-Key PN 296-41263-1-ND; not fitted
U302: MCP9804; DFN-8-1EP_3x2mm_P0.5mm_EP1.3x1.5mm; Digi-Key PN MCP9804T-E/MCCT-ND; not fitted

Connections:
+3.3V: C302.1, C303.1, U301.B1 (VS), U302.8 (V_{DD}); also elsewhere on the board
+12V: U301.D1 (BUS); also elsewhere on the board
GND: C302.2, C303.2, U301.B3 (A0), U301.C1 (GND), U301.C3 (A1), U302.4 (GND), U302.5 (A2), U302.6 (A1), U302.7 (A0), U302.9 (EP/GND); also elsewhere on the board
I2C_SCL: U301.A1 (SCL), U302.2 (SCL); also elsewhere on the board
I2C_SDA: U301.A2 (SDA), U302.1 (SDA); also elsewhere on the board
POS12_SNS+: C301.1, U301.D3 (IN+); also elsewhere on the board
POS12_SNS-: C301.2, U301.D2 (IN-); also elsewhere on the board

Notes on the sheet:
Max Current = 8.192A RSHUNT = 0.01 Ohm CLSB = 2.5E-04 A CAL Register = 0x0800

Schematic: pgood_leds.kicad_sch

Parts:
C1101, C1102, C1103, C1104, C1105, C1106: 0.1uF; C_0402; Voltage 50V; Digi-Key PN 1276-CL05B104KB5NNNCCT-ND
D1101, D1102, D1103, D1104, D1105, D1106: Green; LED_0402; Digi-Key PN 732-11992-1-ND
R1101: 10k; R_0402; Tolerance 1%; Digi-Key PN 311-10.0KLRCT-ND
R1102, R1103, R1104, R1105, R1106, R1107: 1k; R_0402; Tolerance 1%; Digi-Key PN 311-1.00KLRCT-ND
U1101, U1102, U1103, U1104, U1105, U1106: 74LVC1G97; SOT-363_SC-70-6; Digi-Key PN 296-15582-1-ND

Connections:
+3.3V: C1101.1, C1102.1, C1103.1, C1104.1, C1105.1, C1106.1, R1102.1, R1103.1, R1104.1, R1105.1, R1106.1, R1107.1, U1101.1 (VCC), U1101.5 (VCC), U1102.1 (VCC), U1102.5 (VCC), U1103.1 (VCC), U1103.5 (VCC), U1104.1 (VCC), U1104.5 (VCC), U1105.1 (VCC), U1105.5 (VCC), U1106.1 (VCC), U1106.5 (VCC); also elsewhere on the board
GND: C1101.2, C1102.2, C1103.2, C1104.2, C1105.2, C1106.2, R1101.2, U1101.2 (GND), U1102.2 (GND), U1103.2 (GND), U1104.2 (GND), U1105.2 (GND), U1106.2 (GND); also elsewhere on the board
LEFT_LED_POS3P3_PGOOD: U1102.6; also elsewhere on the board
LEFT_VLED_PGOOD: U1105.6; also elsewhere on the board
unnamed: D1101.2 (A), R1102.2
unnamed: D1101.1 (K), U1101.4
unnamed: D1102.2 (A), R1103.2
unnamed: D1102.1 (K), U1102.4
unnamed: D1103.2 (A), R1104.2
unnamed: D1103.1 (K), U1103.4
unnamed: D1104.2 (A), R1105.2
unnamed: D1104.1 (K), U1104.4
unnamed: D1105.2 (A), R1106.2
unnamed: D1105.1 (K), U1105.4
unnamed: D1106.2 (A), R1107.2
unnamed: D1106.1 (K), U1106.4
PGOOD_LED_SHDN: R1101.1, U1101.3, U1102.3, U1103.3, U1104.3, U1105.3, U1106.3; also elsewhere on the board
POS3P3_PGOOD: U1104.6; also elsewhere on the board
POS12_PGOOD: U1101.6; also elsewhere on the board
RIGHT_LED_POS3P3_PGOOD: U1103.6; also elsewhere on the board
RIGHT_VLED_PGOOD: U1106.6; also elsewhere on the board

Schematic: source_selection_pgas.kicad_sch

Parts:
C1501, C1503, C1505: 0.1uF; C_0402; Voltage 50V; Digi-Key PN 1276-CL05B104KB5NNNCCT-ND
C1502, C1504, C1506: 1uF; C_0402; Voltage 10V; Digi-Key PN 490-18202-1-ND
DOC1501: 0x2C
J1501: Gain Left TP; dual_tp_no_silk; not fitted
J1502: Gain Right TP; dual_tp_no_silk; not fitted
J1503: Mux Left TP; dual_tp_no_silk; not fitted
J1504: Mux Right TP; dual_tp_no_silk; not fitted
R1501: 10k; R_0402; Tolerance 1%; Digi-Key PN 311-10.0KLRCT-ND
R1502, R1503: 1k; R_0402; Tolerance 1%; Digi-Key PN 311-1.00KLRCT-ND
U1501: TS3A24159DRC; Texas_S-PVSON-N10; Digi-Key PN 296-21914-1-ND
U1502: MCP6024; TSSOP-14_4.4x5mm_P0.65mm; Digi-Key PN MCP6024T-I/STCT-ND
U1503: MCP4451-103E/ML; QFN-20-1EP_4x4mm_P0.5mm_EP2.7x2.7mm; Digi-Key PN MCP4451-103E/ML-ND

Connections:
+1.6V_AREF_LEFT: U1502.12 (+); also elsewhere on the board
+1.6V_AREF_RIGHT: U1502.10 (+); also elsewhere on the board
+3.3V: C1501.1, C1502.1, C1503.1, C1504.1, C1505.1, C1506.1, U1501.1 (VCC), U1502.4 (V+), U1503.15 (VDD); also elsewhere on the board
AUDIO_CHAIN_ENABLE: U1503.13 (~RESET); also elsewhere on the board
AUDIO_SOURCE_SELECT: R1501.1, U1501.4, U1501.8; also elsewhere on the board
GAIN_AUDIO_LEFT: J1501.1, U1502.14, U1503.16 (P2B); also elsewhere on the board
GAIN_AUDIO_RIGHT: J1502.1, U1502.8, U1503.1 (P3B); also elsewhere on the board
GND: C1501.2, C1502.2, C1503.2, C1504.2, C1505.2, C1506.2, J1501.2, J1502.2, J1503.2, J1504.2, R1501.2, U1501.6 (GND), U1501.11 (PAD), U1502.11 (V-), U1503.2 (HVC/A0), U1503.5 (VSS), U1503.6 (P1B), U1503.7 (P1W), U1503.8 (P1A), U1503.9 (P0A), U1503.10 (P0W), U1503.11 (P0B), U1503.14 (A1), U1503.21 (EP); also elsewhere on the board
I2C_SCL: U1503.3 (SCL); also elsewhere on the board
I2C_SDA: U1503.4 (SDA); also elsewhere on the board
unnamed: J1503.1, U1501.3, U1502.3 (+)
unnamed: J1504.1, U1501.9, U1502.5 (+)
unnamed: R1502.2, U1502.1, U1502.2 (-)
unnamed: R1503.2, U1502.6 (-), U1502.7
unnamed: U1502.9 (-), U1503.20 (P3W)
unnamed: U1502.13 (-), U1503.17 (P2W)
unnamed: R1502.1, U1503.18 (P2A)
unnamed: R1503.1, U1503.19 (P3A)
RCA_AUDIO_LEFT: U1501.5; also elsewhere on the board
RCA_AUDIO_RIGHT: U1501.7; also elsewhere on the board
SPEAKER_AUDIO_LEFT: U1501.2; also elsewhere on the board
SPEAKER_AUDIO_RIGHT: U1501.10; also elsewhere on the board

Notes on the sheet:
Audio source selection analog switches
Inverting op amps with adjustable gain/attenuation
High = Speaker Low = RCA
This digipot can both attenuate and amplify depending on setting At reset, wiper is midpoint, so Av = 1
Inverted

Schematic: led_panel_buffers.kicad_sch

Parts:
C1801, C1802, C1803, C1804, C1805, C1806, C1807, C1808, C1809, C1810, C1811: 0.1uF; C_0402; Voltage 50V; Digi-Key PN 1276-CL05B104KB5NNNCCT-ND
R1801, R1802, R1803, R1804, R1805: 10k; R_0402; Tolerance 1%; Digi-Key PN 311-10.0KLRCT-ND
RN1801, RN1802, RN1803, RN1804: 10k; R_Array_Convex_8x0602; Digi-Key PN Y1103CT-ND
U1801, U1802, U1805, U1806, U1808: 74LVC1G97; SOT-363_SC-70-6; Digi-Key PN 296-15582-1-ND
U1803, U1804: 74VHC541BQ,115; DHVQFN-20-1EP_2.5x4.5mm_P0.5mm_EP1x3mm; Digi-Key PN 1727-7068-1-ND
U1807, U1809: TCA9801; VSSOP-8_3x3mm_P0.65mm; Digi-Key PN 296-47828-1-ND

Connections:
+3.3V: C1801.1, C1802.1, C1803.1, C1804.1, C1805.1, C1806.1, C1807.1, C1808.1, C1809.1, C1810.1, C1811.1, RN1801.8 (R8.1), RN1802.8 (R8.1), U1801.5 (VCC), U1802.5 (VCC), U1803.20 (VCC), U1804.20 (VCC), U1805.5 (VCC), U1806.5 (VCC), U1807.1 (VCCA), U1807.8 (VCCB), U1808.1 (VCC), U1808.5 (VCC), U1809.1 (VCCA), U1809.8 (VCCB); also elsewhere on the board
GND: C1801.2, C1802.2, C1803.2, C1804.2, C1805.2, C1806.2, C1807.2, C1808.2, C1809.2, C1810.2, C1811.2, R1801.2, R1802.2, R1803.2, R1804.2, R1805.2, RN1801.1 (R1.1), RN1801.2 (R2.1), RN1801.3 (R3.1), RN1801.4 (R4.1), RN1801.5 (R5.1), RN1801.6 (R6.1), RN1801.7 (R7.1), RN1802.1 (R1.1), RN1802.2 (R2.1), RN1802.3 (R3.1), RN1802.4 (R4.1), RN1802.5 (R5.1), RN1802.6 (R6.1), RN1802.7 (R7.1), RN1803.1 (R1.1), RN1803.2 (R2.1), RN1803.3 (R3.1), RN1803.4 (R4.1), RN1803.5 (R5.1), RN1803.6 (R6.1), RN1803.7 (R7.1), RN1803.8 (R8.1), RN1804.1 (R1.1), RN1804.2 (R2.1), RN1804.3 (R3.1), RN1804.4 (R4.1), RN1804.5 (R5.1), RN1804.6 (R6.1), RN1804.7 (R7.1), RN1804.8 (R8.1), U1801.2 (GND), U1801.3 (GND), U1802.2 (GND), U1802.3 (GND), U1803.10 (GND), U1803.21 (GND), U1804.10 (GND), U1804.21 (GND), U1805.2 (GND), U1805.3 (GND), U1806.2 (GND), U1806.3 (GND), U1807.4 (GND), U1808.2 (GND), U1808.3 (GND), U1809.4 (GND); also elsewhere on the board
I2C_SCL: U1807.2 (SCLA), U1809.2 (SCLA); also elsewhere on the board
I2C_SDA: U1807.3 (SDAA), U1809.3 (SDAA); also elsewhere on the board
LED_BUF_OE: R1805.1, U1807.5 (EN), U1808.4, U1809.5 (EN)
LED_DRIVER_BLANK_PWM: RN1801.14 (R3.2), RN1802.14 (R3.2), U1803.4 (A2), U1804.4 (A2); also elsewhere on the board
LED_DRIVER_LAT: RN1801.13 (R4.2), RN1802.13 (R4.2), U1803.5 (A3), U1804.5 (A3); also elsewhere on the board
LED_POS3P3_RUN: RN1801.11 (R6.2), RN1802.11 (R6.2), U1803.7 (A5), U1804.7 (A5); also elsewhere on the board
LEFT_I2C_SCL: U1807.7 (SCLB); also elsewhere on the board
LEFT_I2C_SDA: U1807.6 (SDAB); also elsewhere on the board
LEFT_LED_DRIVER_BLANK_PWM_BUF: RN1803.11 (R6.2), U1803.16 (Y2); also elsewhere on the board
LEFT_LED_DRIVER_LAT_BUF: RN1803.12 (R5.2), U1803.15 (Y3); also elsewhere on the board
LEFT_LED_DRIVER_SPI_SCK: RN1801.16 (R1.2), U1803.2 (A0); also elsewhere on the board
LEFT_LED_DRIVER_SPI_SCK_BUF: RN1803.9 (R8.2), U1803.18 (Y0); also elsewhere on the board
LEFT_LED_DRIVER_SPI_SDO: RN1801.15 (R2.2), U1803.3 (A1); also elsewhere on the board
LEFT_LED_DRIVER_SPI_SDO_BUF: RN1803.10 (R7.2), U1803.17 (Y1); also elsewhere on the board
LEFT_LED_POS3P3_PGOOD: R1801.1, U1801.4; also elsewhere on the board
LEFT_LED_POS3P3_PGOOD_BUF: U1801.1; also elsewhere on the board
LEFT_LED_POS3P3_RUN_BUF: RN1803.14 (R3.2), U1803.13 (Y5); also elsewhere on the board
LEFT_VLED_PGOOD: R1803.1, U1805.4; also elsewhere on the board
LEFT_VLED_PGOOD_BUF: U1805.1; also elsewhere on the board
LEFT_VLED_RUN_BUF: RN1803.13 (R4.2), U1803.14 (Y4); also elsewhere on the board
unnamed: RN1801.10 (R7.2), U1803.8 (A6), U1803.9 (A7)
unnamed: RN1802.10 (R7.2), U1804.8 (A6), U1804.9 (A7)
unnamed: RN1803.16 (R1.2), U1803.11 (Y7)
unnamed: RN1803.15 (R2.2), U1803.12 (Y6)
unnamed: RN1804.16 (R1.2), U1804.11 (Y7)
unnamed: RN1804.15 (R2.2), U1804.12 (Y6)
RIGHT_I2C_SCL: U1809.7 (SCLB); also elsewhere on the board
RIGHT_I2C_SDA: U1809.6 (SDAB); also elsewhere on the board
RIGHT_LED_DRIVER_BLANK_PWM_BUF: RN1804.11 (R6.2), U1804.16 (Y2); also elsewhere on the board
RIGHT_LED_DRIVER_LAT_BUF: RN1804.12 (R5.2), U1804.15 (Y3); also elsewhere on the board
RIGHT_LED_DRIVER_SPI_SCK: RN1802.16 (R1.2), U1804.2 (A0); also elsewhere on the board
RIGHT_LED_DRIVER_SPI_SCK_BUF: RN1804.9 (R8.2), U1804.18 (Y0); also elsewhere on the board
RIGHT_LED_DRIVER_SPI_SDO: RN1802.15 (R2.2), U1804.3 (A1); also elsewhere on the board
RIGHT_LED_DRIVER_SPI_SDO_BUF: RN1804.10 (R7.2), U1804.17 (Y1); also elsewhere on the board
RIGHT_LED_POS3P3_PGOOD: R1802.1, U1802.4; also elsewhere on the board
RIGHT_LED_POS3P3_PGOOD_BUF: U1802.1; also elsewhere on the board
RIGHT_LED_POS3P3_RUN_BUF: RN1804.14 (R3.2), U1804.13 (Y5); also elsewhere on the board
RIGHT_VLED_PGOOD: R1804.1, U1806.4; also elsewhere on the board
RIGHT_VLED_PGOOD_BUF: U1806.1; also elsewhere on the board
RIGHT_VLED_RUN_BUF: RN1804.13 (R4.2), U1804.14 (Y4); also elsewhere on the board
VLED_RUN: RN1801.12 (R5.2), RN1802.12 (R5.2), U1803.6 (A4), U1804.6 (A4); also elsewhere on the board
~LED_BUF_OE: RN1801.9 (R8.2), RN1802.9 (R8.2), U1801.6, U1802.6, U1803.1 (G1), U1803.19 (G2), U1804.1 (G1), U1804.19 (G2), U1805.6, U1806.6, U1808.6; also elsewhere on the board

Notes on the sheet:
3.3mA current source on SCLB/SDAB No pulls allowed
Internal 250k pullup to VCCB

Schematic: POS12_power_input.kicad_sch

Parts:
C201: 10nF; C_0402; Voltage 50V; Digi-Key PN 490-4516-1-ND
C202: 0.1uF; C_0402; Voltage 50V; Digi-Key PN 1276-CL05B104KB5NNNCCT-ND
C203: 100uF; CP_EIA-7343-43_Kemet-X; Voltage 25V; Tolerance 10%; Digi-Key PN 399-8410-1-ND
C204: 1000pF; C_0402; Voltage 50V; Digi-Key PN 490-6190-1-ND
D201: 24V; D_SMA; Digi-Key PN SMAJ24CALFCT-ND; not fitted
J201: +12V IN; SameSky_PJ-051AH; Digi-Key PN CP-051AH-ND
N201: +12V 5A Power Supply; Digi-Key PN 5942-YS50-1205000-D1J-C14-ND
R201: 1M; R_0402; Tolerance 1%; Digi-Key PN 311-1.00MLRCT-ND
R202: 33.2k; R_0402; Tolerance 1%; Digi-Key PN YAG5290CT-ND
R203: 97.6k; R_0402; Tolerance 1%; Digi-Key PN 311-97.6KLRCT-ND
R204: 100k; R_0402; Tolerance 1%; Digi-Key PN 311-100KLRCT-ND
R205, R210: 10; R_0402; Tolerance 1%; Digi-Key PN 311-10.0LRCT-ND; not fitted
R206: 13k; R_0402; Tolerance 1%; Digi-Key PN 311-13.0KLRCT-ND
R207: 0.01; R_0612; Tolerance 1%; Digi-Key PN 10-ERJ-B2CFR01VCT-ND
R208: 10k; R_0402; Tolerance 1%; Digi-Key PN 311-10.0KLRCT-ND
R209: 3.65k; R_0402; Tolerance 1%; Digi-Key PN 311-3.65KLRCT-ND
R211: 549; R_0402; Tolerance 1%; Digi-Key PN 311-549LRCT-ND
TP201: TP; PinHeader_1x01_P2.54mm_Horizontal
TP202, TP203: TP; Test_Point
U201: TPS259474LRPWR; Texas_RPW0010A_VQFN-HR-10_2x2mm_P0.45mm; Digi-Key PN 296-TPS259474LRPWRCT-ND

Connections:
+12V: C203.1, R207.2, R208.1, R210.2, TP203.1 (TP_1); also elsewhere on the board
+12Vin: C202.1, D201.1 (A1), J201.1, R201.1, TP202.1 (TP_1), U201.5 (IN)
GND: C201.2, C202.2, C203.2, C204.2, D201.2 (A2), J201.2, J201.3, R203.2, R206.2, R209.2, R211.2, TP201.1 (TP_1), U201.8 (GND); also elsewhere on the board
unnamed: R201.2, R202.1, U201.1 (EN/UVLO)
unnamed: R211.1, U201.9 (ILM)
unnamed: C204.1, U201.10 (ITIMER)
unnamed: R204.1, R205.2, R207.1, U201.6 (OUT)
unnamed: R202.2, R203.1, U201.2 (OVLO)
unnamed: R204.2, R206.1, U201.4 (PGTH)
unnamed: C201.1, U201.7 (dVdT)
POS12_PGOOD: R208.2, R209.1, U201.3 (PG); also elsewhere on the board
POS12_SNS+: R205.1; also elsewhere on the board
POS12_SNS-: R210.1; also elsewhere on the board

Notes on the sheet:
+3.58V output at +13.2Vin +3.21V output at +12.0Vin
UVLO threshold set to 10.37V rising, 9.4V falling OVLO threshold set to 13.9V rising, 12.6V falling Output ramp 60ms Current limit blanking time 0.84ms Output Current Limit set to 6.07A PGOOD threshold 10.43V rising, 9.5V falling

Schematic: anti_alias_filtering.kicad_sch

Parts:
C1601, C1602, C1607, C1608: 470pF; C_0402; Voltage 50V; Digi-Key PN 490-1297-1-ND
C1603, C1604, C1609, C1610: 1000pF; C_0402; Voltage 50V; Digi-Key PN 490-6190-1-ND
C1605: 0.1uF; C_0402; Voltage 50V; Digi-Key PN 1276-CL05B104KB5NNNCCT-ND
C1606: 1uF; C_0402; Voltage 10V; Digi-Key PN 490-18202-1-ND
J1601: ADC Left TP; dual_tp_no_silk; not fitted
J1602: ADC Right TP; dual_tp_no_silk; not fitted
R1601, R1602, R1603, R1604, R1605, R1606, R1607, R1608: 10k; R_0402; Tolerance 1%; Digi-Key PN 311-10.0KLRCT-ND
U1601: MCP6024; TSSOP-14_4.4x5mm_P0.65mm; Digi-Key PN MCP6024T-I/STCT-ND

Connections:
+3.3V: C1605.1, C1606.1, U1601.4 (V+); also elsewhere on the board
ADC_AUDIO_LEFT: C1609.2, J1601.1, U1601.13 (-), U1601.14; also elsewhere on the board
ADC_AUDIO_RIGHT: C1610.2, J1602.1, U1601.8, U1601.9 (-); also elsewhere on the board
GAIN_AUDIO_LEFT: R1601.2; also elsewhere on the board
GAIN_AUDIO_RIGHT: R1602.2; also elsewhere on the board
GND: C1601.2, C1602.2, C1605.2, C1606.2, C1607.2, C1608.2, J1601.2, J1602.2, U1601.11 (V-); also elsewhere on the board
unnamed: C1603.1, R1601.1, R1603.2
unnamed: C1604.1, R1602.1, R1604.2
unnamed: C1609.1, R1605.1, R1607.2
unnamed: C1610.1, R1606.1, R1608.2
unnamed: C1601.1, R1603.1, U1601.3 (+)
unnamed: C1603.2, R1605.2, U1601.1, U1601.2 (-)
unnamed: C1602.1, R1604.1, U1601.5 (+)
unnamed: C1604.2, R1606.2, U1601.6 (-), U1601.7
unnamed: C1608.1, R1608.1, U1601.10 (+)
unnamed: C1607.1, R1607.1, U1601.12 (+)

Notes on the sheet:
4-pole Sallen-Key active anti-aliasing lowpass filters Unity gain fc = 23.2kHz, Q = 0.707 each If sampling at 44.1kHz, nyquist is 22.05kHz Must filter hard around this frequency

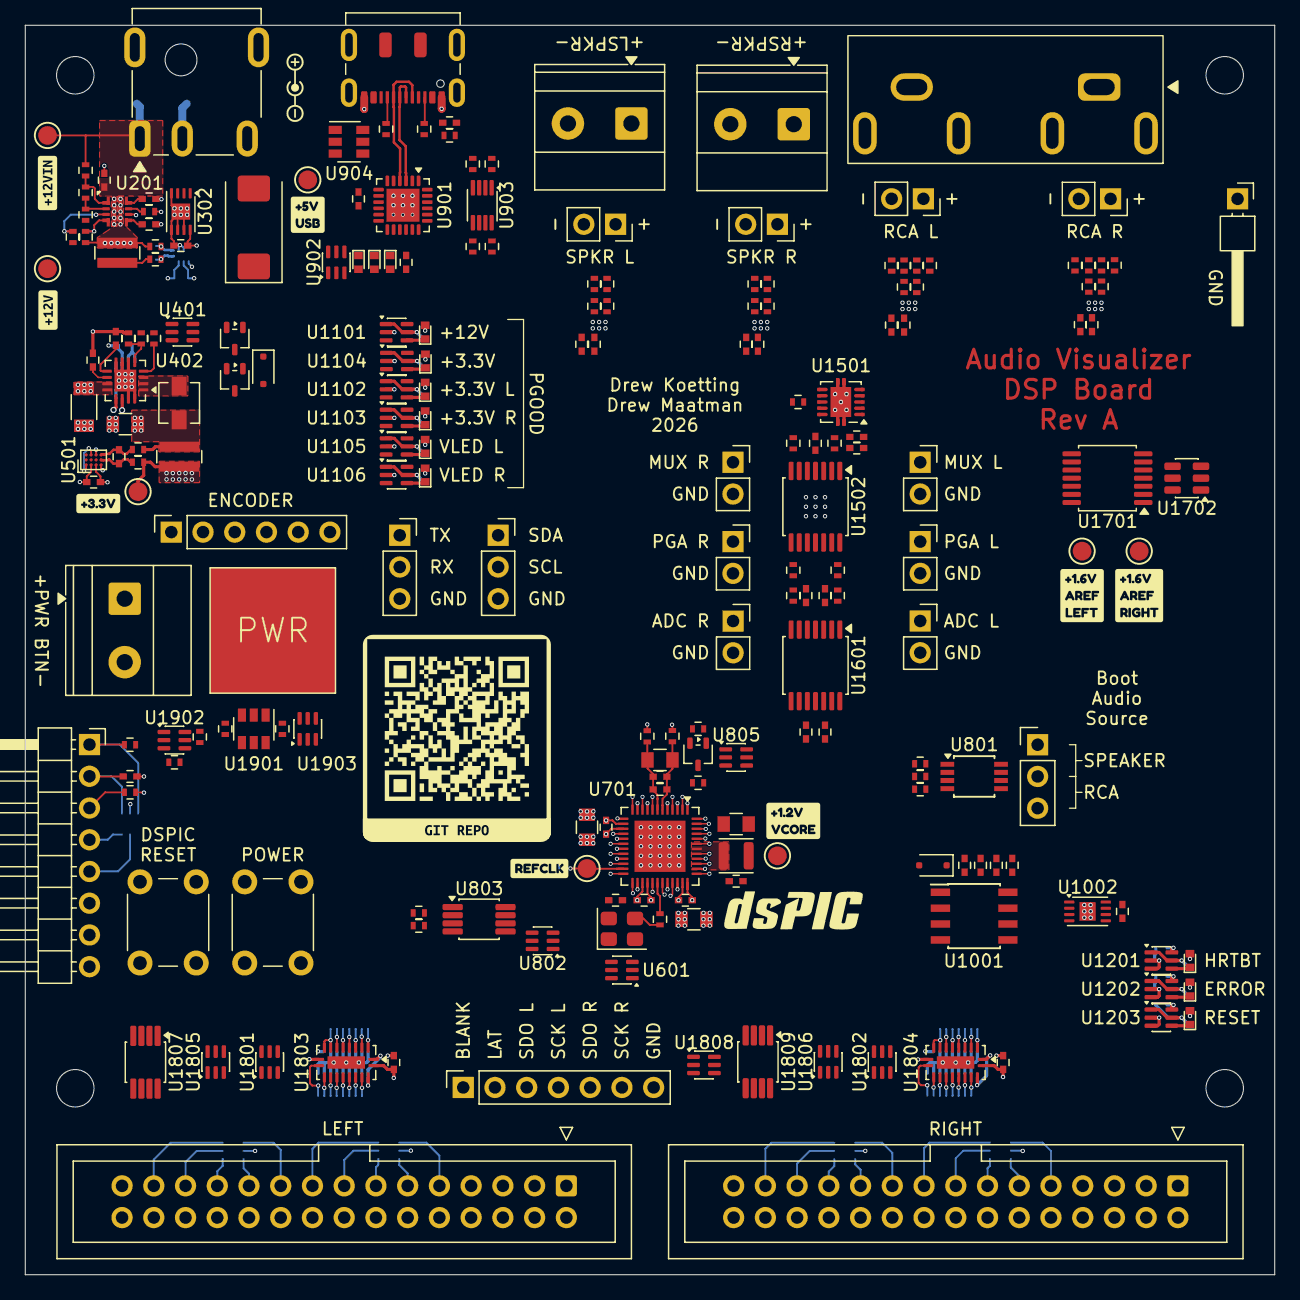
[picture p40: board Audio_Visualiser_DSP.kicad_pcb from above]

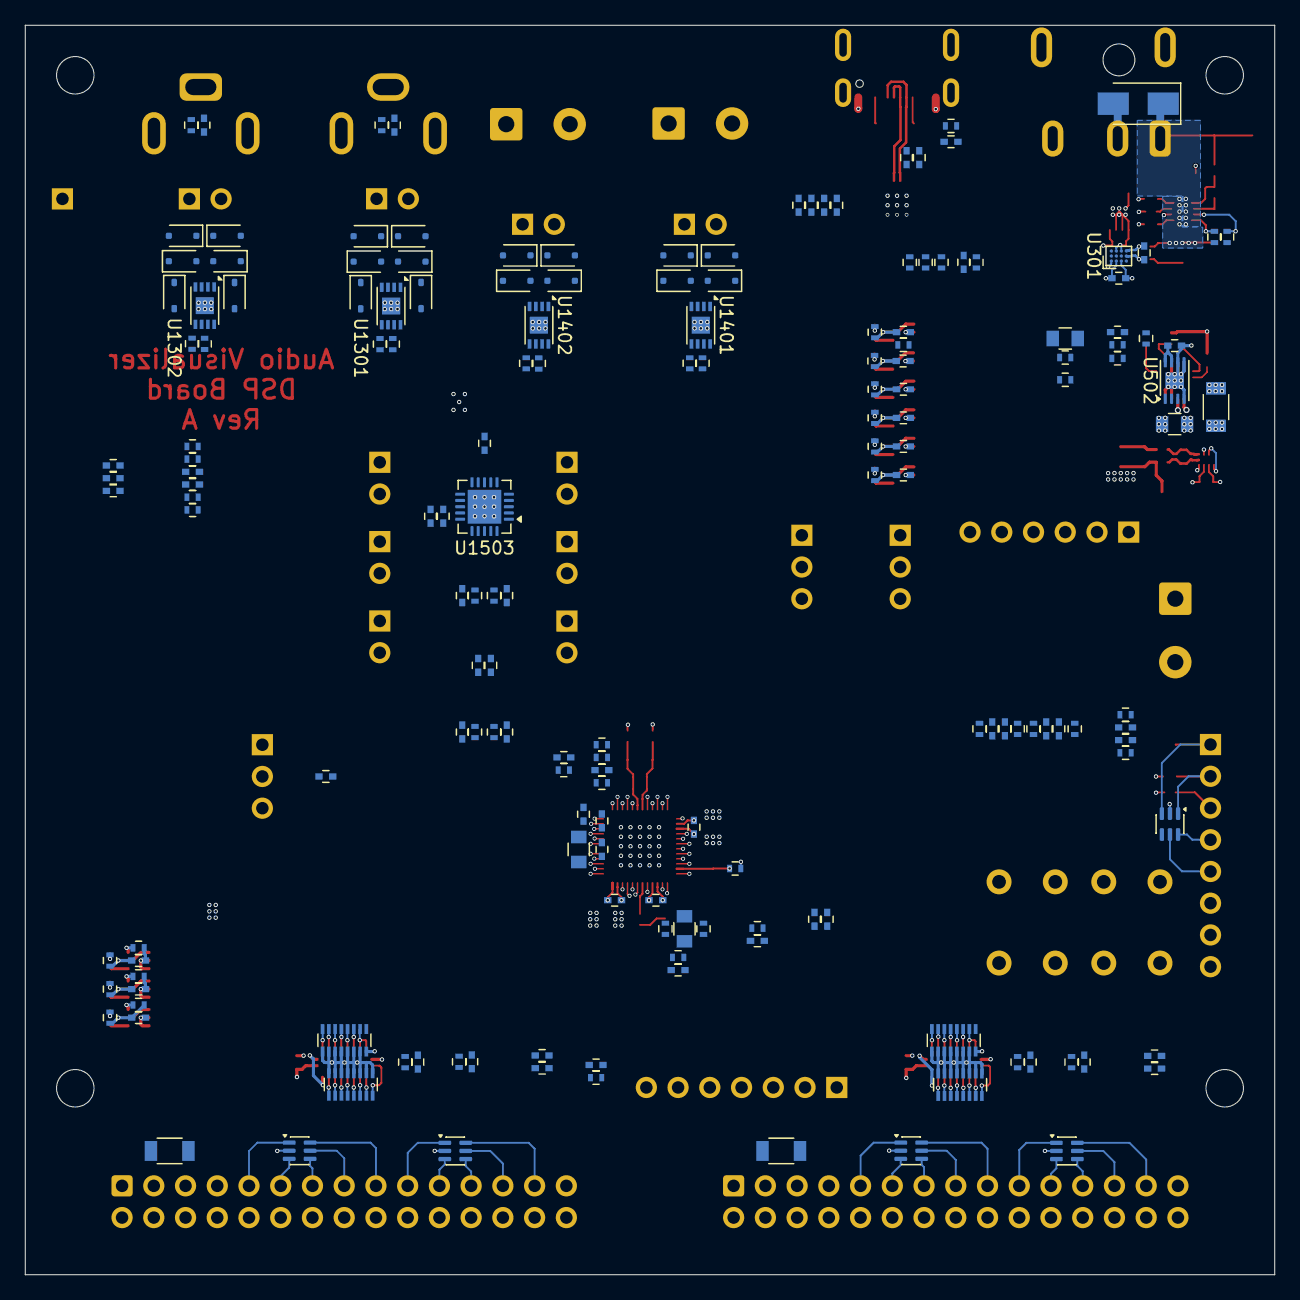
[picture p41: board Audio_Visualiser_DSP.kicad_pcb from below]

Board: 6 copper layers, 100.0 x 100.0 mm, 397 parts (172 on the bottom side), 205 nets.

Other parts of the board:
kobee-studio-6AC9B5DF: Kobee Studio; kobee-studio-6AC9B5DF
kobee-studio-6AC9B6E1: Kobee Studio; kobee-studio-6AC9B6E1
kobee-studio-6AC9B68A: Kobee Studio; kobee-studio-6AC9B68A
kobee-studio-6AC9B610: Kobee Studio; kobee-studio-6AC9B610
kobee-studio-6AC9BEC0: Kobee Studio; kobee-studio-6AC9BEC0
kobee-studio-6AC9BED8: Kobee Studio; kobee-studio-6AC9BED8
kobee-studio-6AC9C1C7: Kobee Studio; kobee-studio-6AC9C1C7
kobee-studio-6AC9C77D: Kobee Studio; kobee-studio-6AC9C77D
kobee-studio-6ACA8F55: Kobee Studio; kobee-studio-6ACA8F55

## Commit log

2026-09-17 Began DSP board design, created dsPIC symbol
    [Audio_Visualiser_DSP.kicad_pcb, Audio_Visualiser_DSP.kicad_sch, dsPIC33AK256MPS103_pinout.xlsx]
2026-09-19 began DSP board schematic
    [Audio_Visualiser_DSP.kicad_sch, POS12_power_input.kicad_sch, POS12_telemetry.kicad_sch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]
2026-09-19 added a bunch of schematic shit
    [Audio_Visualiser_DSP.kicad_sch, POS12_power_input.kicad_sch, POS12_telemetry.kicad_sch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]
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2026-09-22 lots of early schematic progress
    [Audio_Visualiser_DSP.kicad_sch, dspic33_gpio.kicad_sch, dspic33_power.kicad_sch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]
2026-09-22 added a ton of circuitry in schematic, new USB UART bridge, other random stuff
    [Audio_Visualiser_DSP.kicad_sch, POS12_power_input.kicad_sch, POS12_telemetry.kicad_sch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]
2026-09-23 consolidating signal input sheets, added active lowpass filters
    [Audio_Visualiser_DSP.kicad_sch, dspic33_gpio.kicad_sch, filtering_pgas.kicad_sch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]
2026-09-24 Changed to 48 pin dsPIC
    [dspic33_gpio.kicad_sch, dspic33_power.kicad_sch, filtering_pgas.kicad_sch]
2026-09-24 Added a ton of shit. I2C digipots, adjustable gain op amps, broke out audio references
    [Audio_Visualiser_DSP.kicad_sch, POS12_power_input.kicad_sch, POS3P3_power_supply.kicad_sch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]
2026-09-26 changed to inverting adjustable ain op amp
    [Audio_Visualiser_DSP.kicad_sch, rca_signal_conditioning.kicad_sch, source_selection_pgas.kicad_sch]
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2026-09-26 Added pushbuttons, some other blank pages
    [Audio_Visualiser_DSP.kicad_sch, anti_alias_filtering.kicad_sch, audio_voltage_references.kicad_sch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]
2026-09-26 moved pushbuttons to correct sheet
    [led_panel_connectors.kicad_sch, mechanical.kicad_sch, pushbuttons.kicad_sch]
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2026-09-26 Added some spice models
    [POS12_power_input.kicad_sch, POS12_telemetry.kicad_sch, POS3P3_power_supply.kicad_sch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]
2026-09-26 added simulation, changed LPF VCC to +5V
    [POS12_power_input.kicad_sch, POS12_telemetry.kicad_sch, POS3P3_power_supply.kicad_sch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]
2026-09-27 more signal chain development and simulation
    [anti_alias_filtering.kicad_sch, audio_voltage_references.kicad_sch, pushbuttons.kicad_sch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]
2026-09-27 changed to MCP6024 op amps for rail to rail inputs. Further simulated signal chain
    [anti_alias_filtering.kicad_sch, filtering_pgas.kicad_sch, rca_signal_conditioning.kicad_sch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]
2026-09-28 added LED panel buffers
    [Audio_Visualiser_DSP.kicad_sch, led_panel_buffers.kicad_sch, led_panel_connectors.kicad_sch]
2026-09-29 added rotary encoder circuitry
    [POS12_power_input.kicad_sch, POS12_telemetry.kicad_sch, POS3P3_power_supply.kicad_sch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]
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2026-10-01 cleared stale digikey part numbers
    [POS12_power_input.kicad_sch, POS12_telemetry.kicad_sch, POS3P3_power_supply.kicad_sch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]
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2026-10-01 assigned many digi-key part numbers
    [POS12_power_input.kicad_sch, POS12_telemetry.kicad_sch, POS3P3_power_supply.kicad_sch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]
2026-10-01 fixed dsPIC pinout to add exposed pad, fixed footprint mapping. Fixed +12V connection to INA
    [POS12_telemetry.kicad_sch, dspic33_gpio.kicad_sch, dspic33_power.kicad_sch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]
2026-10-03 started speaker signal conditioning
    [speaker_signal_conditoning.kicad_sch]
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2026-10-03 updated RCA jack footprint to fix KiCad github CI job failures
    [dspic33_gpio.kicad_sch, dspic33_power.kicad_sch, usb_uart_bridge.kicad_sch]
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2026-10-04 Added a bunch of stuff to the schematic
    Moved to adafruit I2C rotary encoder module. Added signal test points. Added some design schematic notes. Added LEd output connector ESD diodes. Consolidated on a single schottky diode. Connected mos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
    [POS3P3_power_supply.kicad_sch, dspic33_gpio.kicad_sch, dspic33_power.kicad_sch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]
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2026-10-06 Change RCA input signal paths to use instrumentation amp instead of AC coupling cap
    [rca_signal_conditioning.kicad_sch, speaker_signal_conditoning.kicad_sch]
2026-10-06 Updated RCA instrumentation amp designs to allow for RCA differential input signallin
    [rca_signal_conditioning.kicad_sch]
2026-10-06 Revert "Updated RCA instrumentation amp designs to allow for RCA differential input signallin"
    This reverts commit 545c2365b30f679610286f18356028039a58589e.
    [rca_signal_conditioning.kicad_sch]
2026-10-06 Revert "Change RCA input signal paths to use instrumentation amp instead of AC coupling cap"
    This reverts commit f4dee5b3753607e11cfd8388ae674b9233847bc3.
    [rca_signal_conditioning.kicad_sch, speaker_signal_conditoning.kicad_sch]
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2026-10-07 Changed reference design to use op amp buffering. Changed speaker level signal divider to divide to reference voltages, not GND
    [POS3P3_power_supply.kicad_sch, audio_voltage_references.kicad_sch, dspic33_gpio.kicad_sch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]
2026-10-07 changed RCA signal path to use in-amps instead of AC coupling caps, removing high pass filter
    [anti_alias_filtering.kicad_sch, rca_signal_conditioning.kicad_sch, source_selection_pgas.kicad_sch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]
2026-10-07 Add audio signal path test points, fix development variant excludes
    [POS12_telemetry.kicad_sch, POS3P3_telemetry.kicad_sch, anti_alias_filtering.kicad_sch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]
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2026-10-07 updated simulations with new audio signal circuits. Restored SD15C spice model
    [anti_alias_filtering.kicad_sch, audio_voltage_references.kicad_sch, rca_signal_conditioning.kicad_sch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]
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2026-10-08 add footprint for efuse, change PSU part number to 5A brick
    [POS12_power_input.kicad_sch]
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2026-10-09 fix a lot of digikey pns which are out of stock, find alternate inductors, change I2C buffers
    [POS3P3_power_supply.kicad_sch, dspic33_gpio.kicad_sch, dspic33_power.kicad_sch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]
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2026-10-09 Consolidated onto a single project library
    This commit combines all schematic symbols, pcb footprints, and 3d models into a single project library for portability. Still have a few 3d models to add yet. It also removes each individual custom 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
    [Audio_Visualiser_DSP.kicad_pcb, CP_EIA-7343-43_Kemet-X.step, DFN-8-1EP_3x2mm_P0.5mm_EP1.3x1.5mm.step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]
2026-10-09 Fixed ERC issues
    Placed many power flags, fixed refdes errors, fixed net naming issues. Added more test points
    [Audio_Visualiser_DSP.kicad_pcb, POS12_power_input.kicad_sch, audio_voltage_references.kicad_sch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]
2026-10-09 started placing parts in PCB, defined board outline
    [Audio_Visualiser_DSP.kicad_pcb, led_panel_buffers.kicad_sch]
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2026-10-09 update USB C shield GNDing scheme. Update CI job to fail if design content isnt in project library
    [Audio_Visualiser_DSP.kicad_pcb, usb_uart_bridge.kicad_sch]
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2026-10-10 expanded board edge, placed mount holes and IO connectors
    [Audio_Visualiser_DSP.kicad_pcb, led_panel_connectors.kicad_sch]
2026-10-10 Starting placing higher level blocks within board outline
    [Audio_Visualiser_DSP.kicad_pcb]
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2026-10-10 Placed some amps, added test points and silkscreen
    [Audio_Visualiser_DSP.kicad_pcb]
2026-10-10 CI: allow "not in schematic" footprints outside the project library
    Board-only footprints (custom silkscreen art, logos) have no schematic
    symbol, so the project_lib check no longer requires them to come from
    project_lib. Their 3D model paths are still checked.
    Claude-Session: https://claude.ai/code/session_01G4HnUnMMWFxfeb3Cv4jCPh
2026-10-10 fix CI job to not fail on silkscreen footprints. Place LPFs
    [Audio_Visualiser_DSP.kicad_pcb]
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2026-10-10 Finish placing components on board. Revert test point custom footprints. Add board render gif
    [Audio_Visualiser_DSP.kicad_pcb]
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2026-10-10 update CI job to add visual diff on each pipeline,
    [Audio_Visualiser_DSP.kicad_pcb]
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2026-10-10 add GND vias in a lot of QFNs
    [Audio_Visualiser_DSP.kicad_pcb]
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2026-10-10 fix silkscreen text width
    [Audio_Visualiser_DSP.kicad_pcb]
2026-10-10 deleted some junk files from spinrender which were not needed, causing plugin conflicts
    [Audio_Visualiser_DSP.kicad_pcb]
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2026-10-14 changed to 8 layers, routed some more controlled impedance/noise sensitive stuff, sandwhiched with GND
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

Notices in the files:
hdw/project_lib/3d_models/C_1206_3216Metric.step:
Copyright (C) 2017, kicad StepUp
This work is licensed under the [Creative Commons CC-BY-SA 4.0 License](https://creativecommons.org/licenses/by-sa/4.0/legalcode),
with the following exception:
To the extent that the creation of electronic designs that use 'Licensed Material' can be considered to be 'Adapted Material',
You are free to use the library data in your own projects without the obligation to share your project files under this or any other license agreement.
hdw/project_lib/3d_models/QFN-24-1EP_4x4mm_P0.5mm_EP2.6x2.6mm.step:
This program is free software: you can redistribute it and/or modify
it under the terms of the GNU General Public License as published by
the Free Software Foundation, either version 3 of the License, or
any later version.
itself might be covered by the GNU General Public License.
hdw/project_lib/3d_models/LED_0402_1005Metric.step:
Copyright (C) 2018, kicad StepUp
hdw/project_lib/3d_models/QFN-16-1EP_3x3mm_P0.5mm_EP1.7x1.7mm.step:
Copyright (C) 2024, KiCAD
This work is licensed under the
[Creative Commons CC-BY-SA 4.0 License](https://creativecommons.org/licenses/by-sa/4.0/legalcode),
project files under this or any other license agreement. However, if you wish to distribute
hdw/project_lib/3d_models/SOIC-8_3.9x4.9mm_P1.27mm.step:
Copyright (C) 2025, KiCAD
